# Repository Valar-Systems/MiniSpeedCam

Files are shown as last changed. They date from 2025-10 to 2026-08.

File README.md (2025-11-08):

# MiniSpeedCam

## Intro
The MiniSpeedCam tracks vehicle speeds, takes a photo, and uploads the photo and speed data to a server. Use it to track vehicle speeds on your driveway or street.

**Please sign up to the waitlist at [minispeedcam.com](https://minispeedcam.com/) if you're interested in purchasing one. We have not began manufacturing these yet.**

<div style="text-align: center;">
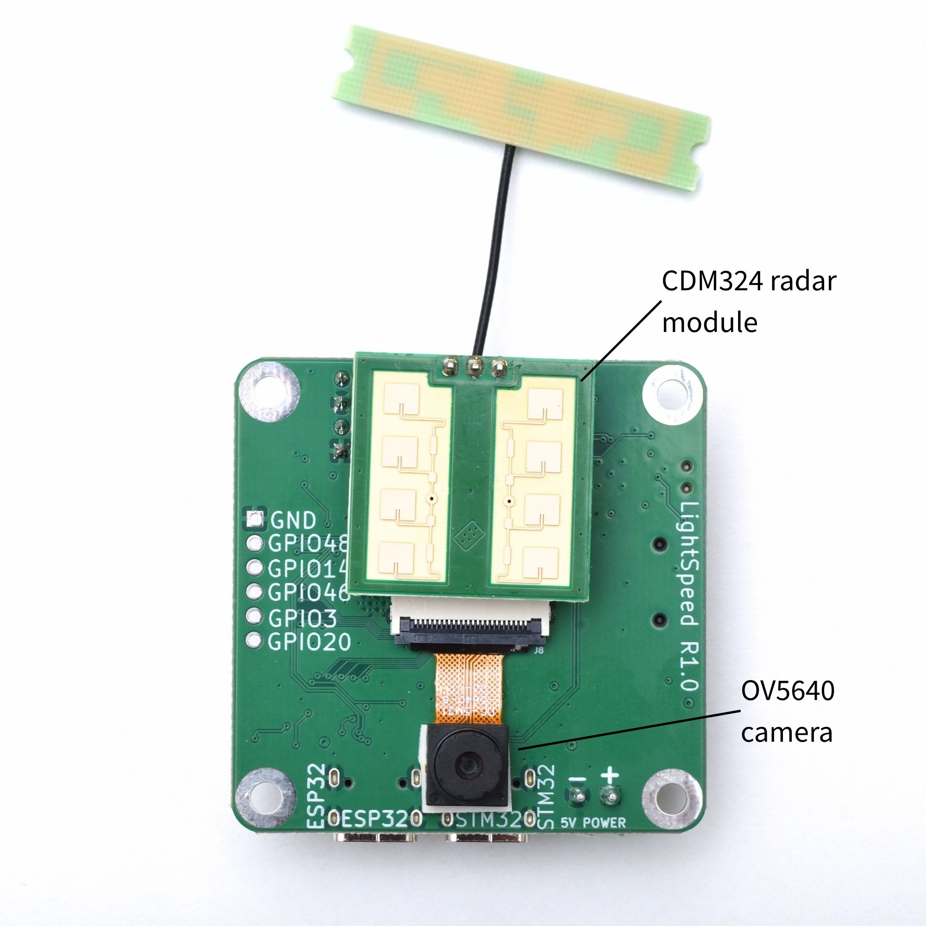
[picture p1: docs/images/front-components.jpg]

</div>
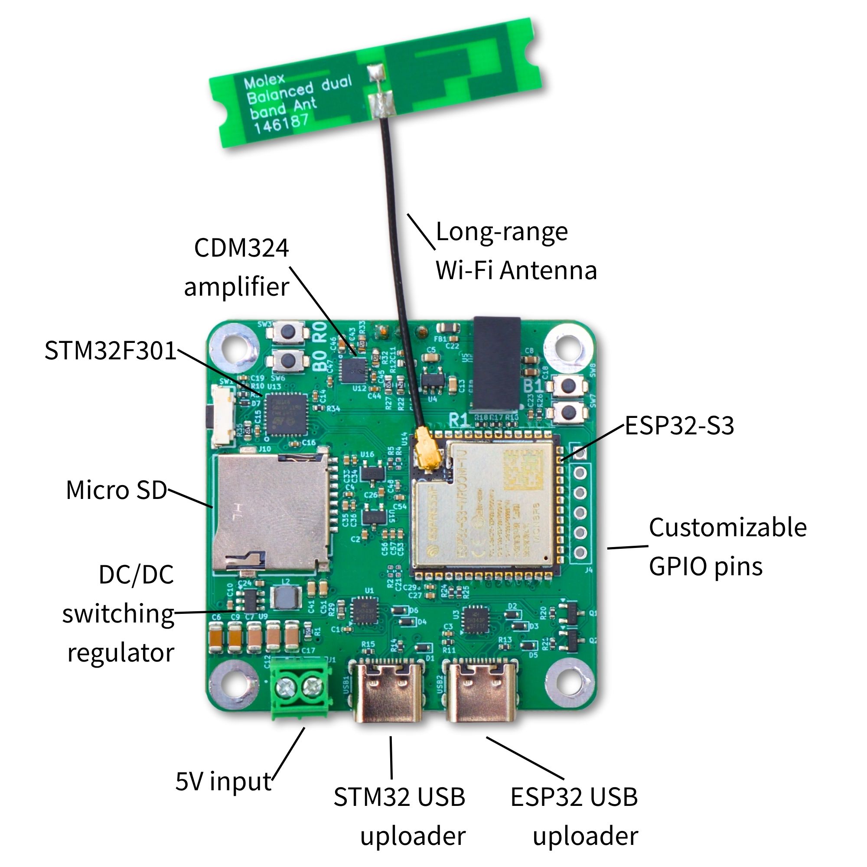
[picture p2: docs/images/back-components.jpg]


The firmware is designed to work with [minispeedcam.com](https://minispeedcam.com/) and requires **absolutely no coding or flashing.** The device works right out of the box.

The device creates a WiFi access point when started for the first time. Connect to it with your phone or laptop and enter your WiFi credentials. It will automatically connect to the internet.

All photos and speed data is sent to your account on [minispeedcam.com](https://minispeedcam.com/) where the data can be viewed and downloaded.

If you prefer to use your own server, just modify the Arduino code to point to wherever you'd like. It's completely open-source.

## Special thanks

This device wouldn't be possible without the help of [Mathieu (aka Limpkin)](https://www.limpkin.fr/index.php?post/2022/03/31/CDM324-Doppler-Motion-Sensor-Backpack%2C-now-with-FFTs%21). Thank you for your CDM324 Backpack and your generous help in getting MiniSpeedCam made.

## Accuracy and distance

A 100Hz frequency from the CDM324 corresponds to 2.3km/h speed. By using a tuning fork, we can trick the radar sensor into picking up a specific speed. Using a tuning fork with a frequency of 2048 Hz should trigger a speed reading of 47.1 kph or 29.3 mph ((2048/100) x 2.3)

[Here's a short video](https://youtu.be/ftSh7Fsy7hw) of the tuning fork in action.

Max distance is about 100ft or 30m

## How it works

The device uses the CDM324 which output a very small voltage, depending on how fast the vehicle is traveling. This voltage is amplified by the aplification circuit and sent to the STM32 for processing. The STM32 uses FFT to determine the speed of the vehicle.

The ESP32 handles the speed data, camera, and WiFi. It is connected to the STM32 via UART and polls it for speed data. Once the speed crosses a threshold that you set, the ESP32 takes a photo and sends a POST API call to a server with the data and image encoded in base64. The vehicles maximum speed, image, and date/time are then saved to a server.

## Battery operation

The device consumes about 1.10W while in full operation, and about 0.55W while in sleep mode. The radar sensor is always on, thus consuming 0.55W at all time. When movement is detected, the ESP32 wakes up from light sleep mode, turns on the camera, connects to wifi, takes a photo, sends the data, and goes back to sleep. The process takes about 10 seconds from start to finish. Battery life will depend on how many vehicles the sensor picks up, thus determing how often the ESP32 wakes up. The more vehicles on the road, the larger the battery drain will be.

## Power source

MiniSpeedCam runs on 5V. There are two USB-C ports and a screw terminal that can be used to supply 5V power. The easiest way to power this device is to use an external battery pack with a USB-C cable and plug it into either USB-C plug.

## Reflashing the device

Flashing the firmware is very simple. The STM32 is programmed in STM32 Cube IDE and the ESP32 is programmed in Arduino IDE.  

#### STM32 flashing

First plug your USB cable into the STM32 USB port. Then use the stm32loader python module directly :

```
pip install stm32loader
```

... then with the USB connected to the device (as it uses RTS/CTS signals to control the MCU nRESET and BOOT0 pins):

```
stm32loader -b 115200 -p com_port -e -w -v -s -f F3 MiniSpeedCam.bin
```

If uploading fails, you may use the STM32 Flash loader after performing the following toggling sequence:

1. Press the R0 button
2. Press the B0 button
3. Release R0
4. Release B0

#### ESP32 flashing

Open the Arduino sketch in ArduinoIDE. Be sure you have the libraries at the top of the sketch installed. And be sure your upload options are set up according to the image file in the ESP32_firmware folder.

Optional: ArduinoOTA is also included, allowing you to remotely flash the device from the ArduinoIDE. One caveat is the ESP32 goes to sleep after 10 minutes of being powered on. Just cycle the power to it and you'll have 10 minutes to upload your sketch.

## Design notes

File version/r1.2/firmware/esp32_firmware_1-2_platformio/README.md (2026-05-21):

# MiniSpeedCam ESP32 Firmware (PlatformIO)

PlatformIO port of the Arduino sketch at
[../esp32_firmware_1-2/esp32_firmware_1-2.ino](../esp32_firmware_1-2/esp32_firmware_1-2.ino).

Functionality is identical; the only changes are project layout (a `src/` tree
with paired `.h`/`.cpp` modules and `extern` globals) so the project builds
under PlatformIO without relying on Arduino IDE's multi-tab `.ino`
preprocessor.

## Layout

```
esp32_firmware_1-2_platformio/
├── platformio.ini      Build environment (board, partitions, lib_deps)
└── src/
    ├── main.cpp        Arduino setup()/loop() + dual-core tasks
    ├── pins.h          GPIO assignments for board revision 1.2
    ├── variables.h     Shared state grouped into POD structs (see below)
    ├── variables.cpp   One-definition home for the struct instances
    ├── camera.{h,cpp}  OV2640 init + JPEG capture (base64-encoded)
    ├── radar.{h,cpp}   UART protocol with the STM32 radar MCU
    ├── api.{h,cpp}     WiFi bring-up + HTTPS uploads to minispeedcam.com
    ├── espui_settings.{h,cpp}  Web-UI controls + NVS persistence
    ├── ota.{h,cpp}     ArduinoOTA listener + transfer-state flag
    ├── diagnostics.{h,cpp}  Boot reason / boot count / uptime / last upload
    └── queue.{h,cpp}   LittleFS-backed offline event queue (retry on WiFi return)
```

### Shared state

Globals live in `variables.h` as five small POD structs, each instantiated
once in `variables.cpp`. The Core 1 (radar) task writes the radar/sleep
side and raises flags on `upload`; the Core 0 (network) task drains them
and consumes `net` for WiFi.

| Instance | Type | Contents |
|---|---|---|
| `radar` | `RadarState` | `speed`, `maxSpeed`, `min_speed`, `photo_speed`, `is_kph` |
| `sleep_gate` | `SleepGate` | post-boot grace + measurement blanking windows |
| `upload` | `UploadJob` | Core 1 -> Core 0 flags + photo payload |
| `net` | `NetConfig` | persisted WiFi creds + camera id + local IP |
| `ui_ids` | `EspuiHandles` | ESPUI control IDs for the credential text inputs |
| `preferences`| `Preferences`  | NVS-backed key/value store |

## Build / flash

```sh
pio run                 # compile
pio run -t upload       # flash over USB
pio device monitor      # 115200 baud
```

## Board options

The defaults in `platformio.ini` target an **ESP32-S3-WROOM-1-N8R8**
(8 MB flash, 8 MB OPI PSRAM). For different modules edit:

| `platformio.ini` key | Typical value |
|---|---|
| `board_build.arduino.memory_type` | `qio_opi` (OPI PSRAM) |
| `board_upload.flash_size` | `8MB` / `16MB` |
| `board_build.partitions` | `default_8MB.csv` (OTA) |

If the board uses the on-chip native USB rather than a USB/UART bridge,
uncomment the `ARDUINO_USB_MODE=1` and `ARDUINO_USB_CDC_ON_BOOT=1`
lines in `build_flags` so the serial console works without an external
adapter.

## Dependencies

Pulled automatically via `lib_deps`:

- `s00500/ESPUI @ 2.2.4` - web configuration portal
- `esp32async/AsyncTCP @ 3.3.8` - async networking (ESPUI dependency)

`esp_camera`, `WiFi`, `WiFiClientSecure`, `HTTPClient`, `Preferences`,
`ESPmDNS`, and `DNSServer` are provided by the `espressif32` platform's
Arduino framework and need no entry.

## Over-the-air updates (ArduinoOTA)

The partition table (`default_8MB.csv`) gives the bootloader two app
slots, `app0` and `app1` (~3.25 MB each), and an `otadata` partition
that records which one is currently active. ArduinoOTA writes the
incoming image into the inactive slot, then flips `otadata` so the
next boot launches the new firmware. NVS sits at the same `0x9000`
offset as the previous `huge_app.csv` layout, so stored WiFi
credentials survive the partition-table switch the first time.

**Pushing an update from PlatformIO**

The first flash after switching to this partition table must be over
USB (`pio run -t upload`) because the partition table itself changes.
After that, push subsequent firmware images over the LAN:

```sh
# Discoverable as MiniSpeedCam.local once mDNS is up
pio run -t upload --upload-port MiniSpeedCam.local
# Or by IP if mDNS isn't reachable:
pio run -t upload --upload-port 192.168.1.42
```

PlatformIO auto-detects ArduinoOTA from the `.local` / IP form and
calls `espota.py` under the hood. Use the same password defined by
`OTA_PASSWORD` (default `minispeedcam`); set
`upload_flags = --auth=<password>` in `platformio.ini` to bake it into
the upload command. To change the password:

```ini
build_flags  = ... -DOTA_PASSWORD=\"my-secret\"
upload_flags = --auth=my-secret
```

**Behaviour during a transfer**

When `ArduinoOTA.onStart` fires, [ota.cpp](src/ota.cpp) sets the global
`g_ota_in_progress` flag and calls `esp_camera_deinit()` to release the
camera driver's DMA descriptors and PSRAM framebuffer. The radar task
(Core 1) and the upload task (Core 0) both check that flag at the top
of their loops and back off so they don't fight the flash writer for
memory or bandwidth. When the transfer finishes the library calls
`ESP.restart()`, which brings up the new image with a clean camera
init via the normal `setup()` path.

## Photo upload path

The speeding-event photo POST never materialises the encoded JPEG in
regular heap. Capture leaves the JPEG in the camera driver's PSRAM
framebuffer; an opaque pointer lives in an atomic slot owned by
[camera.cpp](src/camera.cpp). The Core 0 uploader feeds the framebuffer
into a `StreamingUploadBody` (in [api.cpp](src/api.cpp)) that emits the
JSON prologue, on-the-fly base64 chunks of the JPEG, and the JSON
epilogue as `HTTPClient::sendRequest()` pulls ~1.4 KB at a time into
its TCP write buffer. Peak heap during upload is therefore dominated
by the TCP buffer plus a couple of short Strings, not the photo.

Each upload now also carries an `event_time` epoch field (seconds since
1970, UTC). NTP sync is kicked off after every successful STA
association via `pool.ntp.org`; until the first NTP packet lands, the
field is sent as `0` and the server falls back to receive-time.

## Offline event queue

When the live upload path can't deliver an event (no WiFi, transient
server error, rate-limit), the JPEG + metadata is written to LittleFS
under `/queue/NNNNNNNN.bin` via [queue.cpp](src/queue.cpp). On every
Core 0 iteration (throttled to ~30 s) and on every WiFi reconnect, the
queue is drained oldest-first; events that POST successfully are
deleted, the first failure aborts the drain so we don't hammer a
broken endpoint. The queue lives in the 1.5 MB `spiffs` partition
reserved by `default_8MB.csv`, giving room for ~15 full-resolution
JPEGs of typical size.

The Status tab in the web UI shows the pending queue depth so you can
tell at a glance whether the device is keeping up with delivery.

## Web UI

Three tabs at the device's IP (`MiniSpeedCam.local` over mDNS):

- **Device** - MPH/KPH switch, min speed, photo speed, *Service Mode*
  (keep awake / no sleep so OTA stays reachable), JPEG quality (0-63),
  Frame size (QVGA through UXGA).
- **Wifi Settings** - Network SSID / password, Camera ID, OTA password,
  Clear Settings, Save Settings (reboots).
- **Status** - Live diagnostics, refreshed ~1 Hz from `taskCore0`:
  current speed, free heap and PSRAM, uptime, WiFi RSSI and IP, last
  upload HTTP code, pending queue depth, last reset reason, boot count.

## Power management

When neither *Service Mode* is on nor the post-boot grace window is
active, the firmware enters `esp_light_sleep_start()` after 5 s of zero
radar activity. Before each sleep the OV2640 is fully released
(`esp_camera_deinit()` + PWDN high) so the sensor draws no current
during sleep; on wake (ESP_WAKEUP_PIN going high), the camera is
re-initialised. Combined with WiFi being torn down across sleep
cycles, idle current drops substantially compared to the previous
"sleep but leave the camera live" path.

## TLS

`api.cpp` defines a `kCaRootCert` string; if non-empty it is fed to
`WiFiClientSecure::setCACert()` so HTTPS uploads validate against the
pinned root. Out of the box it is empty, falling back to
`setInsecure()` (the legacy behaviour). To enable validation, paste
the PEM-encoded root that signs `minispeedcam.com` over the placeholder
and rebuild. Fetch it with:

```sh
openssl s_client -connect minispeedcam.com:443 -showcerts < /dev/null
```

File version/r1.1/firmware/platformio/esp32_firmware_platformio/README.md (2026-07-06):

# MiniSpeedCam ESP32 Firmware r1.1 (PlatformIO)

PlatformIO port of the Arduino sketch at
[../esp32_firmware/esp32_firmware.ino](../esp32_firmware/esp32_firmware.ino).

Functionality is identical to the original sketch. The only change is project
layout: the sketch body becomes `src/main.cpp` and the original multi-tab
header modules move under `src/` unchanged. They are still compiled as a
single translation unit (`main.cpp` `#include`s them in the same order the
Arduino IDE concatenated the `.ino` tabs), so there is no behavioural
difference — this is purely so the project builds under PlatformIO without
relying on the Arduino IDE's `.ino` preprocessor.

> For the newer, fully-modularised layout (paired `.h`/`.cpp`, `extern`
> globals, OTA, offline queue, diagnostics) see
> [../../../r1.2/firmware/esp32_firmware_1-2_platformio](../../../r1.2/firmware/esp32_firmware_1-2_platformio).

## Layout

```
esp32_firmware_platformio/
├── platformio.ini          Build environment (board, partitions, lib_deps)
└── src/
    ├── main.cpp            GPIO/pin defines + setup()/loop() + dual-core tasks
    ├── config.h            Bearer token + optional TLS root cert (build-flag overridable)
    ├── variables.h         Shared state + the Core 1 -> Core 0 upload queue
    ├── camera.h            OV2640 init + JPEG capture (framebuffer kept for streaming)
    ├── radar.h             UART protocol with the STM32 radar MCU
    ├── api.h               WiFi bring-up + streaming HTTPS upload to minispeedcam.com
    ├── diagnostics.h       Reset reason / boot count / uptime / last-upload code
    ├── camera_stream.h/.cpp  Temporary MJPEG "aiming" stream (esp_http_server on :81)
    └── config_portal.h     Self-hosted web config page (esp_http_server on :80) + JSON API + NVS persistence
```

## Build / flash

```sh
pio run                 # compile
pio run -t upload       # flash over USB
pio device monitor      # 115200 baud
```

## Board options

The defaults in `platformio.ini` target an **ESP32-S3-WROOM-1-N8R8**
(8 MB flash, 8 MB OPI PSRAM). For different modules edit:

| `platformio.ini` key | Typical value |
|---|---|
| `board_build.arduino.memory_type` | `qio_opi` (OPI PSRAM) |
| `board_upload.flash_size` | `8MB` / `16MB` |
| `board_build.partitions` | `huge_app.csv` (3 MB app) |

If the board uses the on-chip native USB rather than a USB/UART bridge,
uncomment the `ARDUINO_USB_MODE=1` and `ARDUINO_USB_CDC_ON_BOOT=1` lines in
`build_flags` so the serial console works without an external adapter.

## Dependencies

Pulled automatically via `lib_deps`:

- `bblanchon/ArduinoJson @ ^7.2.0` - config portal `/api/state` JSON + POST bodies, and the OTA manifest

`esp_camera`, `esp_http_server` (both HTTP servers — config portal :80 and
aiming stream :81), `WiFi`, `WiFiClientSecure`, `HTTPClient`, `Preferences`,
`ESPmDNS`, `DNSServer`, and `SPIFFS` are provided by the `espressif32`
platform's Arduino framework and need no entry. The JPEG is base64-encoded
with the core's `base64::encode()` (`cores/esp32/base64.h`), so no base64
library is required either. There is no ESPUI / ESPAsyncWebServer / AsyncTCP
dependency — the config page is hand-rolled HTML served from flash.

## Configuration

Deployment values live in [src/config.h](src/config.h) and can be overridden
at build time (so you don't have to edit source) via `build_flags` in
`platformio.ini`:

| Macro | Default | Purpose |
|---|---|---|
| `API_BEARER_TOKEN`  | the shared minispeedcam.com key  | `Authorization: Bearer` token for the uploads |
| `API_CA_ROOT_CERT`  | empty | PEM root cert for TLS validation |

```ini
build_flags =
    ...
    -DAPI_BEARER_TOKEN=\"my-token\"
```

**TLS:** with `API_CA_ROOT_CERT` empty, HTTPS uploads use `setInsecure()`
(no certificate validation — the original behaviour). Paste the PEM root that
signs `minispeedcam.com` into `config.h` (or pass it via the build flag) to
enable validation:

```sh
openssl s_client -connect minispeedcam.com:443 -showcerts </dev/null
```

The default token is a shared Bubble.io workflow key, not a per-device secret;
it already exists in this repo's git history, so rotate it server-side if it
ever needs to be private.

## Capture & upload path

Core 1 (radar) and Core 0 (network) hand work off through a FreeRTOS queue
(`uploadQueue`) rather than polled flags:

1. While a vehicle is in range (`speed >= min_speed`), Core 1 tracks the run's
   max speed and, once `maxSpeed >= photo_speed`, captures **one** JPEG and
   keeps its PSRAM framebuffer.
2. When the run ends, Core 1 posts a single `UploadRequest{speed_actual,
   has_photo, fb}` to the queue.
3. Core 0 blocks on the queue, then POSTs to `server_capture`. When a photo is
   attached it is base64-streamed straight from the framebuffer by
   `StreamingUploadBody` (an `Arduino Stream` feeding
   `HTTPClient::sendRequest`), so the ~200 KB encoded image is never buffered
   in heap. Core 0 then returns the framebuffer.

Every run uploads exactly once: a full photo POST when speeding, or a short
speed-only POST otherwise (the `send_photo` JSON field tells the server which).
The camera is configured with `fb_count = 2` so Core 1 can capture a new frame
while Core 0 is still streaming the previous one.

## Web UI

Self-hosted config page at the device's IP (`MiniSpeedCam.local` over mDNS),
served from flash by `esp_http_server` on port 80 (`config_portal.h`):

- **Device** — live Current Speed readout, MPH/KPH switch, Power-Saver Mode
  switch (drop WiFi when idle vs. never sleep), minimum speed, photo speed, and
  the proximity/photo-signal thresholds.
- **Aiming stream** — toggle the temporary MJPEG video feed (port 81) for
  mounting.
- **WiFi & data server** — Network SSID / password, Data Server API base URL,
  Save (reboots), Clear Settings (reboots into the setup AP).
- **Status** — live diagnostics: signal (proximity), free heap and PSRAM,
  uptime, WiFi RSSI and IP, last upload HTTP code, last reset reason, boot
  count, firmware versions, and OTA status.

There is no server-side push: the page polls `GET /api/state` (~1 Hz) for all
live values and writes settings back via small JSON `POST` endpoints
(`/api/settings`, `/api/wifi`, `/api/clear`, `/api/stream`). That replaced the
old ESPUI WebSocket broadcast from `taskCore1`, whose AsyncTCP send blocked the
radar task and froze the device under WiFi/stream load.

### `GET /api/events` — recent detections for LAN companions

A read-only feed of the most recent passes, so a display on the same network can
show recent speeds without the cloud (`events.h`, an in-RAM ring written at
run-end). The reference consumer is the Blipscope **Speedscope** edition. Shape:

```json
{ "kph": false, "count": 2,
  "events": [ { "speed": 31, "ageSec": 4, "mag": 1200, "dir": 1 },
              { "speed": 24, "ageSec": 47, "mag": 780, "dir": 2 } ] }
```

Newest first; `speed` is a whole number in the device's configured unit (`kph`
flag), `ageSec` is seconds since the pass (this board has no RTC — use it with
your own clock for absolute times), and `dir` is `0` unknown / `1` approaching /
`2` receding. CORS-open (`Access-Control-Allow-Origin: *`).

## Power management

**Power-Saver Mode** (Device tab, persisted in NVS, default **on**) gates the
radar loop's two idle paths: after the post-boot grace window, and after 5 s of
zero radar activity, the device drops WiFi (`WiFi.disconnect` + `WIFI_OFF`).
Turn it **off** to keep the device permanently awake with WiFi up (e.g. while
configuring or debugging) — toggling it off also triggers an immediate
reconnect so the web UI comes straight back. `esp_light_sleep_start()` is still
commented out in `taskCore1`, so today the saving is WiFi-off only.

## TODO

### Verify before relying on this build
- [ ] Hardware smoke-test the capture/upload path: confirm a speeding pass
      produces a well-formed streamed photo POST, and a pass between
      `min_speed` and `photo_speed` produces a valid speed-only POST.
- [ ] Confirm the `capture` endpoint accepts speed-only events (no `photo`
      object). Behaviour changed: **every** pass now uploads, not just speeding
      ones — gate the enqueue on `has_photo` in `taskCore1` if that's unwanted.

### Open decisions / known gaps
- [ ] Captive DNS is never started — `dnsServer.processNextRequest()` runs but
      `dnsServer.start(DNS_PORT, "*", apIP)` is never called, so the AP-mode
      portal redirect is inactive. Wire it up in `connectWifiAP()` or remove the
      unused `DNS_PORT`/`apIP`.
- [ ] Post-boot grace window: code uses `millis() + 10000` (10 s) while comments
      say 120 s — pick one and align code + comments.
- [ ] `speed`/`maxSpeed` are `int`, so `get_speed()`'s float is truncated.
      Decide whether sub-unit precision should be sent (server-contract change).
- [ ] Confirm `WIFI_RESET_PIN` needs the internal pull-up (now `INPUT_PULLUP`)
      vs. an external one on the board.

### Security
- [ ] Rotate the bearer token (it exists in git history) and/or supply it only
      via the `API_BEARER_TOKEN` build flag.
- [ ] Enable TLS validation by setting `API_CA_ROOT_CERT` (currently falls back
      to `setInsecure()`).

### Possible backports from r1.2
- [ ] OTA updates (ArduinoOTA + dual-app `default_8MB.csv` partition; pause the
      camera during a transfer).
- [x] Power-Saver Mode switch — toggle WiFi-drop on idle vs. never sleep
      (persisted, with immediate reconnect on disable). *(done)*
- [ ] Power management, deeper: re-enable `esp_light_sleep_start()` and
      `esp_camera_deinit()` on idle (still commented out in `taskCore1`), gated
      by the same Power-Saver Mode flag.
- [ ] Offline event queue (LittleFS) with retry, so a capture survives a failed
      upload / WiFi outage instead of being lost.
- [ ] UI-tunable camera (frame size / JPEG quality) in the Device tab.
- [x] Live diagnostics Status tab (heap, PSRAM, uptime, RSSI, IP, last upload,
      reset reason, boot count). *(done)*

### Maintenance
- [ ] Decide whether to port these fixes back into the original Arduino-IDE
      sketch at `../esp32_firmware/esp32_firmware.ino`.

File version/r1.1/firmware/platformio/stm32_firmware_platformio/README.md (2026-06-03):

# MiniSpeedCam STM32 firmware — PlatformIO port

This is a [PlatformIO](https://platformio.org/) build of the MiniSpeedCam
firmware for the **STM32F301K8U6** (Cortex-M4F, 64 KB Flash / 16 KB RAM),
ported from the original STM32CubeIDE project in [`../stm32_firmware`](../stm32_firmware).

It is functionally identical: the same application code, ST HAL drivers,
CMSIS-DSP, FatFs middleware, startup file and linker script are used. Only the
build system changed.

## Why a framework-less build

The project is configured **without** PlatformIO's `stm32cube` framework. Instead
it vendors the exact sources from the CubeIDE project. This guarantees the build
uses the same known-good HAL/CMSIS/DSP versions as the original — no risk of a
framework version mismatch or duplicate-symbol conflicts. PlatformIO only
provides the GNU Arm toolchain and orchestrates the build.

## Usage

```sh
pio run            # build  -> .pio/build/genericSTM32F301K8/firmware.{elf,bin,hex}
pio run -t upload  # flash via ST-Link (default)
pio run -t clean   # clean
pio run -t size    # memory usage
```

First run downloads the `toolchain-gccarmnoneeabi` package automatically.

## Layout

| Path | Origin |
|---|---|
| `Core/` | Application + CubeMX-generated code (`main.c`, IT handlers, MSP, syscalls, startup) |
| `Drivers/` | ST STM32F3xx HAL driver + CMSIS core/device + CMSIS-DSP |
| `FATFS/`, `Middlewares/` | FatFs glue layer and middleware |
| `STM32F301K8UX_FLASH.ld` | Original CubeIDE linker script (64 KB Flash / 16 KB RAM) |
| `boards/genericSTM32F301K8.json` | Custom board definition (the F301K8 is not a built-in PlatformIO board) |
| `link_flags.py`  | Mirrors the FPU / float-ABI / libc-specs flags onto the link stage |
| `platformio.ini` | Build configuration (flags & defines match the CubeIDE project verbatim) |

## Build configuration notes

- **MCU defines:** `USE_HAL_DRIVER`, `STM32F301x8`
- **CMSIS-DSP:** `ARM_MATH_CM4` plus the same `ARM_*_TABLES` config defines as the
  original project, so only the FFT/twiddle tables actually used are linked in.
- **ABI:** `-mcpu=cortex-m4 -mfpu=fpv4-sp-d16 -mfloat-abi=hard -mthumb` (hard float),
  `--specs=nano.specs --specs=nosys.specs`, `-Os`.

The original project (CubeIDE) remains untouched in `../stm32_firmware`; both can
coexist.

## Memory footprint (-Os)

```
Flash: ~44.6 KB / 64 KB  (~68%)
RAM:   ~15.7 KB / 16 KB  (~96%, incl. 0x200 heap + 0x400 stack reservation)
```

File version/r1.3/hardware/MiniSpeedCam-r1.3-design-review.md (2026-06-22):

# MiniSpeedCam r1.3 — PCB Design Review

**Valar Systems — Hardware Engineering** · Doc MSC-R1.3-DR-001 Rev A · 2026-06-22 · **CONFIDENTIAL**

Radar speed-camera motherboard (ESP32-S3 + STM32F301 + CDM324 24 GHz Doppler) · 4-layer, 50 × 50 mm
Repo: `Valar-Systems/MiniSpeedCam @ version/r1.3` · Method: kicad-happy analyzer suite

| Components | Stack | Routed | EMC risk | Errors / Warnings |
|---|---|---|---|---|
| 84 | 4-layer (F / GND / PWR / B), 1.6 mm | 100% | 13 / 100 | 7 / 31 |

---

## 1. Scope & Method

The open-source [kicad-happy](https://github.com/aklofas/kicad-happy) analyzer suite was run against the r1.3 KiCad source
(`version/r1.3/hardware/pcb/kicad/MiniSpeedCam-r1.3.{kicad_sch,kicad_pcb}`), and the results were triaged by hand against the raw
netlist. Findings carry the analyzer rule IDs.

| Analyzer | Status | Result |
|---|---|---|
| analyze_schematic.py | RAN | 84 parts, 92 nets, 36 unique — 1 error / 5 warnings / 37 info |
| analyze_pcb.py --full | RAN | 4-layer, 50×50 mm, fully routed (0 unrouted) — 6 errors / 26 warnings / 50 info |
| cross_analysis.py | RAN | 5 plane-integrity findings (GND / 3V3 fragmentation) |
| analyze_emc.py (US market) | RAN | 61 findings, EMC risk 13/100 (conservative) |
| analyze_gerbers.py | **SKIPPED** | **No Gerber/drill set exported yet** — copper/aperture/drill DFM not yet checked (release gate, see §6) |
| Datasheet verification | PARTIAL | Front-end supply/ground pins confirmed against the netlist (§7); op-amp signal-pin order is a designer check |
| analyze_thermal.py | PARTIAL | Ran, but no power-budget input → junction temps not computed |
| SPICE | SKIPPED | No simulator on host |

Layer stack: `F.Cu` / `In1.Cu = GND plane` / `In2.Cu = power plane` / `B.Cu`, 1.6 mm.

## 2. Executive Summary

The board is complete, fully routed, and mechanically tidy on a 50 × 50 mm 4-layer stack. The issue that matters most clusters around
one theme: **the sensitive 24 GHz Doppler analog front-end is not isolated from the digital/RF noise of the ESP32-S3.** The radar
amplifiers run from the digital `3V3` rail and reference the digital ground, and the isolated DC-DC that feeds the radar has its
secondary ground bonded straight back to digital `GND`. This is the kind of coupling that forces firmware-side mitigation — the
current firmware blanks the radar during WiFi bursts and runs WiFi at reduced TX power to keep readings usable. Fixing it in hardware
is the highest-value content for this board.

There is also **one power-architecture item worth a deliberate decision** (§3.2): **three power sources — the Phoenix inlet J1, the
barrel jack DC1, and USB-C VBUS (USB2) — land directly on the `5V` net** with no ORing / reverse-blocking shown. If two can be plugged
at once, that's a back-feed / contention path. The rest are standard pre-fab DFM and EMC hygiene items.

> **Top priority** — Give the radar amplifier chain (U4 LMP7731, U12 MAX9814) a dedicated low-noise analog supply and a single-point
> analog ground, instead of the shared digital `3V3` / `GND`. This is the change most likely to remove the need for firmware
> radar-blanking and let WiFi TX power return to full range.

## 3. Priority Findings

### 3.1 Radar Front-End Shares the Digital Supply & Ground (HIGH)

```
RADAR SUPPLY  [GOOD: dedicated, filtered diode rail]
  5V -> U5 B0505S (isolated DC-DC) -> +Vo (pin4)
        -> FB1 ferrite -> C22 bulk -> CDM324 V+

RADAR SIGNAL  [uV signal amplified on the noisy digital rail]
  CDM324 IF out -> C11/R12 (AC couple)
    -> U4 LMP7731 (gain)   [U4.5 (V+)  = 3V3]
    -> U12 MAX9814 (AGC)   [U12.2/5 (VDD) = 3V3]
    -> ADC

GROUND: single GND net (no analog island); U5 secondary 0V tied to GND
```

| Observation | Evidence (netlist) | Severity |
|---|---|---|
| Doppler amplifiers on shared digital rail | `U4.5 (V+) → 3V3` and `U12.2/5 (VDD) → 3V3` — the same rail the ESP32-S3 / STM32 logic runs on. `3V3` is sourced from the **U9 AP63203 *switching* regulator**, so the amps see switching ripple as well as WiFi-TX transients. Supply pins confirmed (§7). | **HIGH** |
| Isolated converter ground bonded to digital ground | `U5.1 (−Vin) → GND` and `U5.3 (0V) → GND`; no analog/isolated ground net exists. The B0505S isolation buys nothing for noise — the radar return shares digital ground. | **HIGH** |
| Diode rail done well | `U5.4 (+Vo) → FB1 → C22` then on to the CDM324 — a separate, ferrite-filtered radar supply. | OK |

**Recommended changes**

- Derive a clean analog rail for U4/U12 from the isolated B0505S `+Vo` via a small **low-noise (high-PSRR) LDO** — explicitly *not*
  the switcher-derived digital `3V3`.
- Give the front-end a local **analog ground island**, tied to digital `GND` at a **single star point** near the STM32 ADC return.
- Decide deliberately whether the B0505S secondary `0V` joins `GND` at one point (quiet) or stays isolated (true isolation). Today it's
  a common-ground bond, giving up most of the part's benefit.

*Note: `VOUT` is the MAX9814 audio output to the ADC, not a supply — so `RS-001 "VOUT has no source"` is a false positive (§8).*

### 3.2 Three Power Sources Merged on `5V` (MEDIUM)

The `5V` net is driven by **three inlets in parallel** — Phoenix `J1.1`, barrel jack `DC1.4`, and USB-C `USB2.VBUS (pins 2/11)` —
plus `U5.+Vin` and the `U9` switcher input all on the same node. The only series parts on the net are `D1` and `R1`.

- If a user can have **USB plugged *and* the barrel jack / Phoenix energized at the same time**, current can back-feed from one source
  into another; at minimum the host USB port sees the external supply on its VBUS.
- **Action:** add ideal-diode ORing or Schottky reverse-blocking per source (or a deliberate "external *or* USB, never both" mechanical
  interlock / 0Ω select). Confirm D1's role — if it's the only reverse protection it should sit on each source, not just the rail.

## 4. Ground / Plane Integrity & EMC

| Rule | Severity | Finding & action |
|---|---|---|
| PS-002 | WARN | `GND` resolves into **5 copper islands, 2 signals crossing (GPIO43, GPIO44)**; `3V3` into **22 islands, 2 crossing**. Verify `In1.Cu` is a continuous ground reference (no traces carved through it) and stitch the pours. 3V3 fragmentation matters because the analog amps reference 3V3. |
| GP-001 | ERROR (×2) | Two signals cross a significant reference-plane gap (plus several partial). Reroute to avoid the void, or add a bridge cap if a split is intentional. |
| RP-001 | ERROR (×2) | `CAM.PCLK` and `CAM.XCLK` change layers with **no return-path stitching via** (plus ~20 warning-level nets: camera data, UART, BOOT0). Add a ground via at each clock layer-transition. |
| IO-001 | ERROR (×2) | No EMC filtering near the DC inlets / USB. Add TVS + pi/ferrite on the **J1 Phoenix inlet** and the **DC1 barrel jack**; add common-mode choke + ESD on the **USB2** data pair. |
| CK-001 / CK-003 | WARN | Camera `XCLK`/`PCLK` and `SD_HOST_CLK` on outer layers, routed near connectors J8/J10 — move inner-layer or add guard ground. |
| DC-003 | WARN | ~13 decoupling caps (C6/C7/C9/C11/C12/C17/C42…) far from their plane via — shorten cap→via path to cut PDN inductance. |

EMC pre-compliance score **13/100** (conservative) — the analog-isolation and I/O-filtering gaps dominate.

## 5. DFM / Assembly

| Rule | Severity | Finding & action |
|---|---|---|
| FD-001 | ERROR | **No fiducials** either side (fine-pitch QFN present) — add ≥3 global fiducials. |
| PM-002 | ERROR | **C6 and FB1 sit 0.25 mm from board edge** — move in ≥0.5 mm (crack risk on depanel). J1/J3 overhang is intentional edge-mount; J4 at 0.52 mm is borderline. |
| TE-001 | WARN | **0 test points / 91 nets.** Add TPs on every rail, the radar analog output, and GND scope points. |
| DFM-001 | WARN | 0.1 mm / 0.116 mm trace+space forces JLC **advanced** tier. Relax non-camera nets to 0.127 mm to drop to standard if cost matters. |
| PM-001 | WARN | Courtyard overlaps (U15/C2, U16/C26, U15/C56) — decoupling caps deliberately under their LDOs; confirm and waive. |
| TV-001 | WARN | STM32 (U13) thermal pad has 5/9 recommended vias — top up to 9 (minor). |
| SS-001 | ERROR | MPN coverage **3/36 unique parts (8.3%)** in symbols — pre-fab sourcing blocker. Populate MPN fields from the LCSC numbers already in the symbols' `lcsc` property. |

## 6. Schematic / Release Items

| Rule | Severity | Finding & action |
|---|---|---|
| NT-001 | WARN | STM32 `U13.PA2` and `U13.PA3` are **single-pin (floating) bidirectional nets** — add wires or no-connect flags so ERC is clean and the pins aren't left undefined. |
| RS-001 / pwr_flag | WARN | `5V` (and `1V2` / `2V8` / `3V3`) carry power_in pins but have no `PWR_FLAG` / power_out — ERC housekeeping; add a `PWR_FLAG` on the inlets. |
| GERBER | GATE | **No Gerber/drill set committed.** Export the fab package and re-run `analyze_gerbers.py` before release — copper/aperture/drill DFM is otherwise unverified. |

## 7. Datasheet Verification

| Part | Pin checked | Result | Basis |
|---|---|---|---|
| U5 B0505S-1W | 1=−Vin, 2=+Vin, 3=−Vout(0V), 4=+Vout | CONFIRMED | Standard B0505S 4-pin isolated DC-DC. `−Vin` and `0V` both on `GND` verified in netlist. |
| U12 MAX9814 | 5=VDD, 6=MICOUT, 8=MICIN, GND=4/7/9/10/11/15 | CONFIRMED | MAX9814 14-pin TDFN. `VDD → 3V3` verified. |
| U4 LMP7731 | 5 = V+ | CONFIRMED | Pin 5 = V+ for SOT-23-5 single op-amp. `V+ → 3V3` verified. |
| U4 LMP7731 | 1–4 = OUT/+IN/−IN order | **DESIGNER CHECK** | Symbol uses standard SOT-23-5 order (1=OUT, 2=V−, 3=+IN, 4=−IN). Confirm visually against the LMP7731 connection diagram before fab. Not a flagged discrepancy. |

## 8. Triaged as False-Positive / Expected (no action)

- `RS-001` on `VOUT` — `VOUT` is the MAX9814 audio output to the ADC, not a power rail.
- `CC-002` (~18×) "narrow signal" on camera / I²C nets — 0.1 mm is fine for low-current signals.
- `PM-001` courtyard overlaps (U15/C2, U16/C26, U15/C56) — decoupling caps deliberately under their LDOs.
- `DP-004` USB diff pair on outer layer — acceptable for this short full-speed run.

## 9. Review Gaps & Confidence

- **No Gerber check** (none exported) — copper / aperture / drill DFM not positively cleared.
- **No SPICE simulation** (no simulator on host): front-end gain/AGC/filter cutoffs not numerically verified (RC corners detected: R12/C11 ≈ 72 Hz, R12/C42 ≈ 1.25 MHz).
- **Thermal inconclusive:** no power-budget data, so junction temps not computed. Unlikely a blocker, but not positively cleared.
- **Datasheet sync partial:** front-end supply/ground pins verified; LMP7731 I/O pin order and the STM32/ESP pin maps not exhaustively checked against rendered figures.

> **Bottom line:** the board is electrically functional and fully routed, but its radar receive path is coupled to the digital domain
> through both supply (`3V3`) and ground. Fixing that — a dedicated low-noise analog rail + single-point analog ground for U4/U12, a
> continuous ground reference, and basic I/O filtering — is the highest-value work, and directly targets the noise problem the firmware
> is currently working around. Before fabricating, also close the 3-source `5V` merge (§3.2), export a Gerber set, and clear the
> standing DFM gates (fiducials, edge clearance, test points, MPN coverage).

---

*Generated with the kicad-happy analyzer suite. Rule IDs reference kicad-happy detectors. Findings are engineering guidance for human
review, not a substitute for DRC/ERC sign-off or full datasheet verification.*

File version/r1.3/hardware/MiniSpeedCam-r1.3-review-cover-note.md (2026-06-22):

Subject: MiniSpeedCam r1.3 — PCB design review

Hi [name],

I ran an automated design-review pass over the r1.3 KiCad files (schematic + layout) and triaged
the results by hand. Full report attached (PDF) — here's the short version so you can decide where
to push back.

The board is complete, fully routed, and mechanically clean on the 50×50 mm 4-layer stack. One
theme dominates and is worth a real conversation:

  The 24 GHz Doppler analog front-end shares the digital supply and ground with the ESP32-S3.
  - The radar amplifiers (LMP7731 + MAX9814) are powered from the digital 3V3 rail, which is
    sourced from a switching regulator.
  - The isolated DC-DC (B0505S) that feeds the radar has its secondary ground tied straight back
    to digital GND, so its isolation isn't actually doing anything for noise.

  This is the kind of coupling that forces firmware-side mitigation — today the firmware blanks the
  radar during WiFi bursts and runs WiFi at reduced TX power. Fixing it in hardware (a dedicated
  low-noise analog rail for the amps + a single-point analog ground) is the highest-value change.

One power-architecture item worth a deliberate decision:
  - Three power sources land directly on the 5V net — the Phoenix inlet, the barrel jack, and USB-C
    VBUS — with no ORing / reverse-blocking that I can see. If two can be plugged at once, that's a
    back-feed path. Suggest ideal-diode ORing or Schottky blocking per source (or a deliberate
    "external OR USB, never both").

Secondary items (standard pre-fab cleanup):
  - No EMC filtering on the DC inlets (Phoenix + barrel jack) or USB — add TVS + ferrite/ESD.
  - Ground/3V3 planes read as fragmented with a couple of signals crossing the gaps; camera clocks
    (XCLK/PCLK) change layers with no return via. Worth a plane-integrity + stitching pass.
  - DFM: no fiducials, no test points, two parts (C6, FB1) sit ~0.25 mm from the board edge, and
    U13's thermal pad has 5/9 vias.
  - BOM: only 3/36 parts carry MPNs in the symbols (LCSC numbers are in the symbol property) — a
    documentation gate, not an electrical issue.
  - No Gerber set is committed yet — needs export + a gerber check before release.

Things I could NOT fully verify (so treat with judgement):
  - No Gerbers to check, and no SPICE was run, so front-end gain/filter values aren't simulated.
  - The LMP7731 supply pin is confirmed, but please eyeball the op-amp's input/output pin order
    against the connection diagram. It uses the standard SOT-23-5 layout, so most likely fine.

Happy to walk through any of it. My main ask: does the analog-front-end isolation change fit in
this spin, or do we phase it?

Thanks,
Daniel

---
Attachment: MiniSpeedCam-r1.3-design-review.pdf  (Valar Systems · Doc MSC-R1.3-DR-001 Rev A)

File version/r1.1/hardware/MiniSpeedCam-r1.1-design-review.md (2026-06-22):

# MiniSpeedCam r1.1 — PCB Design Review

**Valar Systems — Hardware Engineering** · Doc MSC-R1.1-DR-001 Rev A · 2026-06-22 · **CONFIDENTIAL**

Radar speed-camera motherboard (ESP32-S3 + STM32F301 + CDM324 24 GHz Doppler) · 4-layer, 50 × 50 mm
Repo: `Valar-Systems/MiniSpeedCam @ version/r1.1` · Method: kicad-happy analyzer suite

| Components | Stack | Routed | EMC risk | Errors / Warnings |
|---|---|---|---|---|
| 94 | 4-layer (F / GND / PWR / B), 1.6 mm | 100% | 10 / 100 | 7 / 32 |

---

## 1. Scope & Method

Produced by cloning the open-source [kicad-happy](https://github.com/aklofas/kicad-happy) review suite and running its
Python analyzers against the **r1.1** KiCad source (`version/r1.1/hardware/pcb/kicad/`). Findings carry analyzer rule IDs
and were triaged by hand against the raw netlist.

| Analyzer | Status | Result |
|---|---|---|
| analyze_schematic.py | RAN | 94 parts, 101 nets, 37 unique — 1 error / 3 warnings |
| analyze_pcb.py --full | RAN | 4-layer, 50×50 mm, fully routed — 6 errors / 26 warnings |
| analyze_gerbers.py | RAN | 11 layers complete, PTH+NPTH — 1 warning |
| cross_analysis.py | RAN | 6 cross-domain findings |
| analyze_emc.py (44 rules) | RAN | 65 findings, EMC risk 10/100 (conservative) |
| Datasheet verification | PARTIAL | Front-end supply/ground pins confirmed (§6); op-amp signal-pin order is a designer check |
| analyze_thermal.py | PARTIAL | Ran, but no power-budget input → junction temps not computed |
| SPICE | SKIPPED | No simulator on host |

Layer stack: `F.Cu` / `In1.Cu = GND plane` / `In2.Cu = split power plane` / `B.Cu`, 1.6 mm.

## 2. Executive Summary

The board is complete, fully routed, and mechanically tidy. The issues that matter cluster around one theme: **the sensitive
24 GHz Doppler analog front-end is not adequately isolated from the digital/RF noise of the ESP32-S3.** This is the electrical
root cause behind the firmware workarounds in the codebase (a radar-blanking handshake that discards FFT frames during every
WiFi burst, plus WiFi TX power reduced to 11 dBm). A final spin should spend its budget here. The rest are standard pre-fab
DFM hygiene items.

> **Top priority** — Give the radar amplifier chain (U4 LMP7731, U12 MAX9814) a dedicated low-noise analog supply and a
> single-point analog ground, instead of the shared digital `3V3` / `GND`. This is the change most likely to remove the need
> for firmware radar-blanking and let WiFi TX power return to full range.

## 3. Priority Finding — Radar Front-End Shares the Digital Supply & Ground

```
RADAR SUPPLY  [GOOD: dedicated, filtered diode rail]
  USB 5V (VUSB)
    -> U5 B0505S (isolated DC-DC) -> +Vo
       -> FB1 ferrite -> CDM324 V+

  U5.1 (-Vin) = GND   and   U5.3 (0V, secondary gnd) = GND
  [isolation collapsed to a common ground]

RADAR SIGNAL  [uV signal amplified on the noisy digital rail]
  CDM324 IF out -> C11/R12 (AC couple)
    -> U4 LMP7731 (gain)   [U4.V+   = 3V3]
    -> U12 MAX9814 (AGC)   [U12.VDD = 3V3]
    -> ADC
```

| Observation | Evidence (netlist) | Severity |
|---|---|---|
| Doppler amplifiers on shared digital rail | `U4.5 (V+) → 3V3` and `U12.5 (VDD) → 3V3` — same rail as ESP32-S3/STM32 logic; a WiFi-TX transient on 3V3 lands in the gain stage. Both supply pins datasheet-confirmed (§6). | **HIGH** |
| Isolated converter ground bonded to digital ground | `U5.1 (−Vin) → GND` and `U5.3 (0V) → GND`; no analog/isolated ground net exists in the design. The B0505S isolation is unused — radar return shares digital ground. | **HIGH** |
| Diode rail done well | `U5.4 (+Vo) → FB1 → J3.3 (CDM324 V+)` with C22 bulk — a separate, ferrite-filtered radar supply. | OK |

**Recommended changes**

- Derive a clean analog rail for U4/U12 from the isolated B0505S `+Vo` via a small **low-noise (high-PSRR) LDO**, not the digital `3V3`.
- Give the front-end a local **analog ground island**, tied to digital `GND` at a **single star point** near the STM32 ADC return.
- If the B0505S stays, decide deliberately whether its secondary `0V` joins `GND` at one point (quiet) or not at all (true isolation). Today it's a common-ground bond, giving up most of the part's benefit.

*Note: `VOUT` is the MAX9814 audio output to the ADC, not a supply — so `RS-001 "VOUT has no source"` is a false positive.*

## 4. Ground & Reference-Plane Integrity

| Rule | Severity | Finding & action |
|---|---|---|
| PS-002 / GP-001 | ERROR | `GND` resolves into **6 copper islands, 2 signals crossing a gap**; `3V3` into **23 islands**, 2 crossing. Verify `In1.Cu` is a continuous ground reference (no traces carved through it) and stitch the pours. 3V3 fragmentation matters here because the analog amps reference 3V3. |
| RP-001 | ERROR | Camera `PCLK` changes layers with **no return-path stitching via**; same for several STM/UART/BOOT0 nets. Add a ground via at each clock layer-transition. |

## 5. EMC Pre-Compliance & DFM

| Rule | Severity | Finding & action |
|---|---|---|
| IO-001 | ERROR | No filtering on **J1 (Phoenix power input), USB1, USB2**. Add TVS + pi/ferrite on the J1 inlet; common-mode choke + ESD on each USB-C data pair. |
| CK-001 / CK-003 | WARN | Camera `XCLK`/`PCLK` and `SD_HOST_CLK` on outer layers, routed near connectors J8/J10 — move inner-layer or add guard ground. |
| DC-003 | WARN | 13 decoupling caps (C6/C7/C9/C12/C17/C42…) far from their plane via — shorten cap→via path to cut PDN inductance. |
| FD-001 | ERROR | **No fiducials** either side (fine-pitch QFN present) — add ≥3 global fiducials. |
| PM-002 | ERROR | **C6 and FB1 sit 0.25 mm from board edge** — move in ≥0.5 mm (crack risk on depanel). J1/J3 overhang is intentional edge-mount — ignore. |
| TE-001 | WARN | **0 test points.** Add TPs on every rail, the radar analog output, and GND scope points. |
| DFM-001 | WARN | 0.1 mm / 0.116 mm trace+space forces JLC **advanced** tier. Relax non-camera nets to 0.127 mm to drop to standard if cost matters. |
| TV-001 | WARN | STM32 (U13) thermal pad has 5/9 recommended vias — top up to 9 (minor). |
| SS-001 | ERROR | MPN coverage 3/37 in symbols. Populate MPN fields from the existing `MiniSpeedCam_BOM.csv` LCSC column — BOM hygiene, not an electrical defect. |

## 6. Datasheet Verification

| Part | Pin checked | Result | Basis |
|---|---|---|---|
| U5 B0505S-1W | 1=−Vin, 2=+Vin, 3=−Vout(0V), 4=+Vout | CONFIRMED | Standard B0505S 4-pin isolated DC-DC pinout. −Vin and −Vout both on `GND` verified. |
| U12 MAX9814 | 5=VDD, 6=MICOUT, 8=MICIN, GND=4/7/11/EP | CONFIRMED | Exact match to documented MAX9814 14-pin TDFN. `VDD → 3V3` verified. |
| U4 LMP7731 | 5 = V+ | CONFIRMED | Pin 5 = V+ for SOT-23-5 single op-amp. `V+ → 3V3` verified. |
| U4 LMP7731 | 1–4 = OUT/+IN/−IN order | DESIGNER CHECK | Symbol uses standard SOT-23-5 order (1=OUT, 2=V−, 3=+IN, 4=−IN). Datasheet figure couldn't be auto-rendered here — confirm visually against the LMP7731 connection diagram before fab. Not a flagged discrepancy. |

## 7. Triaged as False-Positive / Expected (no action)

- `CC-002` (16×) "narrow signal" on camera/I²C nets — 0.1 mm is fine for low-current signals.
- `GR-004` B-paste 26/187 apertures — back side has only 2 components; expected.
- `DP-005` USB diff-pair 7% / 1.3 mm mismatch — negligible at USB full-speed.
- `PM-001` courtyard overlaps (U15/C2, U16/C26, …) — decoupling caps deliberately under their LDOs.
- `RS-001` on `VOUT` — `VOUT` is a signal, not a power rail.

## 8. Review Gaps & Confidence

- **No full datasheet sync.** Front-end supply/ground pins spot-verified (§6); LMP7731 I/O pin order and STM32/ESP pin maps not exhaustively checked against rendered figures.
- **No SPICE simulation** (no simulator on host): gain/AGC/filter cutoffs not numerically verified.
- **Thermal inconclusive:** no power-budget data, so junction temps not computed. Unlikely to be a blocker, but not positively cleared.

> **Bottom line:** r1.1 is electrically functional and routable, but its radar receive path is coupled to the digital domain
> through both supply (3V3) and ground. Fixing that — a dedicated low-noise analog rail + single-point analog ground for U4/U12,
> a continuous ground reference, and basic I/O filtering — is the highest-value content for a final spin and directly targets
> the noise problem the firmware is currently working around.

---

*Generated with the kicad-happy analyzer suite. Rule IDs reference kicad-happy detectors. Findings are engineering guidance
for human review, not a substitute for DRC/ERC sign-off or full datasheet verification.*

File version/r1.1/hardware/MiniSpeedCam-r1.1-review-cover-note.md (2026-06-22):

Subject: MiniSpeedCam r1.1 — PCB design review ahead of the final spin

Hi [name],

Ahead of the last PCB revision, I ran an automated design-review pass over the r1.1 KiCad
files (schematic + layout + gerbers) and triaged the results by hand. Full report attached
(PDF) — here's the short version so you can decide where to push back.

The board is complete, fully routed, and mechanically clean. One theme dominates and is worth
a real conversation:

  The 24 GHz Doppler analog front-end shares the digital supply and ground with the ESP32-S3.
  - The radar amplifiers (LMP7731 + MAX9814) are powered from the digital 3V3 rail.
  - The isolated DC-DC (B0505S) that feeds the radar has its secondary ground tied straight
    back to digital GND, so its isolation isn't actually doing anything for noise.

  This is almost certainly why the firmware has to blank the radar during every WiFi burst and
  run WiFi at reduced TX power. Fixing it in hardware — a dedicated low-noise analog rail for
  the amps + a single-point analog ground — is the highest-value change for the final spin.

Secondary items (all standard pre-fab cleanup):
  - No EMC filtering on the power inlet (J1) or the two USB-C ports — add TVS + common-mode chokes.
  - Ground/3V3 planes read as fragmented with signals crossing the gaps; camera clock changes
    layers with no return via. Worth a quick plane-integrity check.
  - DFM: no fiducials, no test points, and two parts (C6, FB1) sit ~0.25 mm from the board edge.
  - BOM: only 3/37 parts have MPNs in the symbols (the LCSC numbers live in the BOM CSV, not the
    schematic) — a documentation gate, not an electrical issue.

Things I could NOT fully verify (so treat with judgement):
  - No SPICE was run (no simulator on hand), so front-end gain/filter values aren't simulated.
  - The LMP7731 supply pin is datasheet-confirmed, but I couldn't render the datasheet figure to
    confirm the op-amp's input/output pin order — please eyeball that against the connection
    diagram. It uses the standard SOT-23-5 single-op-amp layout, so most likely fine.

Happy to walk through any of it. My main ask for the review: does the analog-front-end isolation
change fit in this spin, or do we phase it?

Thanks,
Daniel

---
Attachment: MiniSpeedCam-r1.1-design-review.pdf  (Valar Systems · Doc MSC-R1.1-DR-001 Rev A)

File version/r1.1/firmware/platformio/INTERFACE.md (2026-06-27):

# MiniSpeedCam — ESP32 ↔ STM32 Interface (HW rev 1.1)

This document describes how the two microcontrollers in the MiniSpeedCam
cooperate and the exact electrical + protocol contract between them. It covers
the PlatformIO firmwares in this folder:

- [`stm32_firmware_platformio/`](stm32_firmware_platformio) — STM32F301K8U6, the radar DSP.
- [`esp32_firmware_platformio/`](esp32_firmware_platformio) — ESP32-S3, the application controller.

## Roles

| MCU | Part | Responsibility |
|-----|---|---|
| **STM32** | STM32F301K8U6 (Cortex-M4F, 64 KB Flash / 16 KB RAM) | Samples the CDM324 Doppler radar's analog output, runs an FFT, and reports the detected speed. Nothing else — no WiFi, no camera. |
| **ESP32** | ESP32-S3-WROOM-1U | Master controller: polls the STM32 for speed, drives the OV2640 camera, hosts the web config portal, manages WiFi/sleep, and uploads photos + speed to the cloud. |

The STM32 is a **slave "speed oracle."** The ESP32 is the master: it resets the
STM32, polls it, and acts on the results.

## Physical block diagram

```
        CDM324 radar (24.125 GHz Doppler)
                 │ analog IF
                 ▼
        ┌──────────────────┐                       ┌──────────────────┐
        │     STM32F301     │                       │     ESP32-S3      │
        │  (radar DSP)      │                       │  (app controller) │
        │                   │                       │                   │
 PB0 ─► │ ADC1_IN11 DOPPLER │                       │                   │
        │                   │   UART1 @ 1 Mbaud 8N1 │                   │
    PA9 │ USART1_TX ────────┼──────────────────────►│ GPIO42  RX        │
   PA10 │ USART1_RX ◄───────┼───────────────────────┤ GPIO41  TX        │
        │                   │                       │                   │
    PA5 │ GPIO_OUT ─────────┼──────────────────────►│ GPIO1   (wake/    │
        │ (motion flag)     │   motion-detected     │          activity)│
        │                   │                       │                   │
   NRST │ ◄─────────────────┼───────────────────────┤ GPIO47  (reset)   │
        │                   │   active-low reset    │                   │
    PA4 │ GPIO_IN  ◄────────┼───────────────────────┤ GPIO2   (radar    │
        │ (radar blank)     │   WiFi-TX blank       │          blank)   │
        └──────────────────┘                        └──────────────────┘
```

## Signal table

| Signal | STM32 pin | ESP32 pin | Dir | Notes |
|---|---|---|-----|---|
| Speed UART TX | `PA9` (USART1_TX) | `GPIO42` (RX) | STM → ESP | 1,000,000 baud, 8N1. Speed replies + boot banner. |
| Speed UART RX | `PA10` (USART1_RX) | `GPIO41` (TX) | ESP → STM | Single-byte query commands. |
| Motion / wake flag | `PA5` (GPIO out) | `GPIO1` (`ESP_WAKEUP_PIN`, in) | STM → ESP | HIGH = a valid (non-zero) speed is being reported; LOW = no motion. ESP firmware interprets this as "~≥5 mph motion." |
| STM32 reset | `NRST` | `GPIO47` (`STM32_RESET_PIN`, out) | ESP → STM | Active-low. ESP pulses low ~20 ms to reset the radar MCU. |
| Radar blank | `PA4` (in, pull-down) | `GPIO2` (`RADAR_BLANK_PIN`, out) | ESP → STM | ESP drives **HIGH** while transmitting a WiFi burst (upload / (re)connect); the STM32 **discards** any FFT frame seen while it's high. Was the reserved `STM_WAKEUP` line. |
| Debug UART (unused by link) | `PA2`/`PA3` (USART2) | — | — | USART2 @ 115200 is initialized on the STM32 but not part of the ESP link (debug header). |

## UART protocol (USART1, 1 Mbaud, 8N1)

Strictly master-polled request/response. The ESP sends one ASCII byte; the STM32
replies with one **checksummed** ASCII line terminated by `\r\n`.

| ESP sends | STM32 replies | Meaning |
|---|---|---|
| `'m'` | `<int>,<mag>*<CK>\r\n` | Latest speed in **MPH × 10** + echo magnitude, checksummed |
| `'k'` | `<int>,<mag>*<CK>\r\n` | Latest speed in **KPH × 10** + echo magnitude, checksummed |
| `'a'` / `'s'` | (raw dump on/off) | Debug: stream raw ADC/FFT buffers (not used in normal operation) |
| `'h'` / `'l'` | — | Debug: enable/disable low-frequency rejection |
| `'d'` | — | Debug: toggle the per-frame `DBG …` diagnostic dump (emitted on **USART2**, not this link) |

- **Reply format:** `<int>,<mag>*<CK>\r\n`, e.g. `298,1024*0E`. `<int>` is
  **speed × 10** (so `298` → 29.8, `<CK>`=`0x18`). `<mag>` is the **clamped FFT peak magnitude**
  (the proximity proxy, `analog_dbg_peak_mag >> 4`, clamped to `[0, 65535]`; `0`
  when the frame failed the SNR gate — i.e. `<mag>` is 0 exactly when `<int>` is).
  `<CK>` is the **XOR of every ASCII char of the `<int>,<mag>` payload — digits
  *and* the comma** — printed as two hex chars. The ESP verifies the checksum in
  [`get_speed()`](esp32_firmware_platformio/src/radar.h) and returns 0 on any
  mismatch. This rejects the dangerous corruption the plausibility ceiling can't
  catch — a flipped bit that lands on another in-range value (e.g. `29` → `79`
  mph). The ESP publishes `<mag>` as `g_last_peak_mag`, which drives the proximity
  gate (`min_signal`) and the direction-aware photo timing (`photo_signal`); a
  reply that omits `,<mag>` (older STM32 firmware) leaves it 0, disabling both.
  The STM32 derives `<int>` from the FFT peak frequency using a CDM324
  calibration constant (≈0.145 for MPH×10, ≈0.226 for KPH×10) — see the command
  handler / `uart_reply_speed()` in [STM32 `main.c`](stm32_firmware_platformio/Core/Src/main.c).

### Important timing/behavior contract

- **The STM32 only answers when it has a fresh sample.** UART commands are serviced
  *inside* the "FFT just completed" branch of the STM32 main loop, and the motion
  flag (`PA5`) is updated only every `FFT_CNT_DISP` (10) completed FFTs. If the ESP
  polls between samples, **there may be no reply.**
- Because of this, the ESP's `get_speed()` waits up to **50 ms** for a reply and
  returns **0** (treated as "no motion") if nothing arrives — it never blocks the
  radar loop on a missing reply.
- The ESP **drains stale RX bytes before each query**, **verifies the reply
  checksum**, and **rejects implausible readings** (negative, or above
  `MAX_PLAUSIBLE_SPEED = 250`) as line noise. RF noise — often from the ESP's own
  WiFi bursts — can inject junk on the UART line; these guards keep it out of the
  trigger/upload path. (This hardening is specific to the PlatformIO firmware; the
  original Arduino sketch lacked it.)
- On the STM32 side, command bytes are received **by interrupt into a ring buffer**
  with a `HAL_UART_ErrorCallback` that clears overrun/framing errors and re-arms —
  so a noise byte during the ~2.4 ms FFT can't overrun the FIFO-less USART and
  permanently deafen the link. An **independent watchdog (IWDG, ~2 s)** resets the
  MCU if the radar loop ever wedges. Neither affects the wire protocol.

## GPIO signaling

### Motion flag — `PA5` → `GPIO1`
A fast hardware "is anything moving?" line, independent of the UART poll. The STM32
drives it **HIGH** whenever the currently reported speed is non-zero (valid), and
**LOW** when no motion is detected. The ESP reads it to gate sleep and
WiFi-reconnect decisions. (Hardware light-sleep wake-on-this-pin is wired but
commented out in rev 1.1, since USB would disconnect on sleep.)

### Radar blank — `GPIO2` (`RADAR_BLANK_PIN`) → `PA4`
A WiFi-TX blanking handshake that attacks the rev-1.1 noise problem at its source.
The ESP32 and CDM324 share a supply rail, so the ESP's WiFi TX current bursts slump
the rail and corrupt the radar reads. The ESP drives this line **HIGH** for the
duration of each WiFi burst it controls — HTTPS uploads (`sendUpload`/`sendLocalIP`)
and WiFi (re)connects (`connectWifi`/`connectWifiAP`) — via a depth-counted
`RadarBlankGuard` so nested calls keep it asserted until the outermost scope exits.
The STM32 reads `PA4` at the top of each FFT frame (`analog_compute_fft_on_cplted_sequence`)
and, when it's high, **discards that frame** (holds the previous median, skips the
FFT). This is a direct "this frame is contaminated" flag — more reliable than
inferring it from the noise statistics. `PA4` has an internal pull-down so it reads
"not blanking" while the ESP is booting / the line floats. The `DBG` diagnostic
dump on USART2 shows `blank=1` on a discarded frame. Was the reserved `STM_WAKEUP`
line.

### Reset — `GPIO47` → `NRST`
The ESP owns the STM32's reset. At boot it pulses `STM32_RESET_PIN` low for ~20 ms
(`issue_cdm324_reset()`), then drains the STM32's boot banner
(`"Connection Successful!"` / `"CDM324-V2 fw v…"`) so it doesn't corrupt the first
`parseFloat()` of a speed reply.

## End-to-end operational flow

1. **Boot:** ESP resets the STM32, drains its banner, joins WiFi (or starts a
   captive-portal AP for configuration), and loads user settings (units,
   `min_speed`, `photo_speed`).
2. **Idle polling:** On Core 1 the ESP polls the STM32 (~10 Hz) for speed and
   watches the motion flag.
3. **Vehicle detected** (`speed ≥ min_speed`): the ESP enters a tracking loop,
   recording the run's `maxSpeed`. When `maxSpeed ≥ photo_speed` it fires the
   OV2640 once.
4. **Vehicle clears** (`speed < min_speed`): the ESP hands off to Core 0, which
   POSTs the base64-encoded JPEG + max speed to the cloud. Core 0 is kept separate
   so the slow HTTPS upload never stalls radar polling on Core 1.

## Quick reference: changing the interface

- **Change the UART baud:** must match on both sides — STM32 `MX_USART1_UART_Init()`
  (`huart1.Init.BaudRate`) in `main.c` **and** `Serial1.begin(...)` in the ESP
  `setup()`.
- **Change a command/units:** edit the STM32 command handler (`'m'`/`'k'` cases) and
  the ESP `get_speed()` together — the `× 10` scaling and unit semantics are a
  shared contract.
- **Change the reply format / checksum:** the `<int>*<CK>\r\n` framing is a shared
  contract — update `uart_reply_speed()` in STM32 `main.c` **and** the line-parse +
  checksum verification in the ESP `get_speed()` together, or replies will be
  rejected as corrupt.
- **Change a pin:** update both the STM32 `.ioc`/`MX_GPIO_Init` (or USART pin
  remap) and the ESP `#define`s near the top of `main.cpp`.

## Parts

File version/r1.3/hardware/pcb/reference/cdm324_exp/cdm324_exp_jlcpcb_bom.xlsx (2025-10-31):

Designator | Comment | Footprint | JLCPCB Part #
C1, C2, C3, C4, C5 | 1uF | Capacitor_SMD:C_0603_1608Metric | C1592
FB1 | FerriteBead | Inductor_SMD:L_0603_1608Metric | C14709
J1, J2 | Conn_02x04_Odd_Even | Connector_PinSocket_2.54mm:PinSocket_2x04_P2.54mm_Vertical | C2685133
J3 | USB_C_Receptacle_USB2.0 | Connector_USB:USB_C_Receptacle_G-Switch_GT-USB-7010ASV | C2988369
J5 | Micro_SD_Card_Det1 | lib:XKTF-015-N | C381082
J7 | AudioJack4 | Connector_Audio:Jack_3.5mm_PJ320D_Horizontal | C431535
R1, R4, R5, R6, R7 | 1k | Resistor_SMD:R_0603_1608Metric | C22548
R2, R3 | 5.1k | Resistor_SMD:R_0603_1608Metric | C105580
R8, R9, R10, R11, R12, R13 | 49k9 | Resistor_SMD:R_0603_1608Metric | C114624
SW1, SW2 | SW_Push | Button_Switch_SMD:SW_Push_1P1T_NO_6x6mm_H9.5mm | C255812
SW3 | SW_DIP_x01 | Button_Switch_THT:SW_DIP_SPSTx01_Slide_9.78x4.72mm_W7.62mm_P2.54mm | C126888
U1 | CH340X | Package_SO:MSOP-10_3x3mm_P0.5mm | C3035748

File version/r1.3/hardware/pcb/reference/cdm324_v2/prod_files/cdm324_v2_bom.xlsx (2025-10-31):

Item # | Qty | Designator | Value | Manufacturer | Manufacturer Part Number | Alternative LCSC part number | Package/Footprint | Digikey Link
1 | 6 | C1, C3, C5, C10, C11, C13 | 22uF | Samsung Electro-Mechanics | CL21A226MOCLRNC | C602037 | 0805 | https://www.digikey.com/product-detail/en/samsung-electro-mechanics/CL21A226MOCLRNC/1276-6780-1-ND/5961639
2 | 1 | C4 | 27pF | YAGEO | CC0603JRNPO9BN270 | C107045 | 0603 | https://www.digikey.com/en/products/detail/yageo/CC0603JRNPO9BN270/302797
3 | 9 | C2, C6, C7, C8, C12, C14, C15, C16, C18 | 470nF | TDK Corporation | C1005X5R1E474K050BB | C92361 | 0402 | https://www.digikey.com/en/products/detail/tdk-corporation/C1005X5R1E474K050BB/2792240
4 | 1 | C9 | 2.2uF | Murata Electronics | GRM188R71A225KE15D | C1607 | 0603 | https://www.digikey.com/en/products/detail/murata-electronics/GRM188R71A225KE15D/1033256
5 | 1 | FB1 | Ferrite_Bead | Laird-Signal Integrity Products | HZ0805D102R-10 | C44838 | 0805 | http://www.digikey.com/product-detail/en/HZ0805D102R-10/240-2397-1-ND/806757
6 | 1 | J2 | Conn_01x03_Female | Sullins Connector Solutions | PPPC031LFBN-RC | C146243 |  | http://www.digikey.com/product-detail/en/sullins-connector-solutions/PPPC031LFBN-RC/S7036-ND/810175
7 | 2 | J4, J5 | Conn_02x04_Odd_Even | Sullins Connector Solutions | PPPC042LFBN-RC | C92271 |  | https://www.digikey.com/en/products/detail/sullins-connector-solutions/PPPC042LFBN-RC/810244
8 | 5 | R1, R4, R8, R9, R10 | 4k7 | YAGEO | RC0603FR-074K7L | C99782 | 0603 | https://www.digikey.com/en/products/detail/yageo/RC0603FR-074K7L/727212
9 | 2 | R2, R7 | 75 | YAGEO | RC0402JR-0775RL | C137841 | 0402 | https://www.digikey.com/en/products/detail/yageo/RC0402JR-0775RL/726505
10 | 2 | R5, R6 | 130k | Panasonic Electronic Components | ERJ-3EKF1303V | C163432 | 0603 | https://www.digikey.com/product-detail/en/panasonic-electronic-components/ERJ-3EKF1303V/P130KHCT-ND/198154
11 | 1 | U1 | LMP7731 | Texas Instruments | LMP7731MF/NOPB | C202252 |  | https://www.digikey.ch/en/products/detail/texas-instruments/LMP7731MF-NOPB/1836050
12 | 1 | U3 | MAX9814 | Analog Devices Inc./Maxim Integrated | MAX9814ETD+T | C41714 |  | https://www.digikey.com/en/products/detail/analog-devices-inc-maxim-integrated/MAX9814ETD-T/1703775
13 | 1 | U4 | NCP163ASN330T1G | onsemi | NCP163ASN330T1G | C603656 |  | https://www.digikey.com/product-detail/en/on-semiconductor/NCP163ASN330T1G/NCP163ASN330T1GOSCT-ND/10233513
14 | 1 | U5 | STM32F301K8Ux | STMicroelectronics | STM32F301K8U6 | C111684 |  | https://www.digikey.com/product-detail/en/stmicroelectronics/STM32F301K8U6/497-17411-ND/5051319
15 | 1 | U6 | PCA8561AHN/AY | NXP USA Inc. | PCA8561AHN/AY | C2653710 |  | https://www.digikey.ch/en/products/detail/nxp-usa-inc/PCA8561AHN-AY/5170024
16 | 1 | U2 | 12PIN TN Positive 4-Digits |  |  |  |  | https://www.aliexpress.com/item/1005003060952508.html
17 | 1 | R3 | 620k | YAGEO | RC0603FR-07620KL | C68737 | 0603

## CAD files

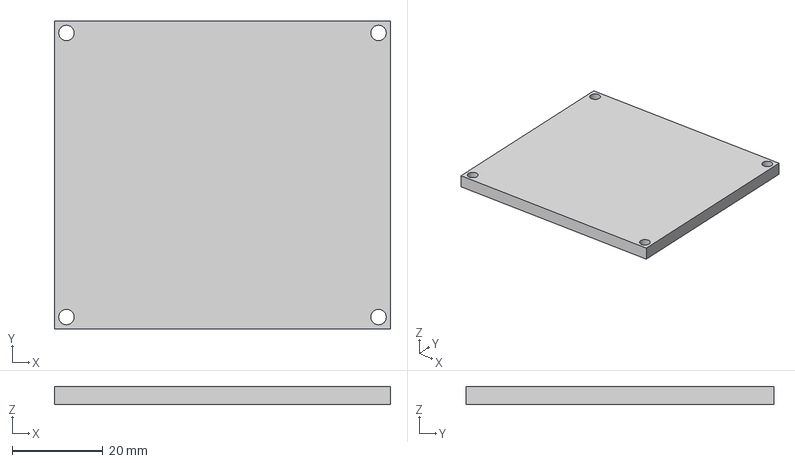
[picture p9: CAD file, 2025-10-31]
version/r1.3/hardware/enclosure/enclosure-top.step
74.0 x 67.8 x 4.00 mm

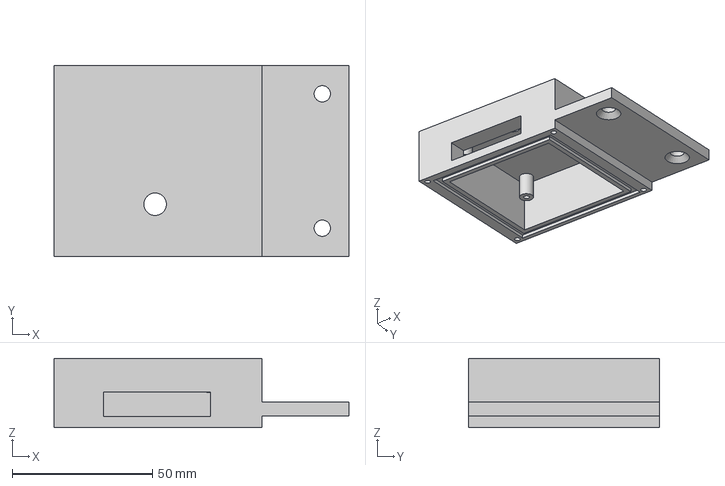
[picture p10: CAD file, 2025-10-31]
version/r1.3/hardware/enclosure/enclosure-bottom.step
105.0 x 67.8 x 24.6 mm

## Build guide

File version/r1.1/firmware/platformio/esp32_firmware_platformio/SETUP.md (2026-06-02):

# MiniSpeedCam — Setup & User Guide

MiniSpeedCam measures the speed of passing vehicles, takes a photo when a
vehicle exceeds the speed you choose, and uploads the photo and speed to your
account at **[minispeedcam.com](https://minispeedcam.com/)**, where you can
view and download the results.

This guide explains how the device works, how to set it up (including linking
it to your minispeedcam.com camera), and what every setting does.

---

## How it works

The device combines three parts:

1. **CDM324 Doppler radar** — outputs a small voltage proportional to a moving
   vehicle's speed. An amplifier circuit boosts that signal.
2. **STM32 microcontroller** — runs an FFT on the amplified radar signal to
   compute the actual speed, and reports it over a serial (UART) link.
3. **ESP32-S3** — the brain. It polls the STM32 for the current speed, hosts the
   configuration web page over WiFi, and when a vehicle's speed crosses your
   **Photo Speed** threshold it captures a JPEG from the camera and POSTs the
   photo + maximum speed to minispeedcam.com.

A typical pass looks like this:

```
Vehicle approaches
   │
   ▼
Radar + STM32 measure speed ──► ESP32 reads speed every loop
   │
   ▼
Speed ≥ Minimum Speed?  ──► start tracking the pass, follow the max speed
   │
   ▼
Max speed ≥ Photo Speed? ──► capture ONE photo
   │
   ▼
Vehicle leaves ──► upload max speed (+ photo if one was taken) to your account
```

Each pass uploads **exactly once**: a photo upload if the vehicle was speeding,
or a short speed-only record otherwise.

---

## What you need

- A MiniSpeedCam device, powered by **5 V** (USB-C, or the screw terminal). The
  easiest option is a USB-C power bank or wall adapter.
- A WiFi network (2.4 GHz) the device can join.
- A free account at **[minispeedcam.com](https://minispeedcam.com/)**.
- A phone or laptop for the one-time setup.

---

## First-time setup

### Step 1 — Create your account and camera

1. Sign up / log in at **[minispeedcam.com](https://minispeedcam.com/)**.
2. **Create a new camera** in your account.
3. **Copy the Camera ID** that minispeedcam.com gives you for that camera. You
   will paste this into the device in Step 4 — this is what links the physical
   device to the camera in your account, so its uploads show up under the right
   camera.

> **Why this matters:** every upload the device sends is tagged with the Camera
> ID. If the ID is missing or wrong, the server has no camera to attach the data
> to and rejects the upload. The device will not send anything until a valid
> Camera ID is saved.

### Step 2 — Power on and connect to the device's WiFi

The first time it powers on (with no WiFi saved), the device creates its own
WiFi access point:

- **Network name:** `MiniSpeedCam`
- **Password:** none (it's an open network)

On your phone or laptop, connect to the `MiniSpeedCam` network. (Some phones
list open networks lower down, or warn that it has "no internet" — that's
expected.)

### Step 3 — Open the configuration page

In a web browser, go to:

```
http://192.168.4.1
```

This opens the MiniSpeedCam configuration portal (three tabs: **Device**,
**Wifi Settings**, **Status**).

### Step 4 — Enter WiFi credentials and your Camera ID

Open the **Wifi Settings** tab and fill in:

| Field | What to enter |
|---|---|
| **Network** | Your WiFi network name (SSID) |
| **Password** | Your WiFi password |
| **Camera ID:** | The Camera ID you copied from minispeedcam.com in Step 1 |

Then press **SAVE**. The device saves everything and **reboots**.

### Step 5 — Confirm it's online

After rebooting, the device joins your WiFi network instead of creating its own
AP. To check it's working:

- Reconnect your phone/laptop to your normal WiFi.
- Open the **Status** tab of the device's page (reach it at
  `http://MiniSpeedCam.local`, or use the IP shown in your router, or the "Open
  device UI" link in your minispeedcam.com dashboard).
- Confirm **IP** shows an address and **WiFi RSSI** shows a signal value.

The device is now linked to your camera. Drive past it (or trigger the radar)
above your Photo Speed and the photo + speed should appear in your
minispeedcam.com account.

---

## Settings reference

### Device tab

| Setting | What it does |
|---|---|
| **Current Speed** | Live readout of the speed the radar is seeing right now (updates a few times per second). |
| **MPH / KPH** | Units for *all* speeds shown and stored. Off = MPH, On = KPH. Changing this changes the meaning of the Minimum Speed and Photo Speed numbers below. |
| **Power-Saver Mode** | On (default) = the device drops WiFi when idle to save power, reconnecting when a vehicle is detected. Off = the device stays awake with WiFi always up (handy while configuring or troubleshooting; uses more power). |
| **Minimum Speed** | The lowest speed (in your chosen units) that counts as a vehicle. Anything slower is ignored. Raise it to skip pedestrians/cyclists; lower it to catch slower traffic. |
| **Photo Speed** | The speed at which a photo is taken. A vehicle whose top speed reaches this value gets photographed; slower vehicles still record a speed but no photo. Set this to your "speeding" threshold. |

> **Minimum Speed vs. Photo Speed:** Minimum Speed decides what gets *tracked*;
> Photo Speed decides what gets *photographed*. A pass between the two values
> uploads a speed-only record. A pass at or above Photo Speed uploads a photo
> too. Keep Photo Speed ≥ Minimum Speed.

### Wifi Settings tab

| Control | What it does |
|---|---|
| **Network** | Your WiFi SSID. |
| **Password** | Your WiFi password. |
| **Camera ID:** | The minispeedcam.com Camera ID that links this device to your camera. **Required for uploads to work.** |
| **SAVE** | Saves Network / Password / Camera ID to the device and reboots so the new settings take effect. |
| **CLEAR** | Wipes the saved WiFi credentials and reboots. The device then comes back up as the `MiniSpeedCam` access point so you can reconfigure it. |

### Status tab (read-only diagnostics)

| Label | Meaning |
|---|---|
| **Current Speed** | Live radar reading. |
| **Free heap / Free PSRAM** | Available memory — useful for spotting leaks/instability. |
| **Uptime** | Time since the last reboot. |
| **WiFi RSSI** | Signal strength in dBm (closer to 0 is stronger; e.g. −60 is good, −85 is weak). `n/a` when not connected. |
| **IP** | The device's address on your network. `n/a` when not connected. |
| **Last upload HTTP** | The HTTP status code of the most recent upload. `200`/`2xx` = success; `400` usually means the Camera ID isn't set or doesn't match an existing camera. |
| **Last reset reason** | Why the device last rebooted (power-on, crash, etc.). |
| **Boot count** | How many times the device has booted. |

---

## Re-entering setup later

If you move the device to a new network or need to change settings:

- **Clear Settings button** — on the Wifi Settings tab, press **CLEAR**. The
  device reboots into `MiniSpeedCam` AP mode for reconfiguration.
- **Physical WiFi-reset button** — press and hold the on-board WiFi-reset button
  for **3 seconds**. This erases the saved WiFi credentials and reboots into AP
  mode. (You must hold it continuously for the full 3 seconds; a quick tap does
  nothing.)

Either way, reconnect to the `MiniSpeedCam` network and repeat Steps 3–5.

---

## Troubleshooting

**The `MiniSpeedCam` WiFi network doesn't appear**
- It only appears when the device has **no valid WiFi saved**. If it previously
  connected to a network, it joins that network instead. Use **Clear Settings**
  or the 3-second WiFi-reset button to force it back into AP mode.
- It's an **open** network — check your "available networks" list carefully;
  some phones sort open networks lower or hide them under "Other networks."

**Uploads aren't appearing in my account / "Last upload HTTP" shows 400**
- The **Camera ID** is almost certainly missing or wrong. Open the Wifi Settings
  tab, paste the exact Camera ID from your minispeedcam.com camera, and press
  SAVE. The device skips uploading entirely until a Camera ID is set.

**Speeds look wrong or erratic / random readings with nothing passing**
- This is usually radio interference from WiFi coupling into the radar. The
  firmware filters out impossible readings and ignores one-off glitches, but if
  it persists, keeping the device on solid 5 V power (a quality supply/cable)
  and good antenna placement helps most.

**The device joins WiFi but the page won't load at `MiniSpeedCam.local`**
- mDNS (`.local`) isn't supported on every network/device. Use the **IP address**
  shown on the Status tab or in your router's device list instead.

---

## Power

MiniSpeedCam runs on **5 V**. It draws roughly **1.1 W** in full operation and
about **0.55 W** when idle (the radar sensor is always on). The simplest way to
run it is a USB-C power bank or wall adapter into either USB-C port. Battery
life depends on how much traffic triggers it.

---

## For developers

This guide is for setting up and using a device. For building/flashing the
firmware, the project layout, board options, and the capture/upload internals,
see the developer README: [README.md](README.md).

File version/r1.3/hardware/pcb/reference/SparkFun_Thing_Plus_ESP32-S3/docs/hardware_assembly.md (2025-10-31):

---
icon: material/cog
---

Now that we're familiar with the hardware on this Thing Plus board, it's time to connect it to our computer or battery power.

## Basic USB Assembly

Basic assembly of the Thing Plus ESP32-S3 only requires a USB-C cable connecting the board to a computer. Just plug the cable into the USB-C connector and move on to the Software Setup section. When powered up for the first time, the RGB LED on the "top-right" of the board should be cycling through a rainbow color similar to the video below:

<figure markdown>
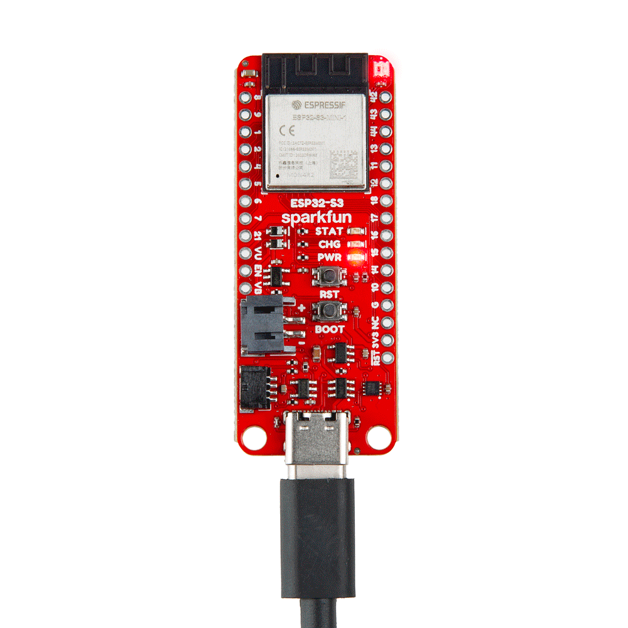
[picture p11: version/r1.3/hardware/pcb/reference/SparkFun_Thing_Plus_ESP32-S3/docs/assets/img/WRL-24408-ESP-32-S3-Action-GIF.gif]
Short video showing RGB led cycling.

</figure>

!!! note
    Your computer may not recognize the board as a known USB device if you have not installed the espressif boards package in Arduino and/or installed the espressif IDF.

## Battery Assembly

If you prefer a battery-powered application, plug a single-cell LiPo battery into the 2-pin JST connector on the underside of the board like the photo below. Remember, the MCP73831 only charges the battery when V_USB has voltage present either from the USB-C connector or through the V_USB PTH pin.

For tips on the proper use of a LiPo battery and the 2-pin JST connector, please read through our [Single Cell LiPo Battery Care](https://learn.sparkfun.com/tutorials/single-cell-lipo-battery-care) tutorial.

## Soldered Assembly

Those who prefer a traditional soldered assembly should solder wires or header pins to the PTH header on the side of the board. If you're not familiar with through-hole soldering or would like a refresher, take a look at our Through-Hole Soldering Tutorial:

<div class="grid cards" markdown align="center">

-   <a href="https://learn.sparkfun.com/tutorials/5">
    <figure markdown>
    How to Solder: Through-Hole Soldering
    </figure>
    </a>
    <a href="https://learn.sparkfun.com/tutorials/5">**How to Solder: Through-Hole Soldering**
    </a>

</div>

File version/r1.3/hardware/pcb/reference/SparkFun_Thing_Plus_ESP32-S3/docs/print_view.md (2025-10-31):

---
hide:
  - navigation
  - toc
icon: fontawesome/solid/scroll
---

# Introduction
--8<-- "./docs/introduction.md:5"

# Hardware Overview
--8<-- "./docs/hardware_overview.md:5"

# Hardware Assembly
--8<-- "./docs/hardware_assembly.md:5"

## Software Setup
--8<-- "./docs/software_setup.md:5"

## Arduino Examples
--8<-- "./docs/arduino_example.md"

# Troubleshooting Tips
--8<-- "./docs/troubleshooting.md:5"

# Resources:
--8<-- "./docs/resources.md"

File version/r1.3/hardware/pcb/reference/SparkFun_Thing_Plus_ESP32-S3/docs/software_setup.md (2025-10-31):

---
icon: simple/arduino
---

!!! attention
	If this is your first time using Arduino, please read through our tutorial on [installing the Arduino IDE](https://learn.sparkfun.com/tutorials/installing-arduino-ide). If you have not installed an Arduino library before, we recommend you check out our [installation guide](https://learn.sparkfun.com/tutorials/installing-an-arduino-library).

With the ESP32-S3 Thing Plus connected to our computer, it's time to set up the boards package in Arduino.

## Installing espressif Arduino Boards
    
To install the ESP32 boards package, open the Preferences menu by navigating to <b>File</b> > <b>Preferences</b>. Look at the bottom of the Preferences menu for "Additional boards manager URLS" and then copy this JSON link into that field:

<code>
    https://espressif.github.io/arduino-esp32/package_esp32_dev_index.json
</code>

Click "Ok" and then open the *Boards Manager* tool, search for "espressif ESP32" and install the latest alpha release (3.0.0-alpha2 or later). This install process may take some time so feel free to step away while it downloads and installs.

## Optional Arduino Libraries

Most of the examples we cover in the next section use existing libraries included with the ESP32 Arduino core but the RGB LED example uses the FastLED library so you'll need it installed to follow along with that example. Navigate to the "Libraries" menu on the left side of the screen, search for "FastLED", and install the latest version. If you prefer to manually install the library, you can download a ZIP of the library by clicking the button below:

<center>
[FastLED Arduino Library](https://github.com/FastLED/FastLED/archive/refs/heads/master.zip){ .md-button .md-button--primary }   
</center>

## espressif IDF

Users who prefer to use espressif's development toolkit, espressif IDF, can get started by following their instructions [here](https://www.espressif.com/en/products/sdks/esp-idf) and  ESP32-S3 specific documentation [here](https://docs.espressif.com/projects/esp-idf/en/stable/esp32S3/index.html).

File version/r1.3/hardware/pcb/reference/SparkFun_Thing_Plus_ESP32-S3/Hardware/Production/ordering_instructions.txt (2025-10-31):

Ordering Instructions:
Panel dimensions: 106.64 x 205.20 mm.
Controlled Impedance: JLC7628
Material: TG155
Solder Mask: Red
Silkscreen: White
Layers: 4
Finish: HASL Lead-Free
Thickness: 1.6mm
Outer Copper Weight: 1oz
Minimum track width: 0.15mm (6.00mil)
Minimum via drill: 0.30mm (11.81mil)

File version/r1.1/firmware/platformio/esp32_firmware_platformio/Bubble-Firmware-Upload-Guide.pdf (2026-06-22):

# MiniSpeedCam - Uploading a Firmware Binary to Bubble

Publishing an over-the-air (OTA) update for the ESP32 or STM32. Assumes the 'Firmware' data type and the 'firmware_check' backend workflow already exist.

The flow: build -> bump version -> compute MD5 -> create a Firmware record (upload the .bin) -> deploy to Live -> test. A device only offers an update when the version in Bubble differs from what it is currently running.

### Step 1 - Bump the version, then build

IMPORTANT: bump the version BEFORE you build. If the new version equals what the device already runs, it reports 'ok' and offers no update.
- ESP32: in platformio.ini change FW_VERSION="1.0.0" to the new value (e.g. "1.0.1").
- STM32: in Core/Src/main.c change #define STM_FW_VERSION "1.0.0".
Then build:

ESP32: pio run -e esp32-s3
-> .pio\build\esp32-s3\firmware.bin
STM32: pio run | (in the stm32 project)
-> .pio\build\genericSTM32F301K8\firmware.bin
Use firmware.bin -- NOT firmware.factory.bin. The factory image (bootloader + partitions + app) is only for a full wired flash, not OTA.

### Step 2 - Compute the MD5

The device verifies the downloaded image against this hash before installing, so a corrupt or truncated download is rejected. In PowerShell:

Get-FileHash -Algorithm MD5 .pio\build\esp32-s3\firmware.bin
Copy the 32-character Hash value. (Comparison on the device is case-insensitive.)

### Step 3 - Create the Firmware record in Bubble

- Bubble editor -> Data -> App data -> All Firmwares -> 'New entry'.
- target = esp (or stm)
- version = the value you set in Step 1 (e.g. 1.0.1)
- md5 = the hash from Step 2
- binary = click to upload, choose firmware.bin
Save the entry. When the file uploads, Bubble stores it (on its S3-backed storage) and the 'binary' field holds the file's URL.

### Step 4 - Make sure the URL is a full https:// link

Bubble file URLs are sometimes 'protocol-relative' -- they start with // instead of https://. The device cannot follow a // URL.
- In the firmware_check workflow's 'Return data from API' action, each *_url value must begin with https://. If the raw file URL starts with //, prepend "https:" to it.
- Quick check: paste the file URL into a browser -- it should download the .bin.

### Step 5 - Deploy to Live (required)

The device calls the LIVE endpoint (yourapp/api/1.1/wf/firmware_check), never version-test. Development and Live have SEPARATE databases and deploys.
- Create the Firmware record in the LIVE database (switch App data to 'Live'), or it won't be seen.
- If you changed the workflow, also Deploy: top bar -> Deploy current version to Live.

### Step 6 - Test before trusting a device

Send a check with fake current versions so a mismatch is guaranteed (use the same Bearer token from the firmware's config.h):

$body = @{ camera="YOUR_CAMERA_ID"; esp_fw="0.0.0"; stm_fw="0.0.0" } |
ConvertTo-Json
Invoke-RestMethod -Uri "https://YOURAPP/api/1.1/wf/firmware_check" `
-Method Post -Headers @{ Authorization = "Bearer YOUR_TOKEN" } `
-ContentType "application/json" -Body $body
Expect a response with esp_version, esp_url (https://...), and esp_md5. Then on the device web UI: Device tab -> Firmware -> 'Check for Updates' (status shows the new version) -> 'Install ESP32 Update'.

### Checklist

- [ ] Version bumped BEFORE building
- [ ] Built firmware.bin (not the .factory.bin)
- [ ] MD5 computed
- [ ] Firmware record created (target, version, md5, binary)
- [ ] File URL is https:// and downloads in a browser
- [ ] Record exists in the LIVE database; app deployed to Live
- [ ] firmware_check returns the new version
- [ ] Device Check + Install works

### Common gotchas

- Dev vs Live: the device only sees Live data + deploys. Most 'it didn't work' issues are this.
- 'No update offered': the Bubble version equals the device's. Bump it.
- MD5 mismatch on device: re-hash the exact firmware.bin you uploaded and re-copy it.
- STM32 updates also need the GPIO14 -> BOOT0 wire and a pull-down on BOOT0.

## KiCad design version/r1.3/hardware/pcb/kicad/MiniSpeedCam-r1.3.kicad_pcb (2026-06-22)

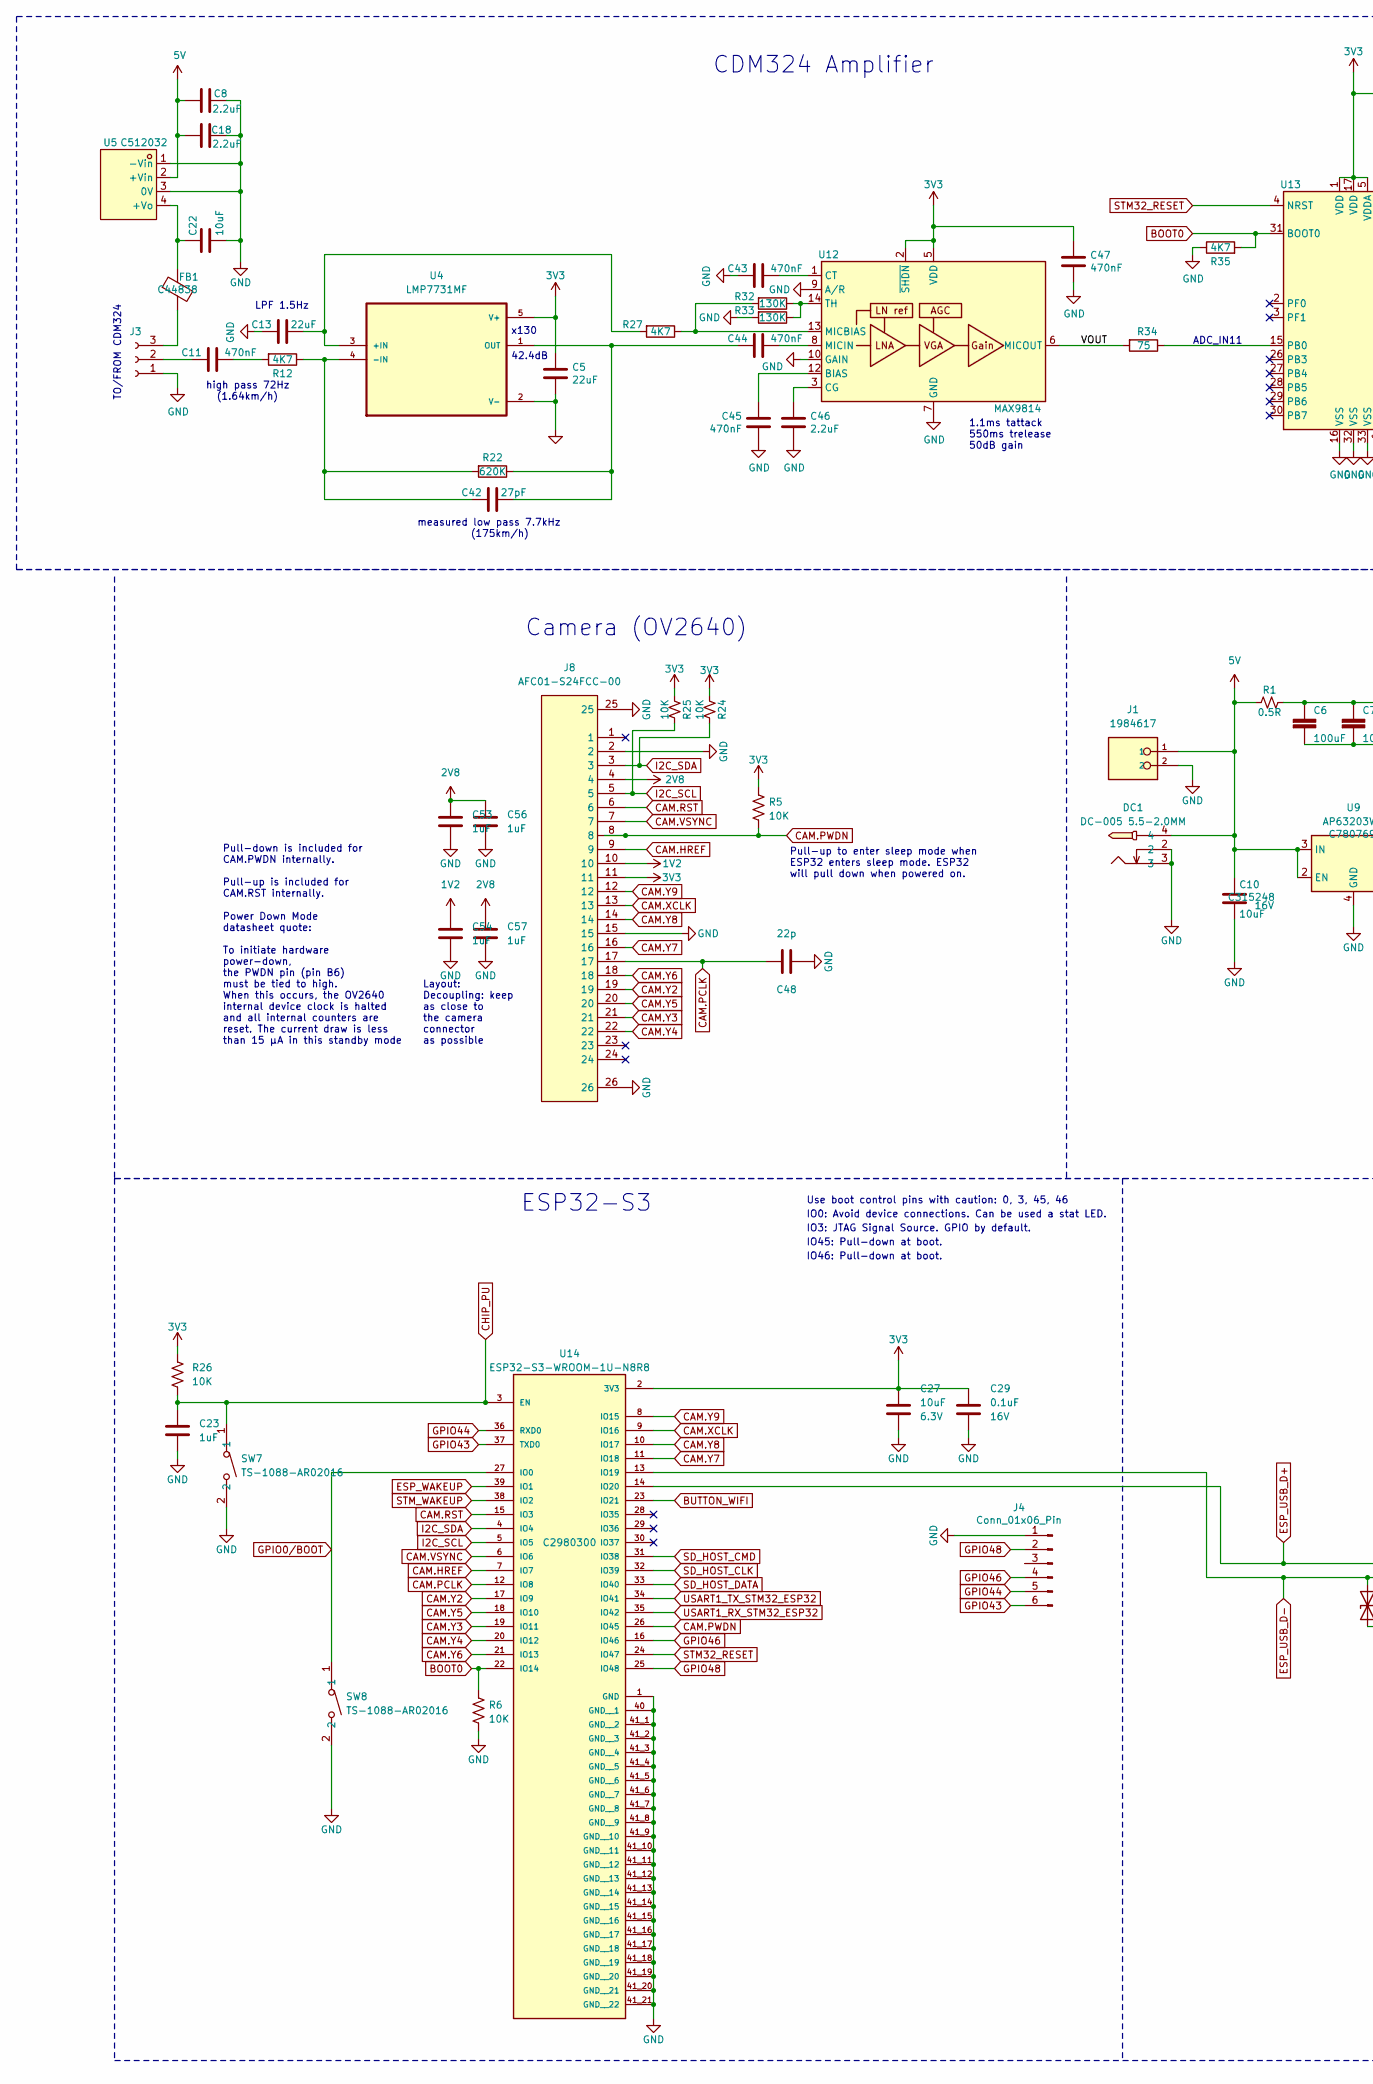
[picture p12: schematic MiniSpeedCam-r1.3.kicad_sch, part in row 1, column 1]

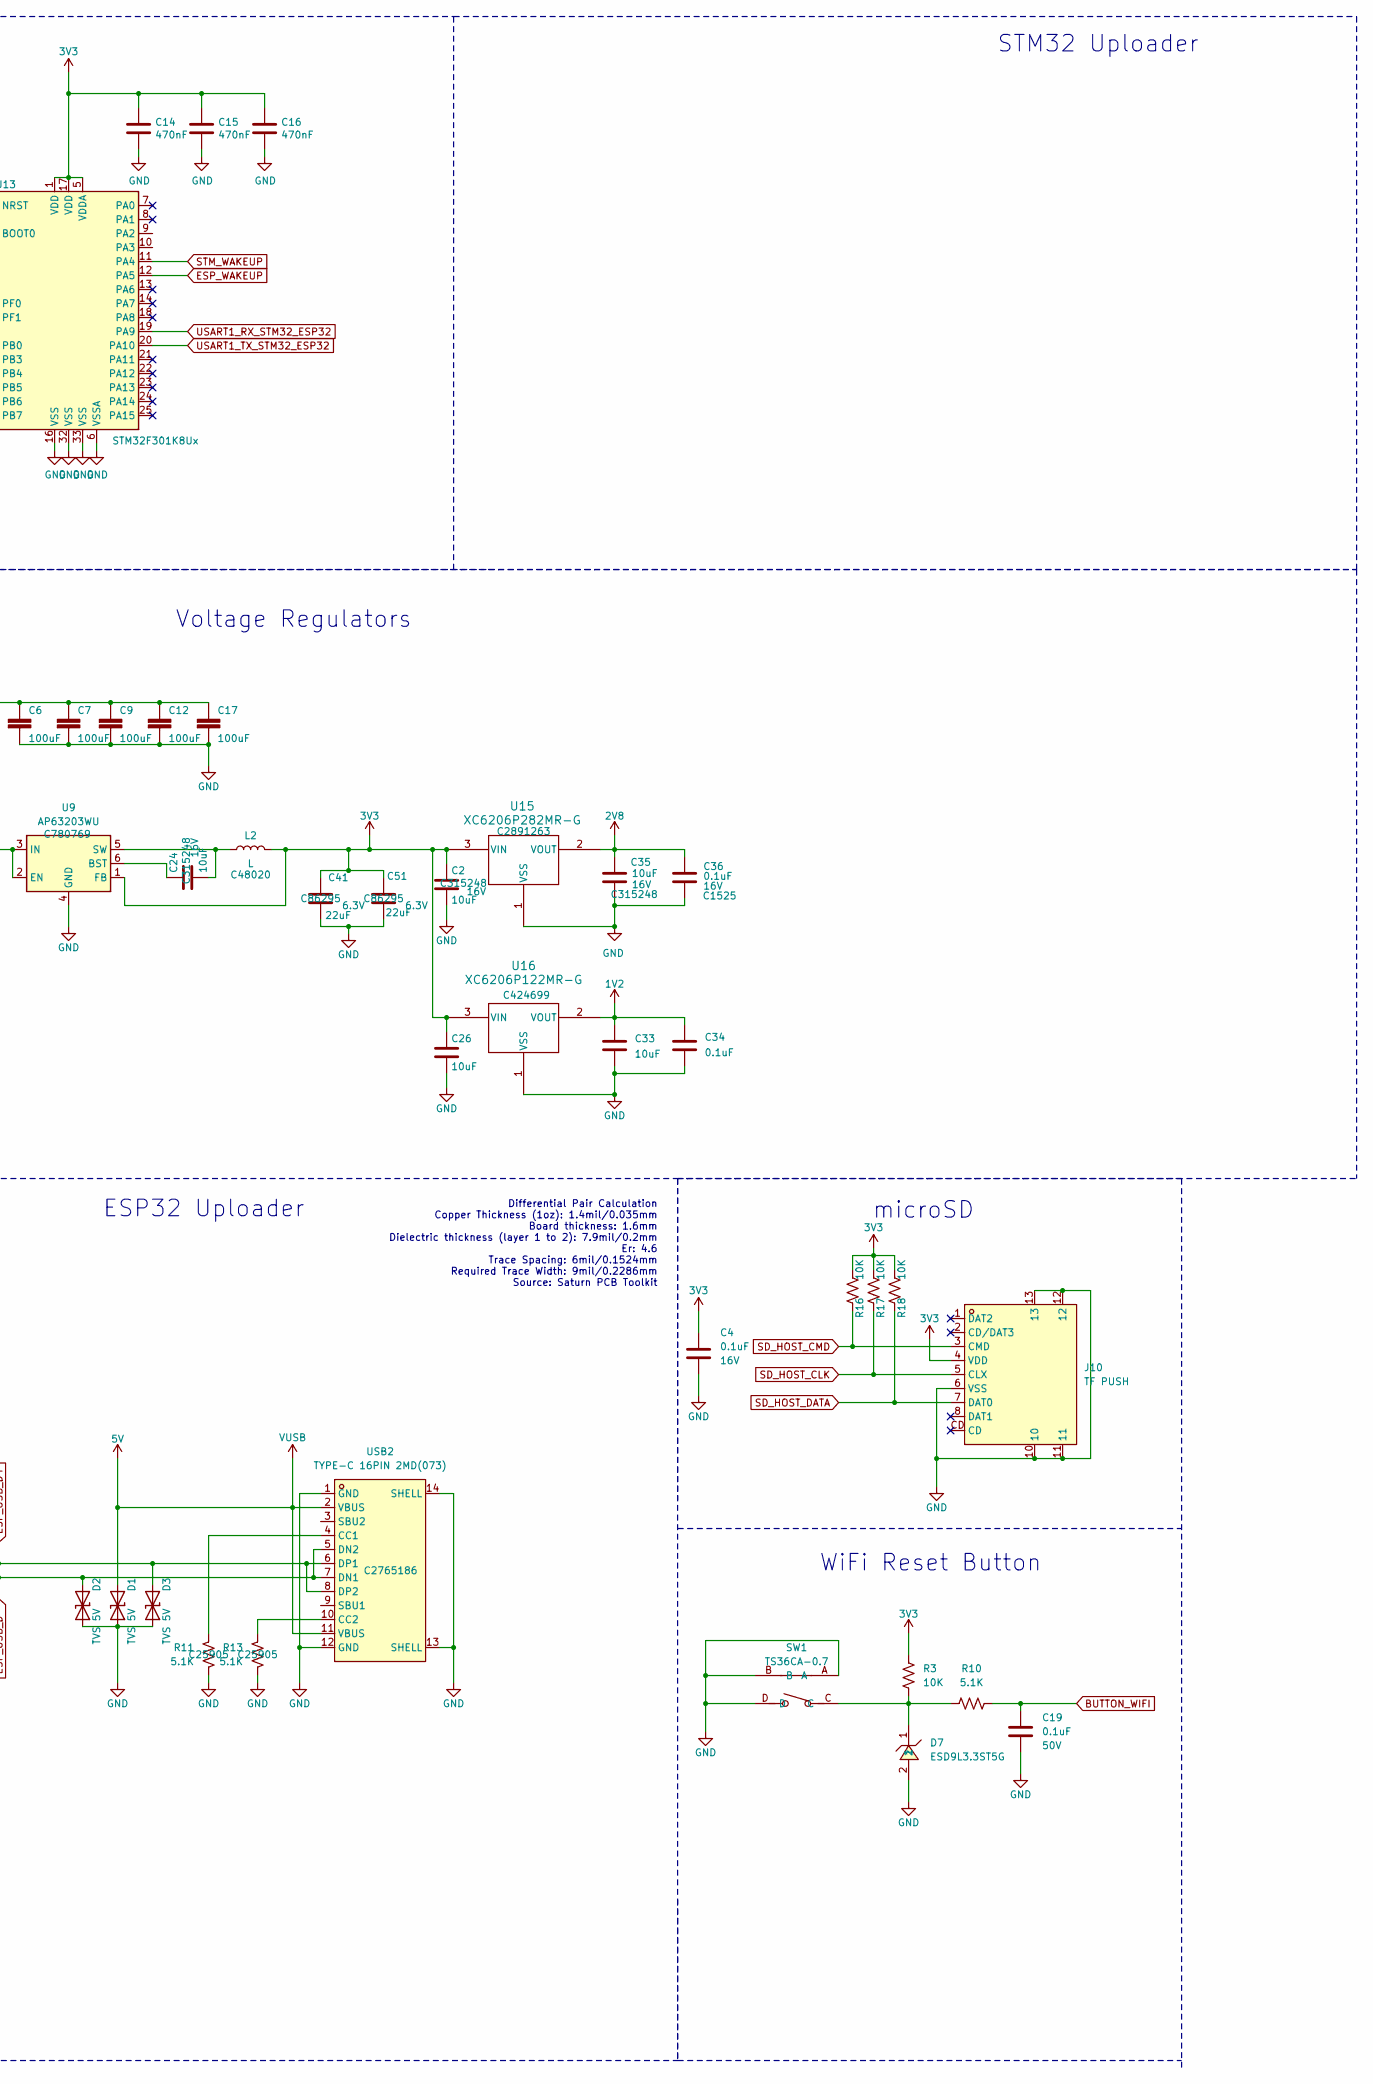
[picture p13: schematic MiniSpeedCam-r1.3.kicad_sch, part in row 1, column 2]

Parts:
C2, C10, C22, C24, C26, C33, C35: 10uF; C_0402_1005Metric; Voltage 16V; Tolerance 10%; LCSC C315248
C4, C29, C34, C36: 0.1uF; C_0402_1005Metric; Voltage 16V; Tolerance 10%; LCSC C1525
C5, C13: 22uF; C_0603_1608Metric; LCSC C86295
C6, C7, C9, C12, C17: 100uF; C_1206_3216Metric; Voltage ???; LCSC C7432784
C8, C18, C46: 2.2uF; C_0603_1608Metric; LCSC C1607
C11, C14, C15, C16, C43, C44, C45, C47: 470nF; C_0402_1005Metric; LCSC C47339
C19: 0.1uF; C_0402_1005Metric; Voltage 50V; Tolerance 10%; LCSC C1525
C23, C53: 10u_0402_CL05A105KA5NQNC; C_0402_1005Metric; Rating 25V; Tolerance 10%; MPN CL05A105KA5NQNC; LCSC C52923
C27: 10uF; C_0402_1005Metric; Voltage 6.3V; Tolerance 20%; LCSC C315248
C41, C51: 22uF; C_0603_1608Metric; Voltage 6.3V; Tolerance 20%; LCSC C86295
C42: 27pF; C_0603_1608Metric; LCSC C1656
C48: 22p_0402_0402CG220J500NT; C_0402_1005Metric; Rating 50V; Tolerance 5%; MPN 0402CG220J500NT; LCSC C1555
C54, C56, C57: 10u_0402_CL05A105KA5NQNC; C_0402_1005Metric; Tolerance 10%; Rating 25V; MPN CL05A105KA5NQNC; LCSC C52923
D1, D2, D3: SOD-523_BSD5C051L; D_SOD-523; MPN BSD5C051L; LCSC C151983
D7: ESD9L3.3ST5G; SOD-923_L0.8-W0.6-LS1.0-RD; LCSC C233387
DC1: DC-005 5.5-2.0MM; DC-IN-TH_DC-005-5.5-2.0; LCSC C16214
FB1: Ferrite_Bead; L_0805_2012Metric; LCSC C44838
J1: 1984617; PHOENIX_1984617; PARTREV 22.08.2018; LCSC C466970
J3: Conn_01x03_Female; PinHeader_1x03_P2.54mm_Vertical
J4: Conn_01x06_Pin; PinHeader_1x06_P2.54mm_Vertical
J8: AFC01-S24FCC-00; FPC-SMD_P0.5-24P_FGS-XJ-H2.0; LCSC C262276
J10: TF PUSH; TF-SMD_TF-PUSH; LCSC C393941
L2: L; IND-SMD_L3.0-W3.0_FNR30XXS; LCSC C48020
R1: 0.5R; R_0603_1608Metric; LCSC C2934253
R3, R5, R6, R16, R17, R18, R24, R25, R26: 10K; R_0402_1005Metric; LCSC C25744
R10, R11, R13: 5.1K; R_0402_1005Metric; LCSC C25905
R12, R27, R35: 4K7; R_0603_1608Metric; LCSC C99782
R22: 620K; R_0603_1608Metric; LCSC C68737
R32, R33: 130K; R_0603_1608Metric; LCSC C22795
R34: 75; R_0402_1005Metric; LCSC C137841
SW1: TS36CA-0.7; SW-SMD_TS36CA; LCSC C412365
SW7, SW8: TS-1088-AR02016; SW-SMD_L3.9-W3.0-P4.45; LCSC C720477
U4: LMP7731MF; SOT-23-5_L3.0-W1.7-P0.95-LS2.8-BL; LCSC C202252
U5: B0505S-1W_C512032; PWRM-TH_BXXXXS-1W; LCSC C512032
U9: AP63203WU; TSOT-23-6; LCSC C780769
U12: MAX9814; DFN-14-1EP_3x3mm_P0.4mm_EP1.78x2.35mm; LCSC C41714
U13: STM32F301K8Ux; QFN-32-1EP_5x5mm_P0.5mm_EP3.45x3.45mm; LCSC C111684
U14: ESP32-S3-WROOM-1U-N8R8; XCVR_ESP32-S3-WROOM-1U-N8R8; PARTREV v1.1; LCSC C2980300
U15: XC6206P282MR-G; SOT-23_TOR; LCSC C2891263
U16: XC6206P122MR-G; SOT-23_TOR; LCSC C424699
USB2: TYPE-C 16PIN 2MD(073); USB-C-SMD_TYPE-C-6PIN-2MD-073; LCSC C2765186

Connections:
1V2: C33.1, C34.1, C54.2, J8.10, U16.2 (VOUT)
2V8: C35.1, C36.1, C53.1, C56.2, C57.2, J8.4, U15.2 (VOUT)
3V3: C2.1, C4.1, C5.1, C14.1, C15.1, C16.1, C26.1, C27.1, C29.1, C41.2, C47.1, C51.2, J8.11, J10.4 (VDD), L2.2, R3.1, R5.1, R16.1, R17.1, R18.1, R24.1, R25.1, R26.1, U4.5 (V+), U9.1 (FB), U12.2 (~SHDN), U12.5 (VDD), U13.1 (VDD), U13.5 (VDDA), U13.17 (VDD), U14.2 (3V3), U15.3 (VIN), U16.3 (VIN)
5V: C8.1, C10.1, C18.1, D1.2 (A2), DC1.4, J1.1, R1.1, U5.2 (+Vin), U9.2 (EN), U9.3 (IN), USB2.2 (VBUS), USB2.11 (VBUS)
/VOUT: R34.2, U12.6 (MICOUT)
BOOT0: R6.1, R35.2, U13.31 (BOOT0), U14.22 (IO14)
BUTTON_WIFI: C19.2, R10.2, U14.23 (IO21)
CAM.HREF: J8.9, U14.7 (IO7)
CAM.PCLK: C48.1, J8.17, U14.12 (IO8)
CAM.PWDN: J8.8, R5.2, U14.26 (IO45)
CAM.RST: J8.6, U14.15 (IO3)
CAM.VSYNC: J8.7, U14.6 (IO6)
CAM.XCLK: J8.13, U14.9 (IO16)
CAM.Y2: J8.19, U14.17 (IO9)
CAM.Y3: J8.21, U14.19 (IO11)
CAM.Y4: J8.22, U14.20 (IO12)
CAM.Y5: J8.20, U14.18 (IO10)
CAM.Y6: J8.18, U14.21 (IO13)
CAM.Y7: J8.16, U14.11 (IO18)
CAM.Y8: J8.14, U14.10 (IO17)
CAM.Y9: J8.12, U14.8 (IO15)
CHIP_PU: C23.1, R26.2, SW7.1, U14.3 (EN)
ESP_USB_D+: D3.2 (A2), U14.14 (IO20), USB2.6 (DP1), USB2.8 (DP2)
ESP_USB_D-: D2.2 (A2), U14.13 (IO19), USB2.5 (DN2), USB2.7 (DN1)
ESP_WAKEUP: U13.12 (PA5), U14.39 (IO1)
GND: C2.2, C4.2, C5.2, C6.2, C7.2, C8.2, C9.2, C10.2, C12.2, C13.2, C14.2, C15.2, C16.2, C17.2, C18.2, C19.1, C22.2, C23.2, C26.2, C27.2, C29.2, C33.2, C34.2, C35.2, C36.2, C41.1, C43.2, C45.2, C46.2, C47.2, C48.2, C51.1, C53.2, C54.1, C56.1, C57.1, D1.1 (A1), D2.1 (A1), D3.1 (A1), D7.2, DC1.2, DC1.3, J1.2, J3.1, J4.1, J8.2, J8.15, J8.25, J8.26, J10.6 (VSS), J10.10, J10.11, J10.12, J10.13, R6.2, R11.2, R13.1, R33.2, R35.1, SW1.A, SW1.B, SW1.D, SW7.2, SW8.2, U4.2 (V-), U5.1 (-Vin), U5.3 (0V), U9.4 (GND), U12.4 (GND), U12.7 (GND), U12.9 (A/R), U12.10 (GAIN), U12.11 (GND), U12.15 (GND), U13.6 (VSSA), U13.16 (VSS), U13.32 (VSS), U13.33 (VSS), U14.1 (GND), U14.40 (GND__1), U14.41_1 (GND__2), U14.41_2 (GND__3), U14.41_3 (GND__4), U14.41_4 (GND__5), U14.41_5 (GND__6), U14.41_6 (GND__7), U14.41_7 (GND__8), U14.41_8 (GND__9), U14.41_9 (GND__10), U14.41_10 (GND__11), U14.41_11 (GND__12), U14.41_12 (GND__13), U14.41_13 (GND__14), U14.41_14 (GND__15), U14.41_15 (GND__16), U14.41_16 (GND__17), U14.41_17 (GND__18), U14.41_18 (GND__19), U14.41_19 (GND__20), U14.41_20 (GND__21), U14.41_21 (GND__22), U15.1 (VSS), U16.1 (VSS), USB2.1 (GND), USB2.12 (GND), USB2.13 (SHELL), USB2.14 (SHELL)
GPIO0/BOOT: SW8.1, U14.27 (IO0)
GPIO43: J4.6, U14.37 (TXD0)
GPIO44: J4.5, U14.36 (RXD0)
GPIO46: J4.4, U14.16 (IO46)
GPIO48: J4.2, U14.25 (IO48)
I2C_SCL: J8.5, R25.2, U14.5 (IO5)
I2C_SDA: J8.3, R24.2, U14.4 (IO4)
unnamed: C11.1, R12.2
unnamed: C6.1, C7.1, C9.1, C12.1, C17.1, R1.2
unnamed: D7.1, R3.2, R10.1, SW1.C
unnamed: C11.2, J3.2
unnamed: FB1.2, J3.3
unnamed: C13.1, R27.2, U4.3 (+IN)
unnamed: C42.2, R12.1, R22.2, U4.4 (-IN)
unnamed: C42.1, C44.2, R22.1, U4.1 (OUT)
unnamed: C22.1, FB1.1, U5.4 (+Vo)
unnamed: C24.1, U9.6 (BST)
unnamed: C24.2, L2.1, U9.5 (SW)
unnamed: C45.1, U12.12 (BIAS)
unnamed: C46.1, U12.3 (CG)
unnamed: C43.1, U12.1 (CT)
unnamed: R27.1, R32.2, U12.13 (MICBIAS)
unnamed: C44.1, U12.8 (MICIN)
unnamed: R32.1, R33.1, U12.14 (TH)
unnamed: R34.1, U13.15 (PB0)
unnamed: R11.1, USB2.4 (CC1)
unnamed: R13.2, USB2.10 (CC2)
SD_HOST_CLK: J10.5 (CLX), R17.2, U14.32 (IO39)
SD_HOST_CMD: J10.3 (CMD), R16.2, U14.31 (IO38)
SD_HOST_DATA: J10.7 (DAT0), R18.2, U14.33 (IO40)
STM32_RESET: U13.4 (NRST), U14.24 (IO47)
STM_WAKEUP: U13.11 (PA4), U14.38 (IO2)
USART1_RX_STM32_ESP32: U13.19 (PA9), U14.35 (IO42)
USART1_TX_STM32_ESP32: U13.20 (PA10), U14.34 (IO41)

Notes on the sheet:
1.1ms tattack 550ms trelease 50dB gain
ADC_IN11
Differential Pair Calculation Copper Thickness (1oz): 1.4mil/0.035mm Board thickness: 1.6mm Dielectric thickness (layer 1 to 2): 7.9mil/0.2mm Er: 4.6 Trace Spacing: 6mil/0.1524mm Required Trace Width: 9mil/0.2286mm Source: Saturn PCB Toolkit
IO0: Avoid device connections. Can be used a stat LED.
WiFi Reset Button
Voltage Regulators
high pass 72Hz (1.64km/h)
TO/FROM CDM324
Pull-down is included for CAM.PWDN internally. Pull-up is included for CAM.RST internally.
IO46: Pull-down at boot.
ESP32-S3
Power Down Mode datasheet quote: To initiate hardware power-down, the PWDN pin (pin B6) must be tied to high. When this occurs, the OV2640 internal device clock is halted and all internal counters are reset. The current draw is less than 15 µA in this standby mode
42.4dB
x130
ESP32 Uploader
Pull-up to enter sleep mode when ESP32 enters sleep mode. ESP32 will pull down when powered on.
Use boot control pins with caution: 0, 3, 45, 46
CDM324 Amplifier
microSD
IO45: Pull-down at boot.
Camera (OV2640)
Layout: Decoupling: keep as close to the camera connector as possible
measured low pass 7.7kHz (175km/h)
LPF 1.5Hz
IO3: JTAG Signal Source. GPIO by default.
STM32 Uploader

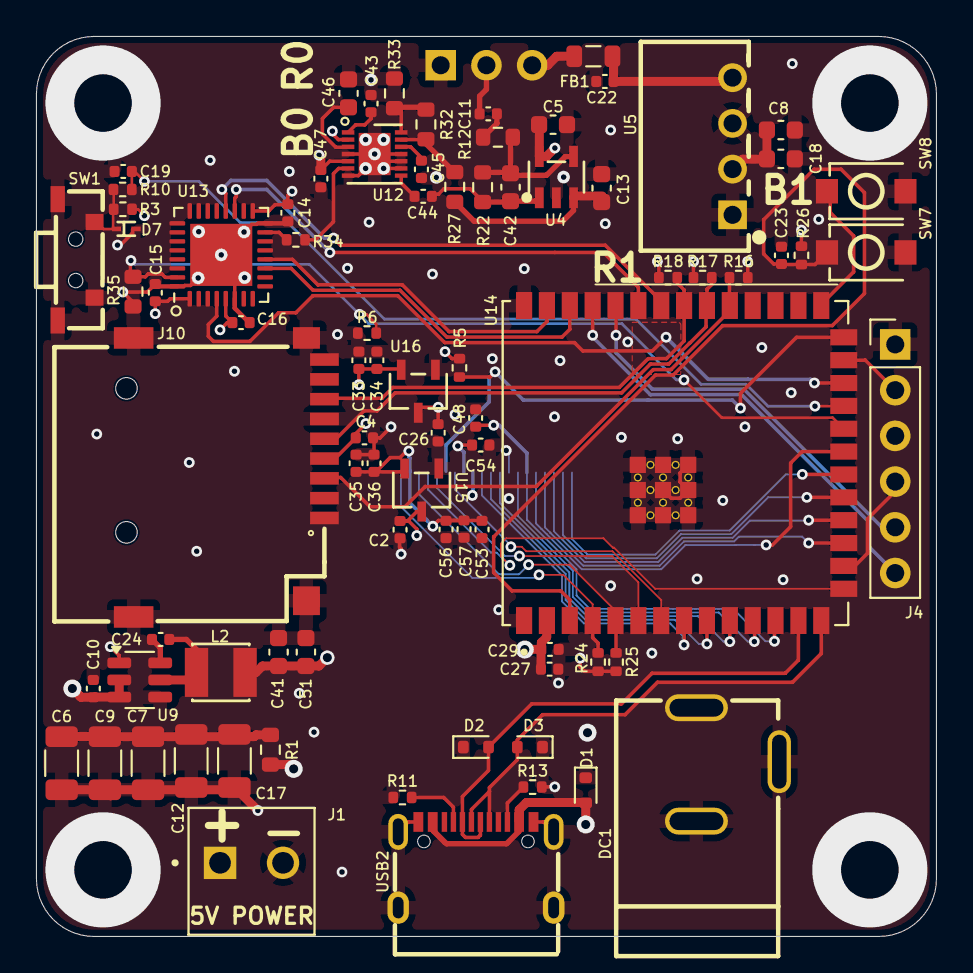
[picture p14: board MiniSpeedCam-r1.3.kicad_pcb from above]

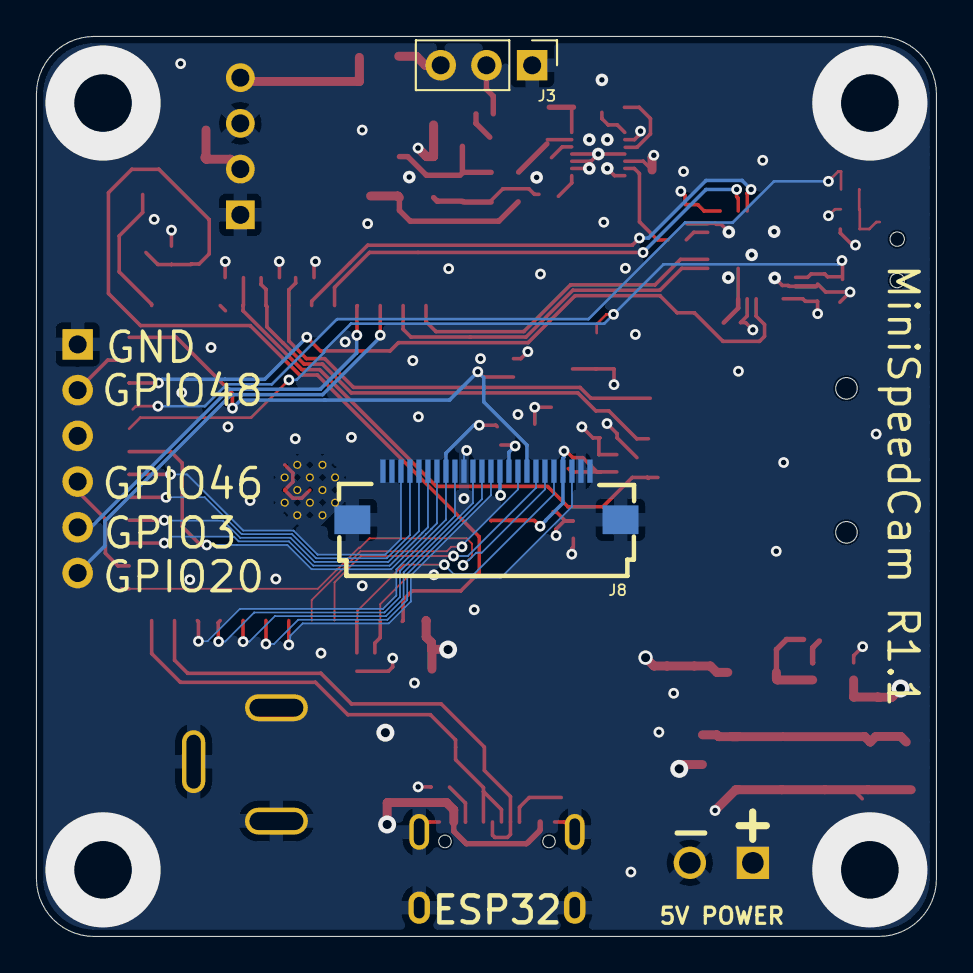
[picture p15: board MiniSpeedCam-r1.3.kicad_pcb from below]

Board: 4 copper layers, 50.0 x 50.0 mm, 84 parts (2 on the bottom side), 60 nets.

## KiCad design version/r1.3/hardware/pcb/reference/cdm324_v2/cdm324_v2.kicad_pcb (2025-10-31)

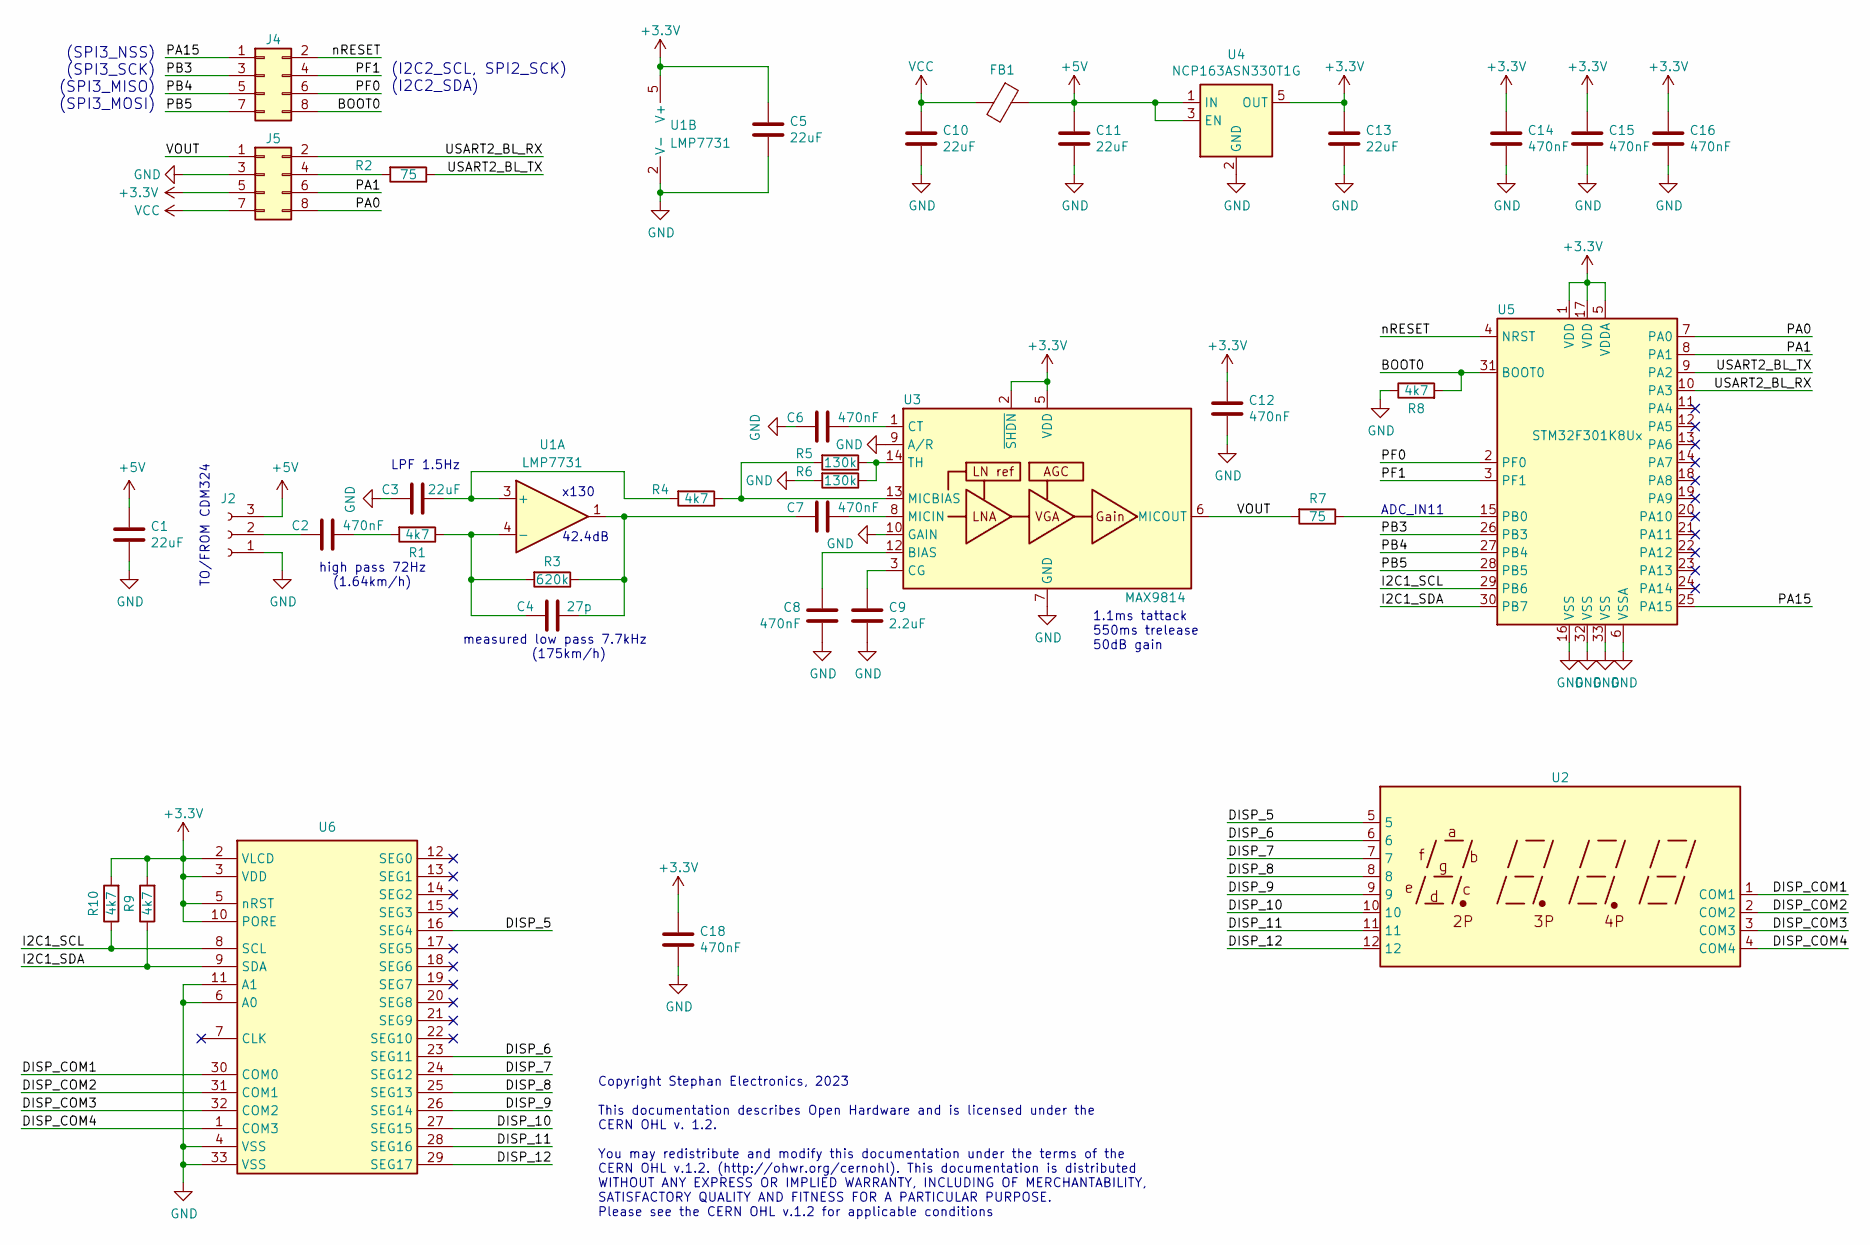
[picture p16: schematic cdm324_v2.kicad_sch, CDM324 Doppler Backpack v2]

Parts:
C1, C3, C5, C10, C11, C13: 22uF; C_0805_2012Metric
C2, C6, C7, C8, C12, C14, C15, C16, C18: 470nF; C_0402_1005Metric
C4: 27p; C_0603_1608Metric
C9: 2.2uF; C_0603_1608Metric
FB1: Ferrite_Bead; L_0805_2012Metric
J2: Conn_01x03_Female; PinHeader_1x03_P2.54mm_Vertical
J4, J5: Conn_02x04_Odd_Even; PinSocket_2x04_P2.54mm_Vertical
R1, R4, R8, R9, R10: 4k7; R_0603_1608Metric
R2, R7: 75; R_0402_1005Metric
R3: 620k; R_0603_1608Metric
R5, R6: 130k; R_0603_1608Metric
U1: LMP7731; SOT-23-5
U2: TN_DISPLAY
U3: MAX9814; DFN-14-1EP_3x3mm_P0.4mm_EP1.78x2.35mm
U4: NCP163ASN330T1G; SOT-23-5
U5: STM32F301K8Ux; QFN-32-1EP_5x5mm_P0.5mm_EP3.45x3.45mm
U6: QFN-32-1EP_5x5mm_P0.5mm_EP3.65x3.65mm

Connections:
+3V3: C5.1, C12.1, C13.1, C14.1, C15.1, C16.1, C18.1, J5.5, R9.2, R10.2, U1.5 (V+), U3.2 (~SHDN), U3.5 (VDD), U4.5 (OUT), U5.1 (VDD), U5.5 (VDDA), U5.17 (VDD), U6.2 (VLCD), U6.3 (VDD), U6.5 (nRST), U6.10 (PORE)
+5V: C1.1, C11.1, FB1.1, J2.3, U4.1 (IN), U4.3 (EN)
/BOOT0: J4.8, R8.2, U5.31 (BOOT0)
/DISP_5: U2.5, U6.16 (SEG4)
/DISP_6: U2.6, U6.23 (SEG11)
/DISP_7: U2.7, U6.24 (SEG12)
/DISP_8: U2.8, U6.25 (SEG13)
/DISP_9: U2.9, U6.26 (SEG14)
/DISP_10: U2.10, U6.27 (SEG15)
/DISP_11: U2.11, U6.28 (SEG16)
/DISP_12: U2.12, U6.29 (SEG17)
/DISP_COM1: U2.1 (COM1), U6.30 (COM0)
/DISP_COM2: U2.2 (COM2), U6.31 (COM1)
/DISP_COM3: U2.3 (COM3), U6.32 (COM2)
/DISP_COM4: U2.4 (COM4), U6.1 (COM3)
/I2C1_SCL: R10.1, U5.29 (PB6), U6.8 (SCL)
/I2C1_SDA: R9.1, U5.30 (PB7), U6.9 (SDA)
/PA0: J5.8, U5.7 (PA0)
/PA1: J5.6, U5.8 (PA1)
/PA15: J4.1, U5.25 (PA15)
/PB3: J4.3, U5.26 (PB3)
/PB4: J4.5, U5.27 (PB4)
/PB5: J4.7, U5.28 (PB5)
/PF0: J4.6, U5.2 (PF0)
/PF1: J4.4, U5.3 (PF1)
/USART2_BL_RX: J5.2, U5.10 (PA3)
/USART2_BL_TX: R2.1, U5.9 (PA2)
/VOUT: J5.1, R7.2, U3.6 (MICOUT)
/nRESET: J4.2, U5.4 (NRST)
GND: C1.2, C3.2, C5.2, C6.2, C8.2, C9.2, C10.2, C11.2, C12.2, C13.2, C14.2, C15.2, C16.2, C18.2, J2.1, J5.3, R6.2, R8.1, U1.2 (V-), U3.4 (GND), U3.7 (GND), U3.9 (A/R), U3.10 (GAIN), U3.11 (GND), U3.15 (GND), U4.2 (GND), U5.6 (VSSA), U5.16 (VSS), U5.32 (VSS), U5.33 (VSS), U6.4 (VSS), U6.6 (A0), U6.11 (A1), U6.33 (VSS)
unnamed: C2.1, R1.2
unnamed: C4.1, C7.2, R3.1, U1.1
unnamed: C2.2, J2.2
unnamed: J5.4, R2.2
unnamed: C3.1, R4.2, U1.3 (+)
unnamed: C4.2, R1.1, R3.2, U1.4 (-)
unnamed: C8.1, U3.12 (BIAS)
unnamed: C9.1, U3.3 (CG)
unnamed: C6.1, U3.1 (CT)
unnamed: R4.1, R5.2, U3.13 (MICBIAS)
unnamed: C7.1, U3.8 (MICIN)
unnamed: R5.1, R6.1, U3.14 (TH)
unnamed: R7.1, U5.15 (PB0)
VCC: C10.1, FB1.2, J5.7

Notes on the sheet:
1.1ms tattack 550ms trelease 50dB gain
measured low pass 7.7kHz (175km/h)
(SPI3_NSS) (SPI3_SCK) (SPI3_MISO) (SPI3_MOSI)
TO/FROM CDM324
Copyright Stephan Electronics, 2023 This documentation describes Open Hardware and is licensed under the CERN OHL v. 1.2. You may redistribute and modify this documentation under the terms of the CERN OHL v.1.2. (http://ohwr.org/cernohl). This documentation is distributed WITHOUT ANY EXPRESS OR IMP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
ADC_IN11
x130
high pass 72Hz (1.64km/h)
LPF 1.5Hz
42.4dB
(I2C2_SCL, SPI2_SCK) (I2C2_SDA)

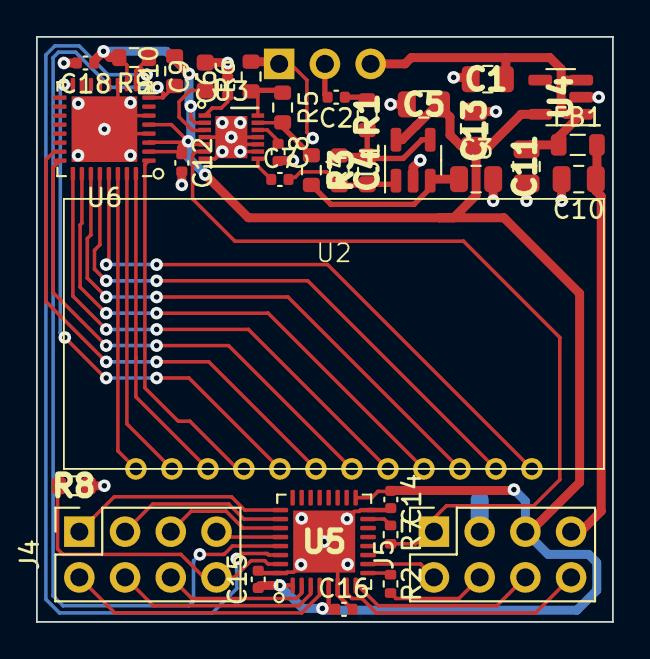
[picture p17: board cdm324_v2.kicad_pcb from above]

Board: 2 copper layers, 32.0 x 32.5 mm, 37 parts (1 on the bottom side), 44 nets.

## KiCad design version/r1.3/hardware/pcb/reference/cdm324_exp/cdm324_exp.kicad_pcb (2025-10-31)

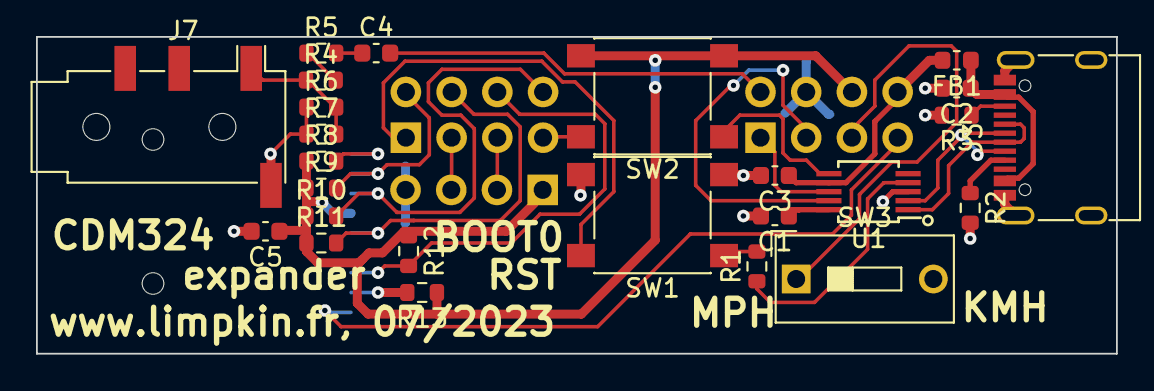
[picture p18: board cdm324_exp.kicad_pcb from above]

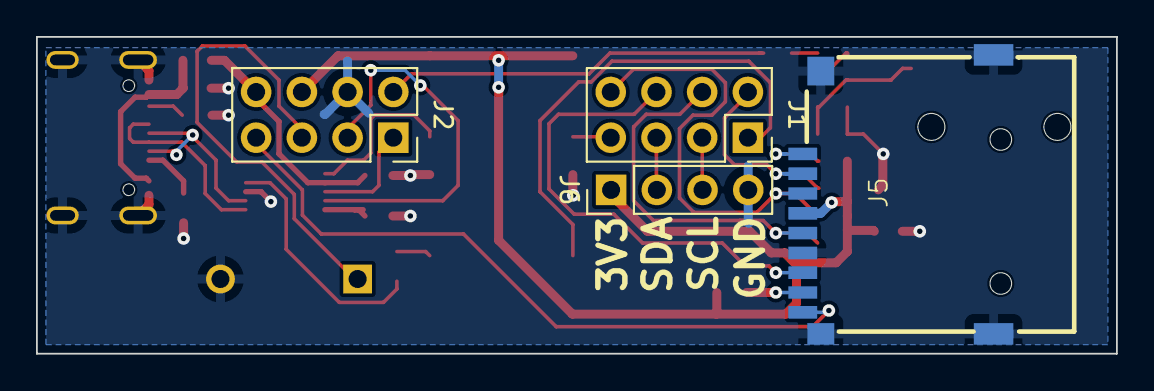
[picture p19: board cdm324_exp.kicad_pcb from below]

Board: 2 copper layers, 60.0 x 17.6 mm, 29 parts (4 on the bottom side), 28 nets.

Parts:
C1, C2, C3, C4, C5: 1uF; C_0603_1608Metric
FB1: FerriteBead; L_0603_1608Metric
J1, J2: Conn_02x04_Odd_Even; PinSocket_2x04_P2.54mm_Vertical
J3: USB_C_Receptacle_USB2.0; USB_C_Receptacle_G-Switch_GT-USB-7010ASV
J5: Micro_SD_Card_Det1; XKTF-015-N
J6: Conn_01x04_Socket; PinHeader_1x04_P2.54mm_Vertical
J7: AudioJack4; Jack_3.5mm_PJ320D_Horizontal
R1, R4, R5, R6, R7: 1k; R_0603_1608Metric
R2, R3: 5.1k; R_0603_1608Metric
R8, R9, R10, R11, R12, R13: 49k9; R_0603_1608Metric
SW1, SW2: SW_Push; SW_Push_1P1T_NO_6x6mm_H9.5mm
SW3: SW_DIP_x01; SW_DIP_SPSTx01_Slide_9.78x4.72mm_W7.62mm_P2.54mm
U1: CH340X; MSOP-10_3x3mm_P0.5mm

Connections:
+3V3: C5.1, J2.6, J5.4 (VDD), J6.1, R8.1, R9.1, R10.1, R11.1, R12.1, R13.1, SW2.2
/BOOT0: J1.7, SW2.1, U1.6 (TNOW)
/I2C_SCL: J1.3, J6.3
/I2C_SDA: J1.5, J6.2
/PA0: J2.7, J5.9 (DET)
/PA1: J2.5, SW3.1
/SPI_MISO: J1.6, J5.7 (DAT0), R12.2
/SPI_MOSI: J1.8, J5.3 (CMD), R10.2
/SPI_SCK: J1.4, J5.5 (CLK), R11.2
/SPI_nCS: J1.2, J5.2 (DAT3/CD), R9.2
/UART_RX: J2.1, U1.8 (TXD)
/UART_TX: J2.3, U1.9 (RXD)
/VOUT: C4.2, J2.2
/nRESET: J1.1, R1.2, SW1.1
GND: C1.2, C2.2, C3.2, C5.2, J2.4, J3.A1 (GND), J3.A12 (GND), J3.B1 (GND), J3.B12 (GND), J3.S1 (SHIELD), J5.6 (VSS), J5.10 (SHIELD), J6.4, J7.S, R2.2, R3.2, R6.1, R7.1, SW1.2, SW3.2, U1.3 (GND)
unnamed: C2.1, FB1.1, J3.A4 (VBUS), J3.A9 (VBUS), J3.B4 (VBUS), J3.B9 (VBUS)
unnamed: C4.1, R5.2
unnamed: J3.A5 (CC1), R2.1
unnamed: J3.B5 (CC2), R3.1
unnamed: J5.8 (DAT1), R13.2
unnamed: J5.1 (DAT2), R8.2
unnamed: J7.T, R4.1, R6.2, R7.2
unnamed: R4.2, R5.1
unnamed: J3.A6 (D+), J3.B6 (D+), U1.1 (UD+)
unnamed: J3.A7 (D-), J3.B7 (D-), U1.2 (UD-)
unnamed: C1.1, U1.10 (V3)
unnamed: R1.1, U1.4 (~RTS)
VCC: C3.1, FB1.2, J2.8, U1.7 (VCC)

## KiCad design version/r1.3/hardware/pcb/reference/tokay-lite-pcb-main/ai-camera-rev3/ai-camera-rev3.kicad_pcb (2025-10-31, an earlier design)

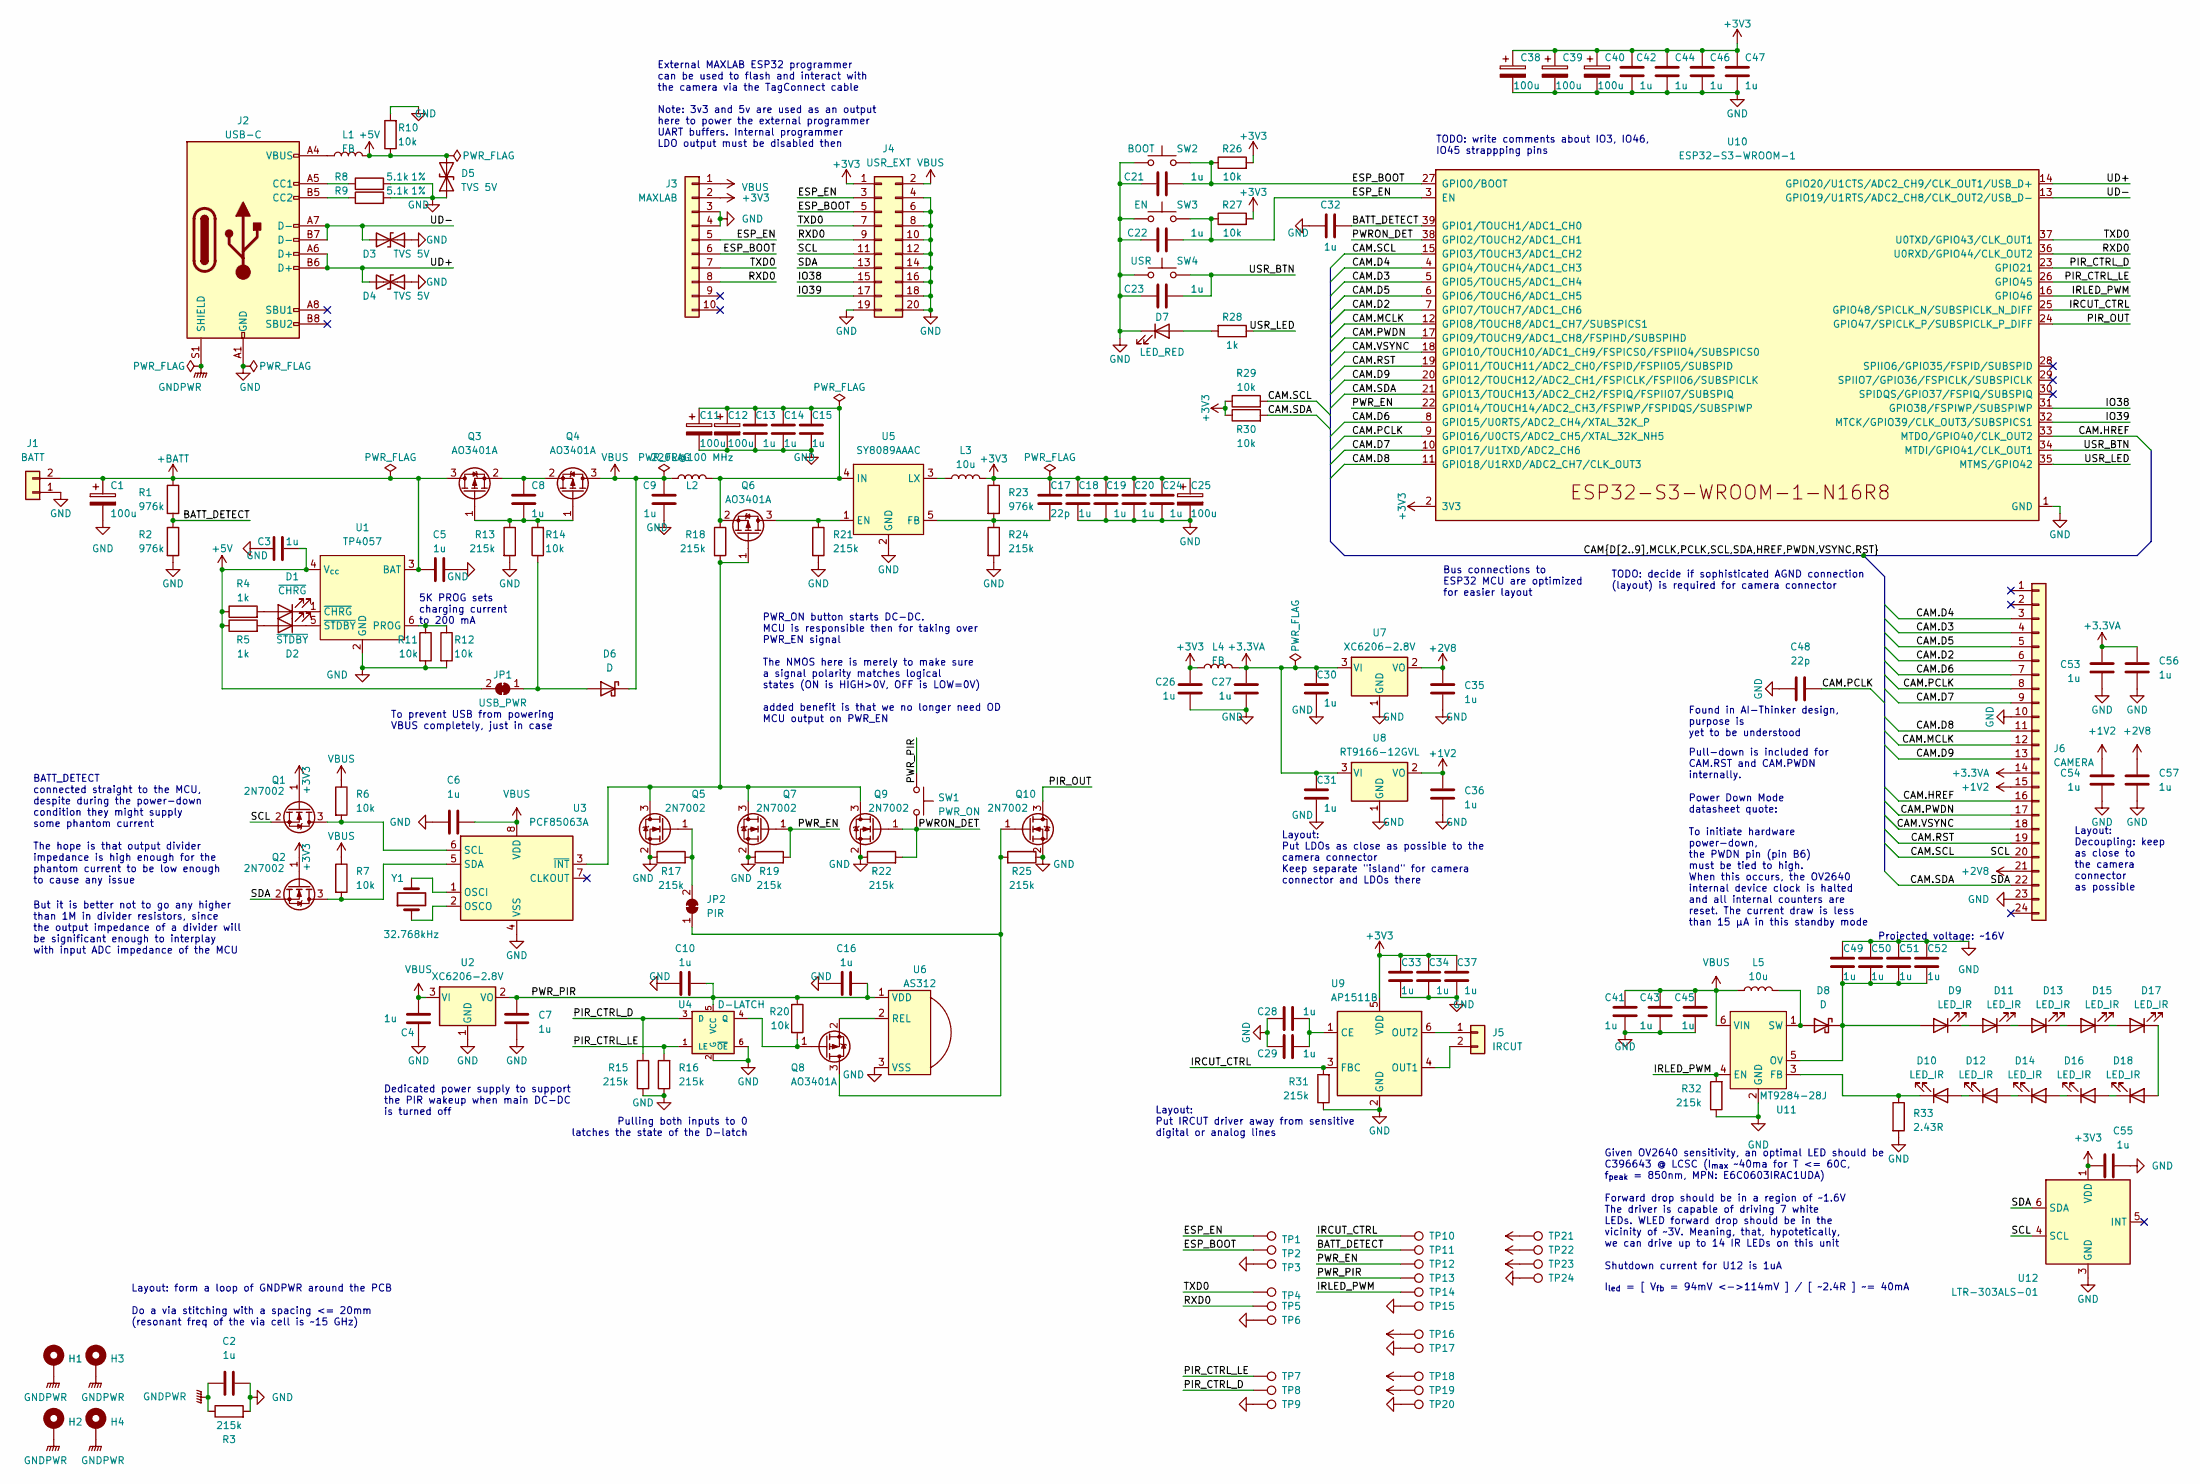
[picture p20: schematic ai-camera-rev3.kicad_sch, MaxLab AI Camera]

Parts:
C1, C11, C12, C25, C38, C39, C40: 100u_CASE-B-3528_TAJB107K006RNJ; CP_EIA-3528-15_AVX-H; Rating 6.3V; Tolerance 10%; MPN TAJB107K006RNJ
C2, C6, C10, C15, C16, C18, C21, C23, C28, C29, C32, C33, C45, C46, C47, C49, C54, C55, C56, C57: 10u_0402_CL05A105KA5NQNC; C_0402_1005Metric; Tolerance 10%; Rating 25V; MPN CL05A105KA5NQNC
C3, C4, C5, C7, C8, C9, C13, C14, C19, C20, C22, C24, C26, C27, C30, C31, C34, C35, C36, C37, C41, C42, C43, C44, C50, C51, C52, C53: 10u_0402_CL05A105KA5NQNC; C_0402_1005Metric; Rating 25V; Tolerance 10%; MPN CL05A105KA5NQNC
C17, C48: 22p_0402_0402CG220J500NT; C_0402_1005Metric; Rating 50V; Tolerance 5%; MPN 0402CG220J500NT
D1, D7: 0603_RED_KT-0603R; LED_0603_1608Metric; MPN KT-0603R
D2: 0603_GREEN_19-217/GHC-YR1S2/3T; LED_0603_1608Metric; MPN 19-217/GHC-YR1S2/3T
D3, D4, D5: SOD-523_BSD5C051L; D_SOD-523; MPN BSD5C051L
D6, D8: B5819W-SL_SOD-123; D_SOD-123; Rating 1A; MPN B5819W SL
D9, D10, D11, D12, D13, D14, D15, D16, D17, D18: 0603_IR_850nm_E6C0603IRAC1UDA; LED_0603_1608Metric; MPN E6C0603IRAC1UDA
H1, H2, H3, H4: MountingHole_Pad; MountingHole_3.2mm_M3_Pad_TopBottom
J1: Conn-01x02_P2mm_NONAME_JST-PH_C47647; JST_PH_S2B-PH-SM4-TB_1x02-1MP_P2.00mm_Horizontal; MPN C47647
J2: TYPE-C-31-M-12; USB_C_Receptacle_HRO_TYPE-C-31-M-12; MPN TYPE-C-31-M-12
J3: MAXLAB; Tag-Connect_TC2050-IDC-FP_2x05_P1.27mm_Vertical
J4: Conn-02x10_P2.54mm_B-2100S20P-B110; PinHeader_2x10_P2.54mm_Vertical; MPN B-2100S20P-B110
J5: Conn-01x02_P1.25mm_10114829-10102LF; 10114829-10102LF; MPN 10114829-10102LF
J6: Conn_01x24_FFC_0.5mm_AFC01-S24FCC-00; Jushuo_AFC01-S24FCC-00_1x24-1MP_P0.50_Horizontal; MPN AFC01-S24FCC-00
JP1: USB_PWR; SolderJumper-2_P1.3mm_Bridged2Bar_Pad1.0x1.5mm
JP2: PIR; SolderJumper-2_P1.3mm_Bridged2Bar_Pad1.0x1.5mm
L1, L2, L4: FB_2A_0805_220R@100MHz_BLM21PG221SN1D; L_0805_2012Metric_Pad1.15x1.40mm_HandSolder; Rating 2A; MPN BLM21PG221SN1D
L3, L5: 10u_1.5A_4x4mm_SWPA4030S100MT; L_Sunlord_SWPA40xxS; Rating 1.5A; MPN SWPA4030S100MT
Q1, Q2, Q5, Q7, Q9, Q10: 2N7002; SOT-23; MPN 2N7002
Q3, Q4, Q6, Q8: AO3401A; SOT-23; MPN AO3401A
R1, R2, R23: 976k_0402_0402WGD9763TCE; R_0402_1005Metric; Tolerance 0.5%; MPN 0402WGD9763TCE
R3, R13, R15, R16, R17, R18, R19, R21, R22, R24, R25, R31, R32: 215k_0402_0402WGD2153TCE; R_0402_1005Metric; Tolerance 0.5%; MPN 0402WGD2153TCE
R4, R5, R28: 1k_0402_0402WGF1001TCE; R_0402_1005Metric; Tolerance 1%; MPN 0402WGF1001TCE
R6, R7, R10, R11, R12, R14, R20, R26, R27, R29, R30: 10k_0402_0402WGF1002TCE; R_0402_1005Metric; Tolerance 1%; MPN 0402WGF1002TCE
R8, R9: 5.1k_0603_0603WAF5101T5E; R_0603_1608Metric; Tolerance 1%; MPN 0603WAF5101T5E
R33: 2.43R_0805_0805W8F243KT5E; R_0805_2012Metric; Tolerance 1%; MPN 0805W8F243KT5E
SW1, SW4: SW_PB_90deg_K2-1102AQ-H4CW-01; MPN K2-1102AQ-N4CW-01
SW2, SW3: SW_PB_TS-1187A-B-A-B; SW_SPST_TL3342; MPN TS-1187A-B-A-B
TP1, TP2, TP3, TP4, TP5, TP6, TP7, TP8, TP9, TP10, TP11, TP12, TP13, TP14, TP15, TP16, TP17, TP18, TP19, TP20, TP21, TP22, TP23, TP24: TestPoint; TestPoint_Pad_D1.0mm
U1: TP4057-42-SOT26-R; SOT-23-6; MPN TP4057-42-SOT26-R
U2, U7: XC6206-2.8V; SOT-23; MPN XC6206-2.8V
U3: PCF85063AT; SO-8_3.9x4.9mm_P1.27mm; MPN PCF85063AT/AAZ
U4: TI_SN74LVC1G373DBVR; SOT-23-6; MPN SN74LVC1G373DBVR
U5: SY8089AAAC; SOT-23-5; MPN SY8089AAAC
U6: PIR_AS312; AS312; MPN AS312
U8: RT9166-12GVL; SOT-23; MPN RT9166-12GVL
U9: AP1511B; SOT-23-6; MPN AP1511B
U10: ESP32-S3-WROOM-1-N16R8; ESP32-S3-WROOM-1; MPN ESP32-S3-WROOM-1-N16R8
U11: MT9284-28J; SOT-23-6; MPN MT9284-28J
U12: LTR-303ALS-01; Lite-On_LTR-303ALS-01; MPN LTR-303ALS-01
Y1: 32.768kHz_Q13FC1350000400; Crystal_SMD_3215-2Pin_3.2x1.5mm; MPN Q13FC1350000400

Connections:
+1V2: C36.1, C54.2, J6.15, TP16.1, U8.2 (VO)
+2V8: C35.1, C57.2, J6.21, TP18.1, U7.2 (VO)
+3.3VA: C27.1, C30.1, C31.1, C53.1, C56.2, J6.14, L4.2, U7.3 (VI), U8.3 (VI)
+3V3: C17.1, C18.2, C19.2, C20.2, C24.2, C25.1, C26.1, C33.2, C34.2, C37.2, C38.1, C39.1, C40.1, C42.1, C44.1, C46.1, C47.1, C55.1, J3.2, J4.1, L3.2, L4.1, Q1.1 (G), Q2.1 (G), R23.1, R26.2, R27.2, R29.1, R30.1, TP22.1, U9.5 (VDD), U10.2 (3V3), U12.1 (VDD)
+5V: C3.2, D5.2 (A2), JP1.2 (B), L1.2, R4.1, R5.1, R10.1, TP23.1, U1.4 (V_{cc})
+BATT: C1.1, C5.1, J1.2, Q3.3 (D), R1.1, TP19.1, U1.3 (BAT)
/BATT_DETECT: C32.1, R1.2, R2.1, TP11.1, U10.39 (GPIO1/TOUCH1/ADC1_CH0)
/CAM.D2: J6.6, U10.7 (GPIO7/TOUCH7/ADC1_CH6)
/CAM.D3: J6.4, U10.5 (GPIO5/TOUCH5/ADC1_CH4)
/CAM.D4: J6.3, U10.4 (GPIO4/TOUCH4/ADC1_CH3)
/CAM.D5: J6.5, U10.6 (GPIO6/TOUCH6/ADC1_CH5)
/CAM.D6: J6.7, U10.8 (GPIO15/U0RTS/ADC2_CH4/XTAL_32K_P)
/CAM.D7: J6.9, U10.10 (GPIO17/U1TXD/ADC2_CH6)
/CAM.D8: J6.11, U10.11 (GPIO18/U1RXD/ADC2_CH7/CLK_OUT3)
/CAM.D9: J6.13, U10.20 (GPIO12/TOUCH12/ADC2_CH1/FSPICLK/FSPIIO6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)
/CAM.HREF: J6.16, U10.33 (MTDO/GPIO40/CLK_OUT2)
/CAM.MCLK: J6.12, U10.12 (GPIO8/TOUCH8/ADC1_CH7/SUBSPICS1)
/CAM.PCLK: C48.1, J6.8, U10.9 (GPIO16/U0CTS/ADC2_CH5/XTAL_32K_NH5)
/CAM.PWDN: J6.17, U10.17 (GPIO9/TOUCH9/ADC1_CH8/FSPIHD/SUBSPIHD)
/CAM.RST: J6.19, U10.19 (GPIO11/TOUCH11/ADC2_CH0/FSPID/FSPIIO5/S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)
/CAM.SCL: J4.11, J6.20, Q1.2 (S), R29.2, U10.15 (GPIO3/TOUCH3/ADC1_CH2), U12.4 (SCL)
/CAM.SDA: J4.13, J6.22, Q2.2 (S), R30.2, U10.21 (GPIO13/TOUCH13/ADC2_CH2/FSPIQ/FSPIIO7/S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), U12.6 (SDA)
/CAM.VSYNC: J6.18, U10.18 (GPIO10/TOUCH10/ADC1_CH9/FSPICS0/FSPIIO4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)
/ESP_BOOT: C21.2, J3.6, J4.5, R26.1, SW2.2, TP2.1, U10.27 (GPIO0/BOOT)
/ESP_EN: C22.2, J3.5, J4.3, R27.1, SW3.2, TP1.1, U10.3 (EN)
/IO38: J4.15, U10.31 (GPIO38/FSPIWP/SUBSPIWP)
/IO39: J4.17, U10.32 (MTCK/GPIO39/CLK_OUT3/SUBSPICS1)
/IRCUT_CTRL: R31.2, TP10.1, U9.3 (FBC), U10.25 (GPIO48/SPICLK_N/SUBSPICLK_N_DIFF)
/IRLED_PWM: R32.2, TP14.1, U10.16 (GPIO46), U11.4 (EN)
/PIR_CTRL_D: R15.2, TP8.1, U4.3 (D), U10.23 (GPIO21)
/PIR_CTRL_LE: R16.2, TP7.1, U4.1 (LE), U10.26 (GPIO45)
/PIR_OUT: Q10.3 (D), U10.24 (GPIO47/SPICLK_P/SUBSPICLK_P_DIFF)
/PWRON_DET: Q9.1 (G), R22.2, SW1.2, U10.38 (GPIO2/TOUCH2/ADC1_CH1)
/PWR_EN: Q7.1 (G), R19.2, TP12.1, U10.22 (GPIO14/TOUCH14/ADC2_CH3/FSPIWP/FSPIDQS/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)
/PWR_PIR: C7.1, C10.1, C16.1, R20.1, SW1.1, TP13.1, U2.2 (VO), U4.5 (VCC), U6.1 (VDD)
/RXD0: J3.8, J4.9, TP5.1, U10.36 (U0RXD/GPIO44/CLK_OUT2)
/TXD0: J3.7, J4.7, TP4.1, U10.37 (U0TXD/GPIO43/CLK_OUT1)
/UD+: D4.2 (A2), J2.A6 (D+), J2.B6 (D+), U10.14 (GPIO20/U1CTS/ADC2_CH9/CLK_OUT1/USB_D+)
/UD-: D3.2 (A2), J2.A7 (D-), J2.B7 (D-), U10.13 (GPIO19/U1RTS/ADC2_CH8/CLK_OUT2/USB_D-)
/USR_BTN: C23.2, SW4.2, U10.34 (MTDI/GPIO41/CLK_OUT1)
/USR_LED: R28.1, U10.35 (MTMS/GPIO42)
GND: C1.2, C2.1, C3.1, C4.1, C5.2, C6.2, C7.2, C9.1, C10.2, C11.2, C12.2, C13.1, C14.2, C15.1, C16.2, C18.1, C19.1, C20.1, C21.1, C22.1, C23.1, C24.1, C25.2, C26.2, C27.2, C28.2, C29.2, C30.2, C31.2, C32.2, C33.1, C34.1, C35.2, C36.2, C37.1, C38.2, C39.2, C40.2, C41.1, C42.2, C43.2, C44.2, C45.1, C46.2, C47.2, C48.2, C49.2, C50.1, C51.1, C52.1, C53.2, C54.1, C55.2, C56.1, C57.1, D3.1 (A1), D4.1 (A1), D5.1 (A1), D7.1 (K), J1.1, J2.A1 (GND), J2.A12 (GND), J2.B1 (GND), J2.B12 (GND), J3.3, J3.4, J4.4, J4.6, J4.8, J4.10, J4.12, J4.14, J4.16, J4.18, J4.19, J4.20, J6.10, J6.23, Q5.2 (S), Q7.2 (S), Q9.2 (S), Q10.2 (S), R2.2, R3.2, R8.2, R9.2, R10.2, R11.2, R12.2, R13.2, R15.1, R16.1, R17.1, R19.1, R21.2, R22.1, R24.2, R25.1, R31.1, R32.1, R33.2, SW2.1, SW3.1, SW4.1, TP3.1, TP6.1, TP9.1, TP15.1, TP17.1, TP20.1, TP24.1, U1.2 (GND), U2.1 (GND), U3.4 (VSS), U4.2 (G), U4.6 (~OE), U5.2 (GND), U6.3 (VSS), U7.1 (GND), U8.1 (GND), U9.2 (GND), U10.1 (GND), U10.40 (GND), U10.41 (GND), U11.2 (GND), U12.3 (GND)
GNDPWR: C2.2, H1.1, H2.1, H3.1, H4.1, J2.S1 (SHIELD), R3.1
unnamed: D1.2 (A), R4.2
unnamed: D1.1 (K), U1.1 (~CHRG)
unnamed: D2.2 (A), R5.2
unnamed: D2.1 (K), U1.5 (~STDBY)
unnamed: D6.2 (A), JP1.1 (A), R14.1
unnamed: D7.2 (A), R28.2
unnamed: D8.2 (A), L5.2, U11.1 (SW)
unnamed: C49.1, C50.2, C51.2, C52.2, D8.1 (K), D9.2 (A), U11.5 (OV)
unnamed: D10.2 (A), D12.1 (K)
unnamed: D10.1 (K), R33.1, U11.3 (FB)
unnamed: D9.1 (K), D11.2 (A)
unnamed: D11.1 (K), D13.2 (A)
unnamed: D12.2 (A), D14.1 (K)
unnamed: D13.1 (K), D15.2 (A)
unnamed: D14.2 (A), D16.1 (K)
unnamed: D15.1 (K), D17.2 (A)
unnamed: D16.2 (A), D18.1 (K)
unnamed: D17.1 (K), D18.2 (A)
unnamed: J2.A5 (CC1), R8.1
unnamed: J2.B5 (CC2), R9.1
unnamed: J2.A4 (VBUS), J2.A9 (VBUS), J2.B4 (VBUS), J2.B9 (VBUS), L1.1
unnamed: J5.1, U9.6 (OUT2)
unnamed: J5.2, U9.4 (OUT1)
unnamed: JP2.1 (A), Q8.3 (D), Q10.1 (G), R25.2
unnamed: JP2.2 (B), Q5.1 (G), R17.2
unnamed: Q1.3 (D), R6.2, U3.6 (SCL)
unnamed: Q2.3 (D), R7.2, U3.5 (SDA)
unnamed: C8.1, Q3.1 (G), Q4.1 (G), R13.1, R14.2
unnamed: C8.2, Q3.2 (S), Q4.2 (S)
unnamed: Q5.3 (D), Q6.1 (G), Q7.3 (D), Q9.3 (D), R18.2, U3.3 (~INT)
unnamed: Q6.3 (D), R21.1, U5.1 (EN)
unnamed: C11.1, C12.1, C13.2, C14.1, C15.2, L2.2, Q6.2 (S), R18.1, U5.4 (IN)
unnamed: Q8.1 (G), R20.2, U4.4 (Q)
unnamed: Q8.2 (S), U6.2 (REL)
unnamed: R11.1, R12.1, U1.6 (PROG)
unnamed: U3.1 (OSCI), Y1.2
unnamed: U3.2 (OSCO), Y1.1
unnamed: C17.2, R23.2, R24.1, U5.5 (FB)
unnamed: L3.1, U5.3 (LX)
unnamed: C28.1, C29.1, U9.1 (CE)
VBUS: C4.2, C6.1, C9.2, C41.2, C43.1, C45.2, D6.1 (K), J3.1, J4.2, L2.1, L5.1, Q4.3 (D), R6.1, R7.1, TP21.1, U2.3 (VI), U3.8 (VDD), U11.6 (VIN)

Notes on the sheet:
Found in AI-Thinker design, purpose is yet to be understood
External MAXLAB ESP32 programmer can be used to flash and interact with the camera via the TagConnect cable
I_{led} = [ V_{fb} = 94mV <->114mV ] / [ ~2.4R ] ~= 40mA
But it is better not to go any higher than 1M in divider resistors, since the output impedance of a divider will be significant enough to interplay with input ADC impedance of the MCU
Pulling both inputs to 0 latches the state of the D-latch
Note: 3v3 and 5v are used as an output here to power the external programmer UART buffers. Internal programmer LDO output must be disabled then
Layout: Put IRCUT driver away from sensitive digital or analog lines
Layout: form a loop of GNDPWR around the PCB Do a via stitching with a spacing <= 20mm (resonant freq of the via cell is ~15 GHz)
Pull-down is included for CAM.RST and CAM.PWDN internally.
TODO: write comments about IO3, IO46, IO45 strappping pins
Bus connections to ESP32 MCU are optimized for easier layout
To prevent USB from powering VBUS completely, just in case
PWR_ON button starts DC-DC. MCU is responsible then for taking over PWR_EN signal The NMOS here is merely to make sure a signal polarity matches logical states (ON is HIGH>0V, OFF is LOW=0V) added benefit is that we no longer need OD MCU output on PWR_EN
Power Down Mode datasheet quote: To initiate hardware power-down, the PWDN pin (pin B6) must be tied to high. When this occurs, the OV2640 internal device clock is halted and all internal counters are reset. The current draw is less than 15 µA in this standby mode
Layout: Put LDOs as close as possible to the camera connector Keep separate "island" for camera connector and LDOs there
TODO: decide if sophisticated AGND connection (layout) is required for camera connector
5K PROG sets charging current to 200 mA
Given OV2640 sensitivity, an optimal LED should be C396643 @ LCSC (I_{max} ~40ma for T <= 60C, f_{peak} = 850nm, MPN: E6C0603IRAC1UDA) Forward drop should be in a region of ~1.6V The driver is capable of driving 7 white LEDs. WLED forward drop should be in the vicinity of ~3V. Meaning, that, hypote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
BATT_DETECT connected straight to the MCU, despite during the power-down condition they might supply some phantom current The hope is that output divider impedance is high enough for the phantom current to be low enough to cause any issue
Dedicated power supply to support the PIR wakeup when main DC-DC is turned off
Projected voltage: ~16V
Layout: Decoupling: keep as close to the camera connector as possible

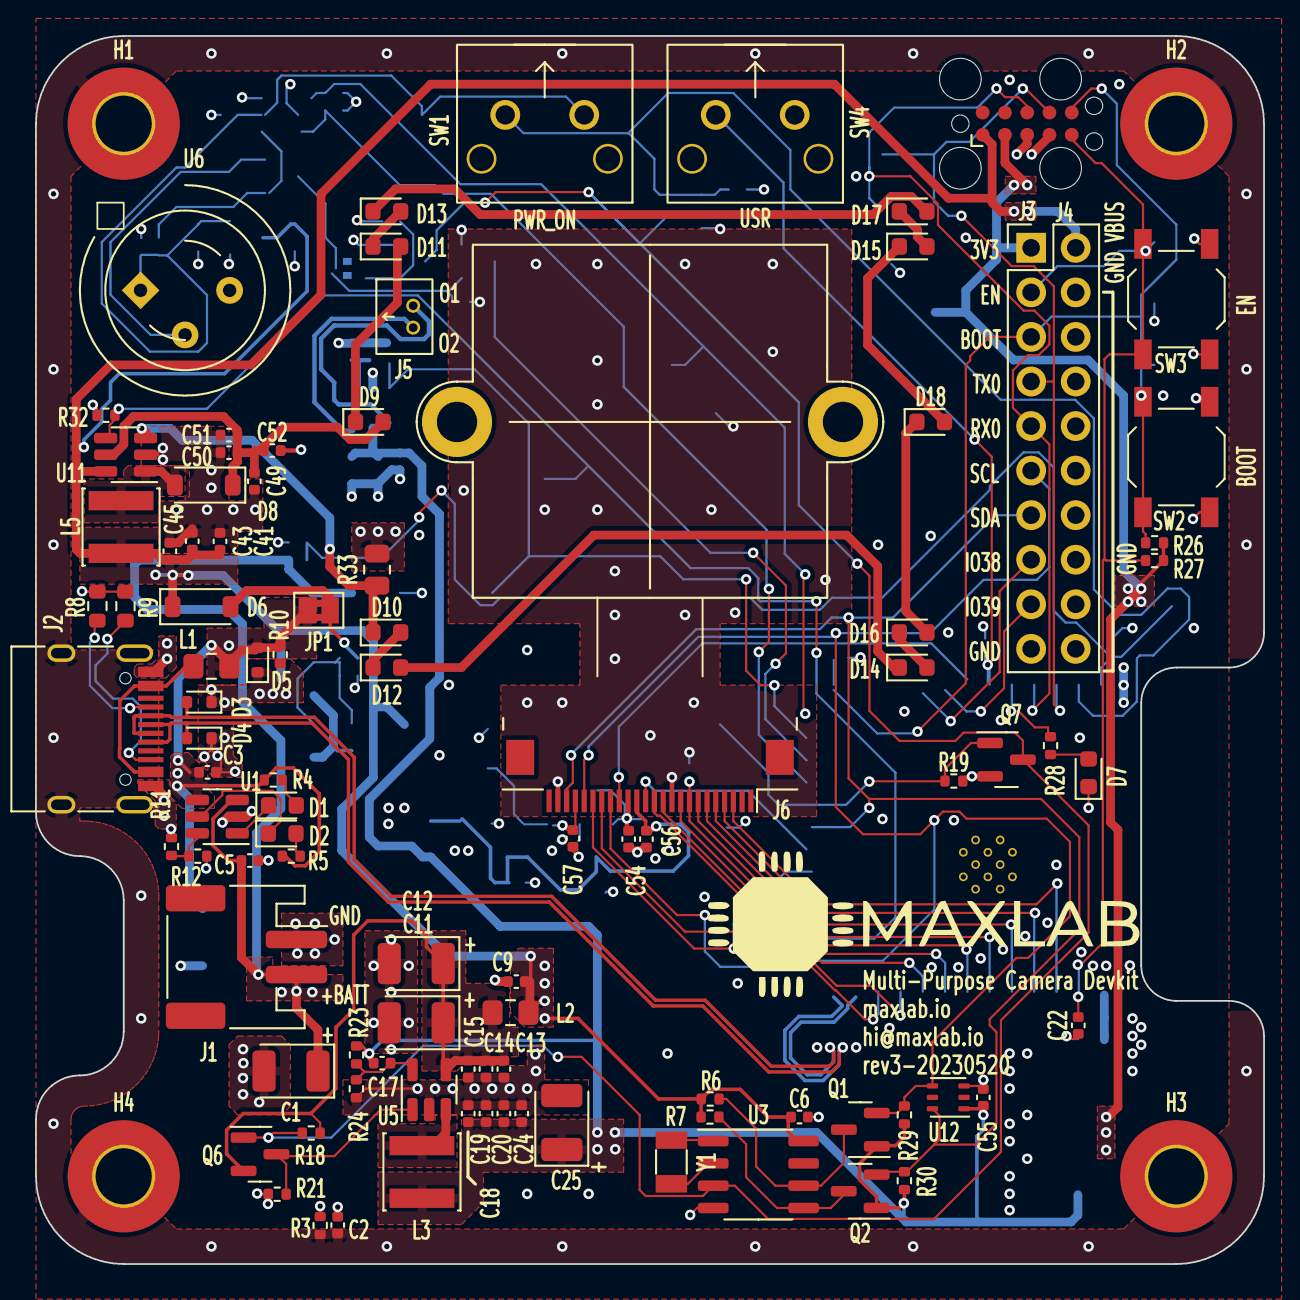
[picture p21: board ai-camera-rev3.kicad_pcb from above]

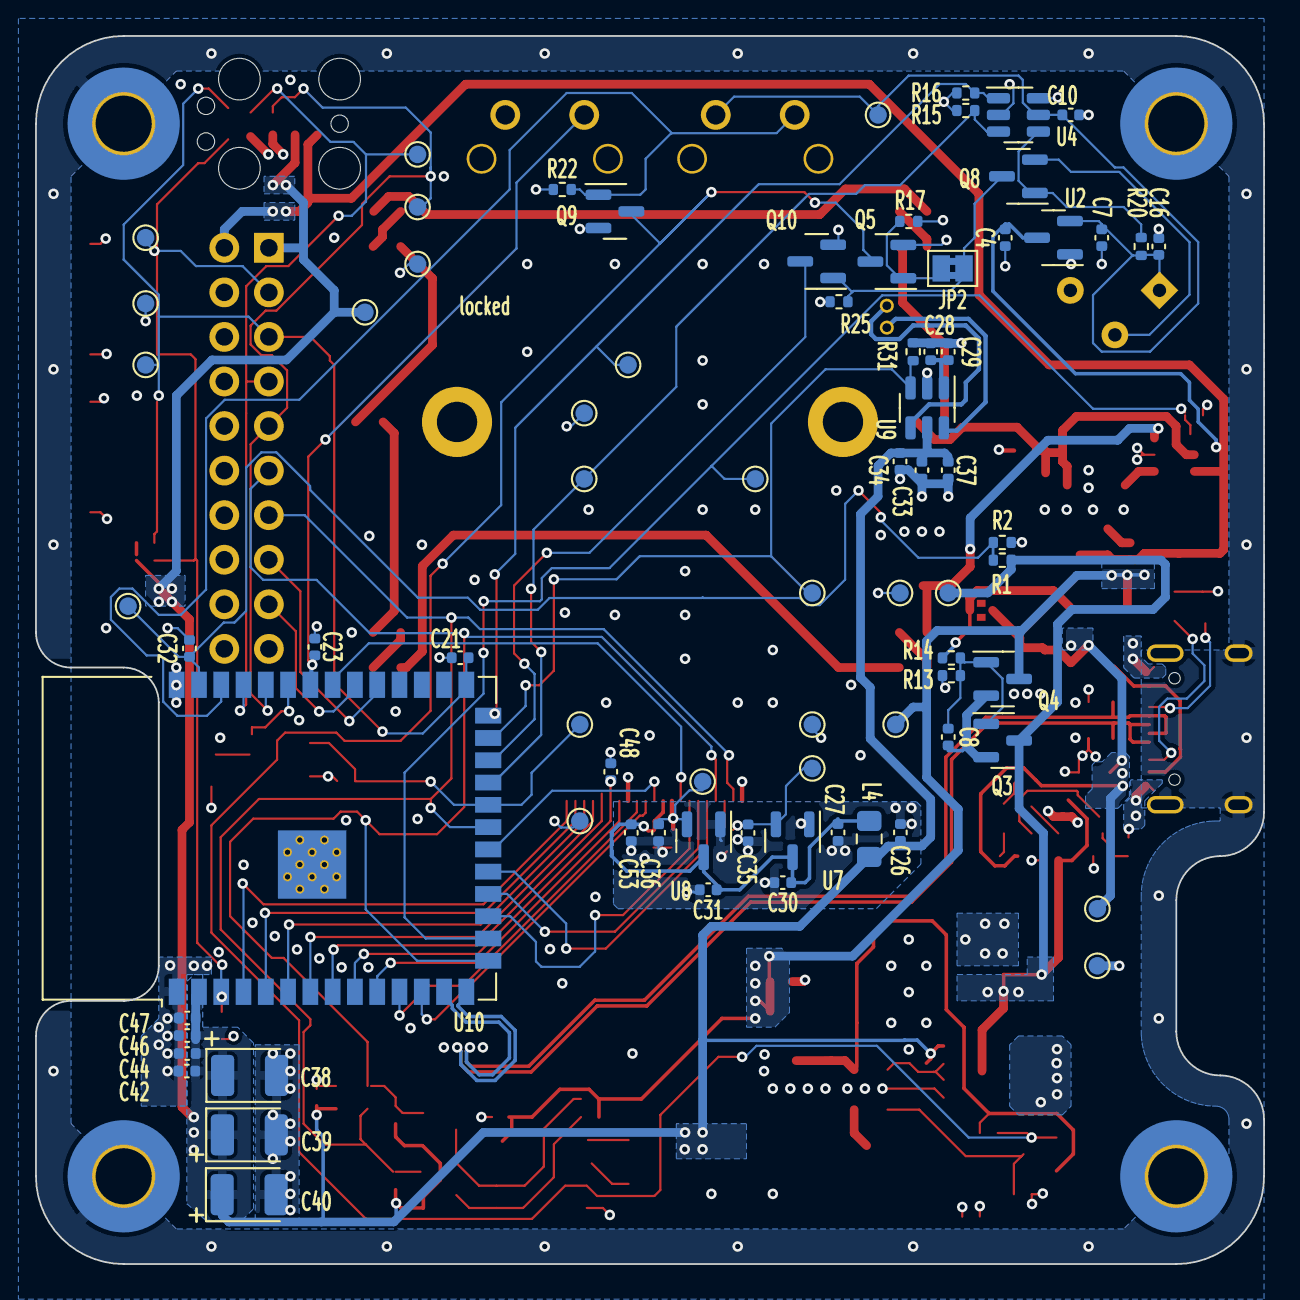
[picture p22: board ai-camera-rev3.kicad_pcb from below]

Board: 4 copper layers, 70.0 x 70.0 mm, 176 parts (77 on the bottom side), 84 nets.

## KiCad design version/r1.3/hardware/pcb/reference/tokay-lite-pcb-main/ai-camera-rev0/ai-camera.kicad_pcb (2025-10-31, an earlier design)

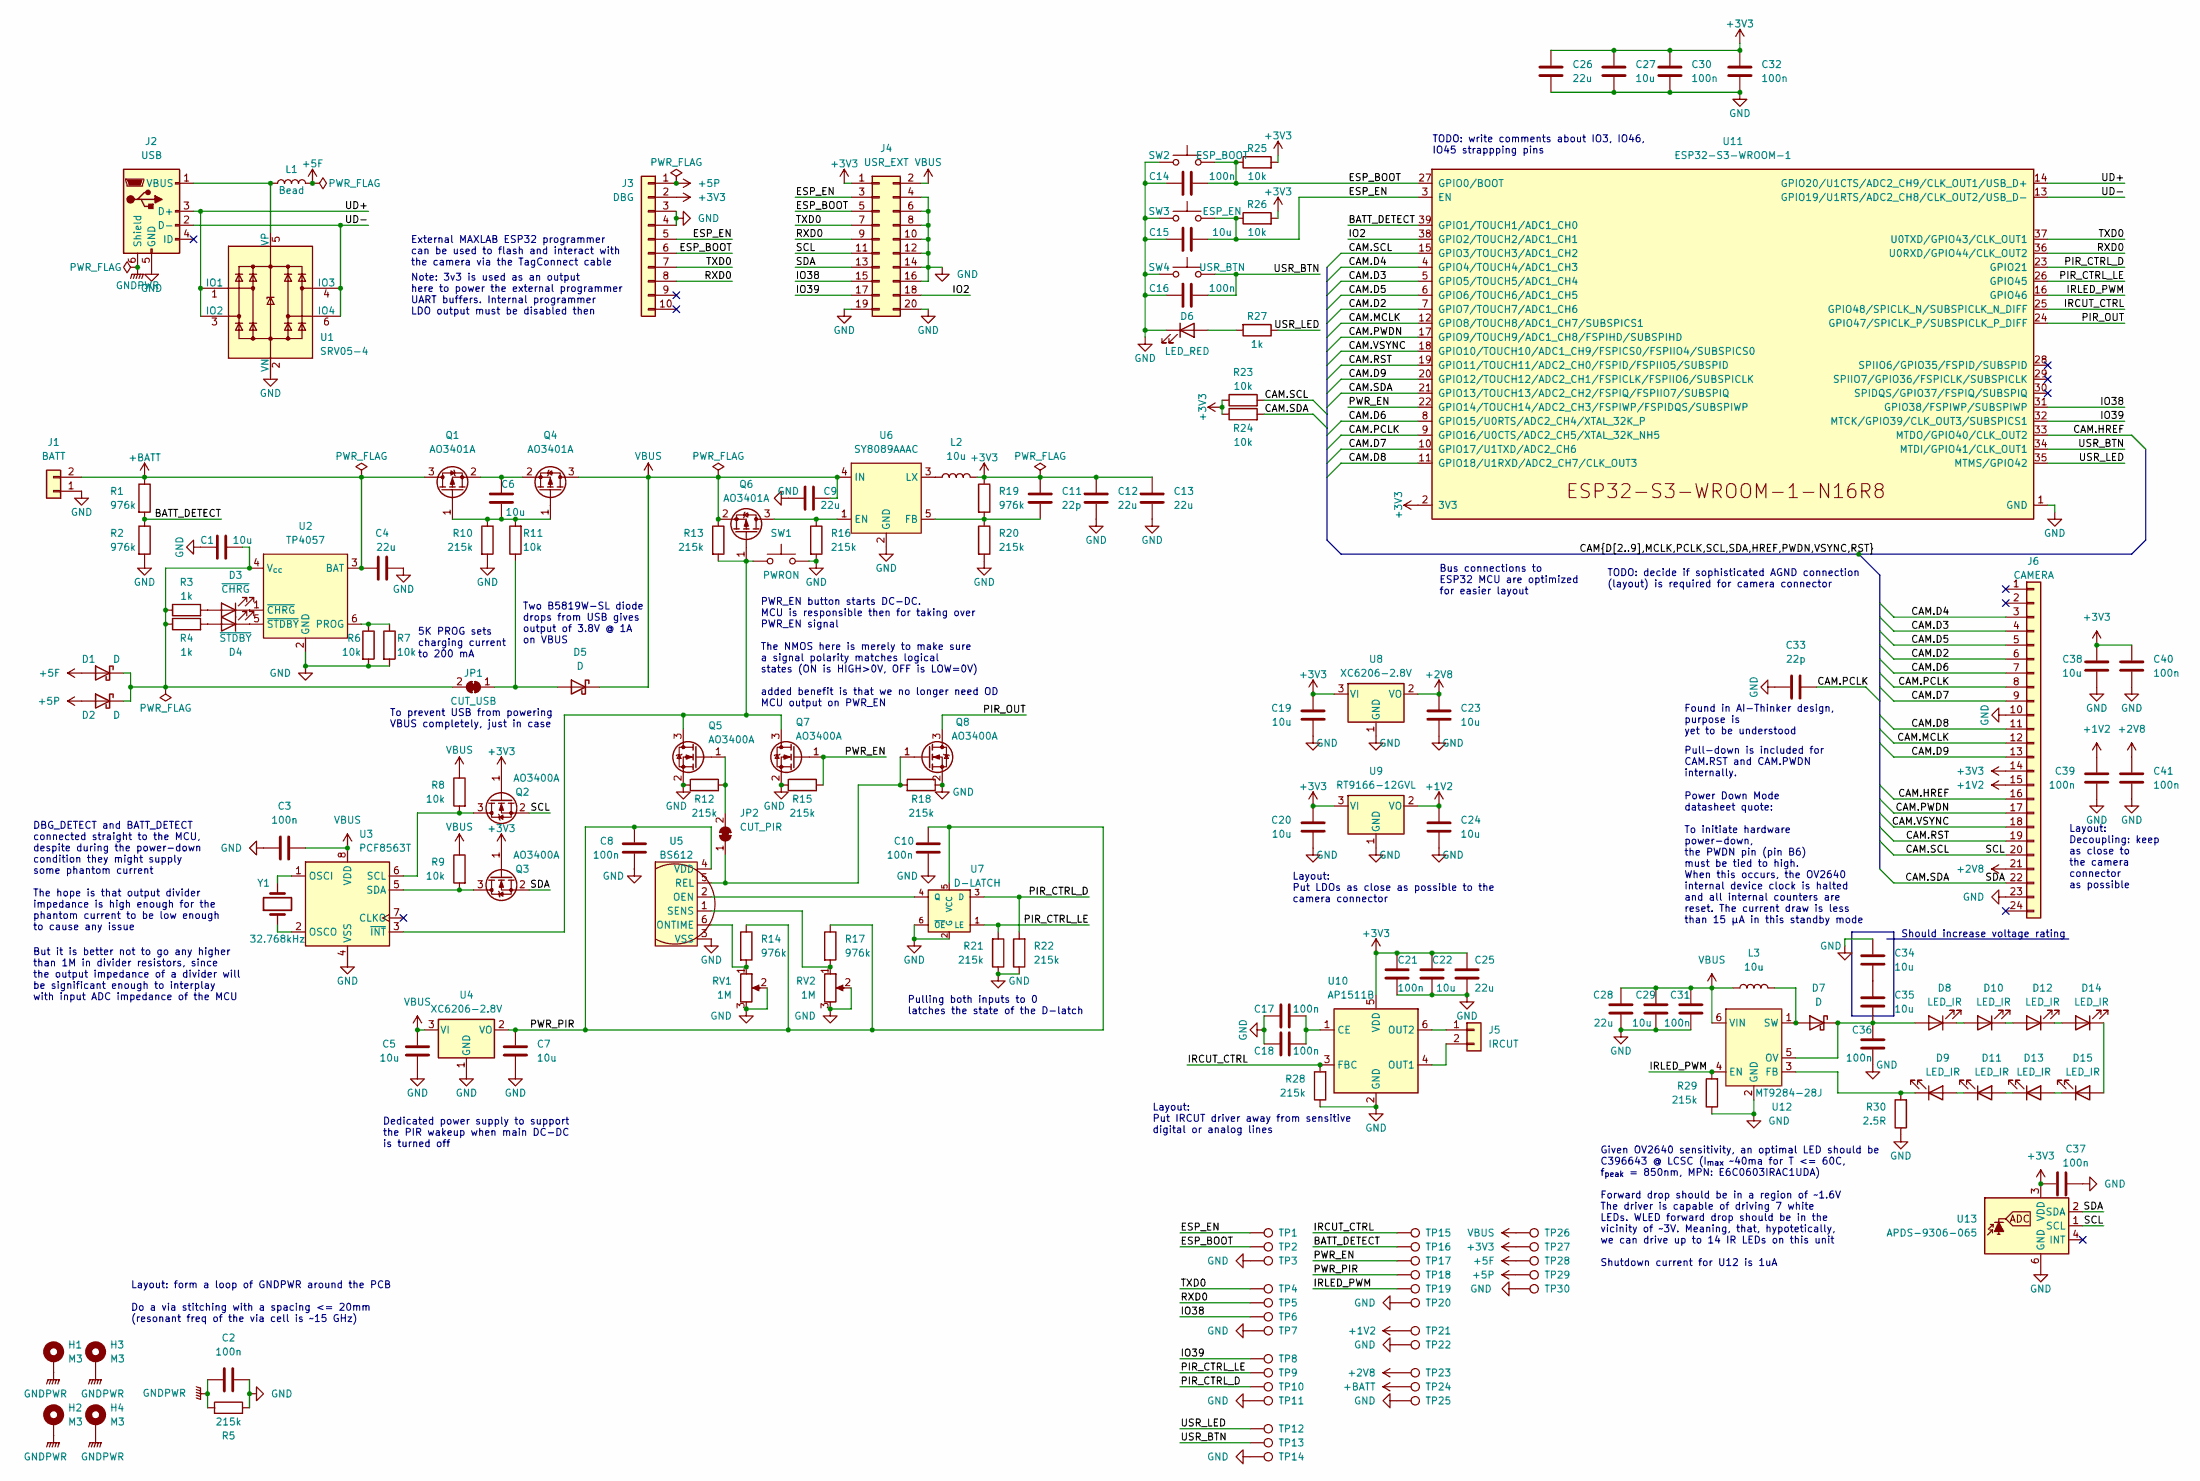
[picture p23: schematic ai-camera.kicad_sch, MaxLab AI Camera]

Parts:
C1, C5, C6, C7, C15, C19, C20, C22, C23, C24, C27, C29, C34, C35, C38: 10u_0603_CL10A106MA8NRNC; C_0603_1608Metric; Rating 25V; Tolerance 20%; MPN CL10A106MA8NRNC
C2, C3, C8, C10, C14, C16, C17, C18, C21, C30, C31, C32, C36, C37, C39, C40, C41: 100n_0402_CL05B104KB54PNC; C_0402_1005Metric; Tolerance 10%; Rating 50V; MPN CL05B104KB54PNC
C4, C9, C12, C13, C25, C26, C28: 22u_0805_CL21A226MAQNNNE; C_0805_2012Metric; Rating 10V; Tolerance 20%; MPN CL21A226MAQNNNE
C11, C33: 22p_0402_0402CG220J500NT; C_0402_1005Metric; Rating 50V; Tolerance 5%; MPN 0402CG220J500NT
D1, D2, D5, D7: B5819W-SL_SOD-123; D_SOD-123; MPN B5819W SL
D3, D6: 0603_RED_KT-0603R; LED_0603_1608Metric; MPN KT-0603R
D4: 0603_GREEN_19-217/GHC-YR1S2/3T; LED_0603_1608Metric; MPN 19-217/GHC-YR1S2/3T
D8, D9, D10, D11, D12, D13, D14, D15: 0603_IR_850nm_E6C0603IRAC1UDA; LED_0603_1608Metric; MPN E6C0603IRAC1UDA
H1, H2, H3, H4: M3; MountingHole_3.2mm_M3_DIN965_Pad_TopBottom
J1: Conn-01x02_P2mm_NONAME_JST-PH_C47647; JST_PH_S2B-PH-SM4-TB_1x02-1MP_P2.00mm_Horizontal; MPN C47647
J2: USB_B_Micro_10118194-0001LF; USB_Micro-B_Amphenol_10118194_Horizontal; MPN 10118194-0001LF
J3: DBG; Tag-Connect_TC2050-IDC-NL_2x05_P1.27mm_Vertical
J4: Conn-02x10_P2.54mm_B-2100S20P-B110; PinHeader_2x10_P2.54mm_Vertical; MPN B-2100S20P-B110
J5: Conn-01x02_P1.25mm_10114829-10102LF; 10114829-10102LF; MPN 10114829-10102LF
J6: Conn_01x24_FFC_0.5mm_hirose_FH12-24S-0.5SH; Hirose_FH12-24S-0.5SH_1x24-1MP_P0.50mm_Horizontal; MPN FH12-24S-0.5SH
JP1: CUT_USB; SolderJumper-2_P1.3mm_Bridged_RoundedPad1.0x1.5mm
JP2: CUT_PIR; SolderJumper-2_P1.3mm_Bridged_RoundedPad1.0x1.5mm
L1: 0805_FB_220R@100MHz_BLM21PG221SN1D; L_0805_2012Metric_Pad1.15x1.40mm_HandSolder; Rating 2A; MPN BLM21PG221SN1D
L2, L3: 10u_SWPA4030S100MT; L_Sunlord_SWPA40xxS; Rating 1.5A; MPN SWPA4030S100MT
Q1, Q4, Q6: AO3401A; SOT-23; MPN AO3401A
Q2, Q3, Q5, Q7, Q8: AO3400A; SOT-23; MPN AO3400A
R1, R2, R14, R17, R19: 976k_0402_0402WGD9763TCE; R_0402_1005Metric; Tolerance 0.5%; MPN 0402WGD9763TCE
R3, R4, R27: 1k_0402_0402WGF1001TCE; R_0402_1005Metric; Tolerance 1%; MPN 0402WGF1001TCE
R5, R10, R12, R13, R15, R16, R18, R20, R21, R22, R28, R29: 215k_0402_0402WGD2153TCE; R_0402_1005Metric; Tolerance 0.5%; MPN 0402WGD2153TCE
R6, R7, R8, R9, R11, R23, R24, R25, R26: 10k_0402_0402WGF1002TCE; R_0402_1005Metric; Tolerance 1%; MPN 0402WGF1002TCE
R30: 2.5R_0805_AR05FTCW2R50; R_0805_2012Metric; Tolerance 1%; MPN AR05FTCW2R50
RV1, RV2: 1M_3362P-1-105; Potentiometer_Vishay_T73YP_Vertical; Tolerance 10%; MPN 3362P-1-105
SW1, SW4: SW_PB_90deg_K2-1102AQ-H4CW-01; MPN K2-1102AQ-H4CW-01
SW2, SW3: SW_PB_TS-1187A-B-A-B; SW_SPST_TL3342; MPN TS-1187A-B-A-B
TP1, TP2, TP3, TP4, TP5, TP6, TP7, TP8, TP9, TP10, TP11, TP12, TP13, TP14, TP15, TP16, TP17, TP18, TP19, TP20, TP21, TP22, TP23, TP24, TP25, TP26, TP27, TP28, TP29, TP30: TP; TestPoint_Pad_D1.5mm
U1: SRV05-4; SOT-23-6; MPN SRV05-4
U2: TP4057-42-SOT26-R; SOT-23-6; MPN TP4057-42-SOT26-R
U3: PCF8563T/5,518; SOIC-8_3.9x4.9mm_P1.27mm; MPN PCF8563T/5,518
U4, U8: XC6206-2.8V; SOT-23; MPN XC6206-2.8V
U5: PIR_BS612; BS612; MPN BS612
U6: SY8089AAAC; SOT-23-5; MPN SY8089AAAC
U7: SOT-23-6_SN74LVC1G373DBVR_TI; SOT-23-6; MPN SN74LVC1G373DBVR
U9: RT9166-12GVL; SOT-23; MPN RT9166-12GVL
U10: AP1511B; SOT-23-6; MPN AP1511B
U11: ESP32-S3-WROOM-1-N16R8; ESP32-S3-WROOM-1; MPN ESP32-S3-WROOM-1-N16R8
U12: MT9284-28J; SOT-23-6; MPN MT9284-28J
U13: APDS-9306-065; Broadcom_DFN-6_2x2mm_P0.65mm; MPN APDS-9306-065
Y1: 32.768kHz_Q13FC1350000400; Crystal_SMD_3215-2Pin_3.2x1.5mm; MPN Q13FC1350000400

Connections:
+1V2: C24.1, C39.2, J6.15, TP21.1, U9.2 (VO)
+2V8: C23.1, C41.2, J6.21, TP23.1, U8.2 (VO)
+3V3: C11.1, C12.1, C13.1, C19.1, C20.1, C21.2, C22.2, C25.2, C26.1, C27.1, C30.1, C32.1, C37.1, C38.1, C40.2, J3.2, J4.1, J6.14, L2.2, Q2.1 (G), Q3.1 (G), R19.1, R23.1, R24.1, R25.2, R26.2, TP27.1, U8.3 (VI), U9.3 (VI), U10.5 (VDD), U11.2 (3V3), U13.3 (VDD)
+5F: D1.2 (A), L1.2, TP28.1
+5P: D2.2 (A), J3.1, TP29.1
+BATT: C4.1, J1.2, Q1.3 (D), R1.1, TP24.1, U2.3 (BAT)
/BATT_DETECT: R1.2, R2.1, TP16.1, U11.39 (GPIO1/TOUCH1/ADC1_CH0)
/CAM.D2: J6.6, U11.7 (GPIO7/TOUCH7/ADC1_CH6)
/CAM.D3: J6.4, U11.5 (GPIO5/TOUCH5/ADC1_CH4)
/CAM.D4: J6.3, U11.4 (GPIO4/TOUCH4/ADC1_CH3)
/CAM.D5: J6.5, U11.6 (GPIO6/TOUCH6/ADC1_CH5)
/CAM.D6: J6.7, U11.8 (GPIO15/U0RTS/ADC2_CH4/XTAL_32K_P)
/CAM.D7: J6.9, U11.10 (GPIO17/U1TXD/ADC2_CH6)
/CAM.D8: J6.11, U11.11 (GPIO18/U1RXD/ADC2_CH7/CLK_OUT3)
/CAM.D9: J6.13, U11.20 (GPIO12/TOUCH12/ADC2_CH1/FSPICLK/FSPIIO6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)
/CAM.HREF: J6.16, U11.33 (MTDO/GPIO40/CLK_OUT2)
/CAM.MCLK: J6.12, U11.12 (GPIO8/TOUCH8/ADC1_CH7/SUBSPICS1)
/CAM.PCLK: C33.1, J6.8, U11.9 (GPIO16/U0CTS/ADC2_CH5/XTAL_32K_NH5)
/CAM.PWDN: J6.17, U11.17 (GPIO9/TOUCH9/ADC1_CH8/FSPIHD/SUBSPIHD)
/CAM.RST: J6.19, U11.19 (GPIO11/TOUCH11/ADC2_CH0/FSPID/FSPIIO5/S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)
/CAM.SCL: J4.11, J6.20, Q2.2 (S), R23.2, U11.15 (GPIO3/TOUCH3/ADC1_CH2), U13.1 (SCL)
/CAM.SDA: J4.13, J6.22, Q3.2 (S), R24.2, U11.21 (GPIO13/TOUCH13/ADC2_CH2/FSPIQ/FSPIIO7/S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), U13.2 (SDA)
/CAM.VSYNC: J6.18, U11.18 (GPIO10/TOUCH10/ADC1_CH9/FSPICS0/FSPIIO4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)
/ESP_BOOT: C14.2, J3.6, J4.5, R25.1, SW2.2, TP2.1, U11.27 (GPIO0/BOOT)
/ESP_EN: C15.2, J3.5, J4.3, R26.1, SW3.2, TP1.1, U11.3 (EN)
/IO2: J4.18, U11.38 (GPIO2/TOUCH2/ADC1_CH1)
/IO38: J4.15, TP6.1, U11.31 (GPIO38/FSPIWP/SUBSPIWP)
/IO39: J4.17, TP8.1, U11.32 (MTCK/GPIO39/CLK_OUT3/SUBSPICS1)
/IRCUT_CTRL: R28.2, TP15.1, U10.3 (FBC), U11.25 (GPIO48/SPICLK_N/SUBSPICLK_N_DIFF)
/IRLED_PWM: R29.2, TP19.1, U11.16 (GPIO46), U12.4 (EN)
/PIR_CTRL_D: R22.2, TP10.1, U7.3 (D), U11.23 (GPIO21)
/PIR_CTRL_LE: R21.2, TP9.1, U7.1 (LE), U11.26 (GPIO45)
/PIR_OUT: Q8.3 (D), U11.24 (GPIO47/SPICLK_P/SUBSPICLK_P_DIFF)
/PWR_EN: Q7.1 (G), R15.2, TP17.1, U11.22 (GPIO14/TOUCH14/ADC2_CH3/FSPIWP/FSPIDQS/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)
/PWR_PIR: C7.1, C8.1, C10.1, R14.1, R17.1, TP18.1, U4.2 (VO), U5.4 (VDD), U7.5 (VCC)
/RXD0: J3.8, J4.9, TP5.1, U11.36 (U0RXD/GPIO44/CLK_OUT2)
/TXD0: J3.7, J4.7, TP4.1, U11.37 (U0TXD/GPIO43/CLK_OUT1)
/UD+: J2.3 (D+), U1.1 (IO1), U1.3 (IO2), U11.14 (GPIO20/U1CTS/ADC2_CH9/CLK_OUT1/USB_D+)
/UD-: J2.2 (D-), U1.4 (IO3), U1.6 (IO4), U11.13 (GPIO19/U1RTS/ADC2_CH8/CLK_OUT2/USB_D-)
/USR_BTN: C16.2, SW4.2, TP13.1, U11.34 (MTDI/GPIO41/CLK_OUT1)
/USR_LED: R27.1, TP12.1, U11.35 (MTMS/GPIO42)
GND: C1.1, C2.1, C3.2, C4.2, C5.1, C7.2, C8.2, C9.2, C10.2, C12.2, C13.2, C14.1, C15.1, C16.1, C17.2, C18.2, C19.2, C20.2, C21.1, C22.1, C23.2, C24.2, C25.1, C26.2, C27.2, C28.1, C29.1, C30.2, C31.1, C32.2, C33.2, C34.1, C36.1, C37.2, C38.2, C39.1, C40.1, C41.1, D6.1 (K), J1.1, J2.5 (GND), J3.3, J3.4, J4.4, J4.6, J4.8, J4.10, J4.12, J4.14, J4.16, J4.19, J4.20, J6.10, J6.23, Q5.2 (S), Q7.2 (S), Q8.2 (S), R2.2, R5.2, R6.2, R7.2, R10.2, R12.1, R15.1, R16.2, R18.1, R20.2, R21.1, R22.1, R28.1, R29.1, R30.1, RV1.2, RV1.3, RV2.2, RV2.3, SW1.2, SW2.1, SW3.1, SW4.1, TP3.1, TP7.1, TP11.1, TP14.1, TP20.1, TP22.1, TP25.1, TP30.1, U1.2 (VN), U2.2 (GND), U3.4 (VSS), U4.1 (GND), U5.3 (VSS), U6.2 (GND), U7.2 (G), U7.6 (~OE), U8.1 (GND), U9.1 (GND), U10.2 (GND), U11.1 (GND), U11.40 (GND), U11.41 (GND), U12.2 (GND), U13.6 (GND)
GNDPWR: C2.2, H1.1, H2.1, H3.1, H4.1, J2.6 (Shield), R5.1
unnamed: C1.2, D1.1 (K), D2.1 (K), JP1.2 (B), R3.1, R4.1, U2.4 (V_{cc})
unnamed: C6.1, Q1.1 (G), Q4.1 (G), R10.1, R11.2
unnamed: C6.2, Q1.2 (S), Q4.2 (S)
unnamed: C11.2, R19.2, R20.1, U6.5 (FB)
unnamed: C17.1, C18.1, U10.1 (CE)
unnamed: C34.2, C35.2
unnamed: C35.1, C36.2, D7.1 (K), D8.2 (A), U12.5 (OV)
unnamed: D3.1 (K), U2.1 (~CHRG)
unnamed: D3.2 (A), R3.2
unnamed: D4.1 (K), U2.5 (~STDBY)
unnamed: D4.2 (A), R4.2
unnamed: D5.2 (A), JP1.1 (A), R11.1
unnamed: D6.2 (A), R27.2
unnamed: D7.2 (A), L3.2, U12.1 (SW)
unnamed: D9.1 (K), R30.2, U12.3 (FB)
unnamed: D10.1 (K), D12.2 (A)
unnamed: D8.1 (K), D10.2 (A)
unnamed: D9.2 (A), D11.1 (K)
unnamed: D11.2 (A), D13.1 (K)
unnamed: D12.1 (K), D14.2 (A)
unnamed: D13.2 (A), D15.1 (K)
unnamed: D14.1 (K), D15.2 (A)
unnamed: J2.1 (VBUS), L1.1, U1.5 (VP)
unnamed: J5.1, U10.6 (OUT2)
unnamed: J5.2, U10.4 (OUT1)
unnamed: JP2.1 (A), Q8.1 (G), R18.2, U5.5 (REL)
unnamed: JP2.2 (B), Q5.1 (G), R12.2
unnamed: L2.1, U6.3 (LX)
unnamed: Q2.3 (D), R8.2, U3.6 (SCL)
unnamed: Q3.3 (D), R9.2, U3.5 (SDA)
unnamed: Q5.3 (D), Q6.1 (G), Q7.3 (D), R13.2, SW1.1, U3.3 (~INT)
unnamed: Q6.3 (D), R16.1, U6.1 (EN)
unnamed: R6.1, R7.1, U2.6 (PROG)
unnamed: R14.2, RV1.1, U5.6 (ONTIME)
unnamed: R17.2, RV2.1, U5.1 (SENS)
unnamed: U3.1 (OSCI), Y1.2
unnamed: U3.2 (OSCO), Y1.1
unnamed: U5.2 (OEN), U7.4 (Q)
VBUS: C3.1, C5.2, C9.1, C28.2, C29.2, C31.2, D5.1 (K), J4.2, L3.1, Q4.3 (D), Q6.2 (S), R8.1, R9.1, R13.1, TP26.1, U3.8 (VDD), U4.3 (VI), U6.4 (IN), U12.6 (VIN)

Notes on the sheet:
Found in AI-Thinker design, purpose is yet to be understood
External MAXLAB ESP32 programmer can be used to flash and interact with the camera via the TagConnect cable
But it is better not to go any higher than 1M in divider resistors, since the output impedance of a divider will be significant enough to interplay with input ADC impedance of the MCU
Pulling both inputs to 0 latches the state of the D-latch
Note: 3v3 is used as an output here to power the external programmer UART buffers. Internal programmer LDO output must be disabled then
Layout: Put IRCUT driver away from sensitive digital or analog lines
Layout: form a loop of GNDPWR around the PCB Do a via stitching with a spacing <= 20mm (resonant freq of the via cell is ~15 GHz)
Pull-down is included for CAM.RST and CAM.PWDN internally.
Two B5819W-SL diode drops from USB gives output of 3.8V @ 1A on VBUS
Should increase voltage rating
TODO: write comments about IO3, IO46, IO45 strappping pins
Bus connections to ESP32 MCU are optimized for easier layout
To prevent USB from powering VBUS completely, just in case
PWR_EN button starts DC-DC. MCU is responsible then for taking over PWR_EN signal The NMOS here is merely to make sure a signal polarity matches logical states (ON is HIGH>0V, OFF is LOW=0V) added benefit is that we no longer need OD MCU output on PWR_EN
Power Down Mode datasheet quote: To initiate hardware power-down, the PWDN pin (pin B6) must be tied to high. When this occurs, the OV2640 internal device clock is halted and all internal counters are reset. The current draw is less than 15 µA in this standby mode
Layout: Put LDOs as close as possible to the camera connector
TODO: decide if sophisticated AGND connection (layout) is required for camera connector
5K PROG sets charging current to 200 mA
Given OV2640 sensitivity, an optimal LED should be C396643 @ LCSC (I_{max} ~40ma for T <= 60C, f_{peak} = 850nm, MPN: E6C0603IRAC1UDA) Forward drop should be in a region of ~1.6V The driver is capable of driving 7 white LEDs. WLED forward drop should be in the vicinity of ~3V. Meaning, that, hypote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
DBG_DETECT and BATT_DETECT connected straight to the MCU, despite during the power-down condition they might supply some phantom current The hope is that output divider impedance is high enough for the phantom current to be low enough to cause any issue
Dedicated power supply to support the PIR wakeup when main DC-DC is turned off
Layout: Decoupling: keep as close to the camera connector as possible

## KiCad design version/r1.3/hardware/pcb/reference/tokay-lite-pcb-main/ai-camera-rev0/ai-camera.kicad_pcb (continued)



Board: 4 copper layers, 70.0 x 70.0 mm, 159 parts (86 on the bottom side), 82 nets.

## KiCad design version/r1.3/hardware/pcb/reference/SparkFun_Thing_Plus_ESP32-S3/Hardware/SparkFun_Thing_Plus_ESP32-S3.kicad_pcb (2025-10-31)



Board: 4 copper layers, 22.9 x 58.4 mm, 137 parts (53 on the bottom side), 53 nets.

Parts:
C1: 22uF; C_0603_1608Metric
C2, C5, C8, C11: 0.1uF; C_0402_1005Metric
C3, C4: 10uF; C_0402_1005Metric
C6, C13: 1.0uF; C_0402_1005Metric
C7, C12: 4.7uF; C_0402_1005Metric
C9: 4.7uF; C_0603_1608Metric
C10, C14: 2.2uF; C_0402_1005Metric
D1: Green; LED_0603_1608Metric_Green
D2, D3: BAT60A; SOD-323
D4: Yellow; LED_0603_1608Metric_Yellow
D5: Red; LED_0603_1608Metric_Red
D6: WS2812B; WS2812_2020
FID1, FID2, FID3, FID4: Fiducial_0.5mm; Fiducial_0.5mm_Mask1mm
G3: OSHW_Logo; Creative_Commons_License
J1: USB_C_Receptacle; USB-C_16
J2: microSD_Friction; microSD_Friction_Fit_Common
J3: JST_2mm_LiPo; JST_SMD_2.0mm-2
J4: Qwiic_RA; JST_SMD_1.0mm-4_RA
JP1, JP2, JP3: Jumper_2_NC_Trace
R1, R2, R3, R4, R5, R6, R8, R17: 10k; R_0402_1005Metric
R7: 330; R_0402_1005Metric
R9: 4.7k; R_0402_1005Metric
R10, R11: 5.1k; R_0402_1005Metric
R12, R15: 2.2k; R_0402_1005Metric
R13, R19: 100k; R_0402_1005Metric
R14: 1k; R_0402_1005Metric
R16: 2.0k; R_0402_1005Metric
Ref**: Val**; OSHW_Logo_2.5mm
ST1, ST3: Standoff
SW1, SW2: SMD_4.6x2.8mm_h2.5mm; Push_SMD_4.6x2.8mm_h2.5mm
TP1, TP2: 1.0mm; TestPoint-1.0mm
U1, U6: RT9080-3.3; SOT23-5
U2: DT1042-04SO; SOT23-6
U3: ESP32-S3-MINI; ESP32-MINI
U4: MAX17048; DFN-8
U5: MCP73831; SOT23-5
U9: Ordering_Instructions
U10: ThingPlus
kibuzzard-65A99A9C: G***; kibuzzard-65A99A9C
kibuzzard-65A99AA3: G***; kibuzzard-65A99AA3
kibuzzard-65A99E72: G***; kibuzzard-65A99E72
kibuzzard-65A403E0: G***; kibuzzard-65A403E0
kibuzzard-65A992E3: G***; kibuzzard-65A992E3
kibuzzard-65A9923A: G***; kibuzzard-65A9923A
kibuzzard-65A9926C: G***; kibuzzard-65A9926C
kibuzzard-65A9926F: G***; kibuzzard-65A9926F
kibuzzard-65A9927C: G***; kibuzzard-65A9927C
kibuzzard-65A9927F: G***; kibuzzard-65A9927F
kibuzzard-65A9928A: G***; kibuzzard-65A9928A
kibuzzard-65A9928E: G***; kibuzzard-65A9928E
kibuzzard-65A9933C: G***; kibuzzard-65A9933C
kibuzzard-65A9934B: G***; kibuzzard-65A9934B
kibuzzard-65A9935C: G***; kibuzzard-65A9935C
kibuzzard-65A9936B: G***; kibuzzard-65A9936B
kibuzzard-65A9990D: G***; kibuzzard-65A9990D
kibuzzard-65A99252: G***; kibuzzard-65A99252
kibuzzard-65A99268: G***; kibuzzard-65A99268
kibuzzard-65A99274: G***; kibuzzard-65A99274
kibuzzard-65A99278: G***; kibuzzard-65A99278
kibuzzard-65A99283: G***; kibuzzard-65A99283
kibuzzard-65A99287: G***; kibuzzard-65A99287
kibuzzard-65A99292: G***; kibuzzard-65A99292
kibuzzard-65A99297: G***; kibuzzard-65A99297
kibuzzard-65A99335: G***; kibuzzard-65A99335
kibuzzard-65A99346: G***; kibuzzard-65A99346
kibuzzard-65A99350: G***; kibuzzard-65A99350
kibuzzard-65A99354: G***; kibuzzard-65A99354
kibuzzard-65A99359: G***; kibuzzard-65A99359
kibuzzard-65A99360: G***; kibuzzard-65A99360
kibuzzard-65A99364: G***; kibuzzard-65A99364
kibuzzard-65A99367: G***; kibuzzard-65A99367
kibuzzard-65A99912: G***; kibuzzard-65A99912
kibuzzard-65A99933: G***; kibuzzard-65A99933
kibuzzard-65AA9C9F: G***; kibuzzard-65AA9C9F
kibuzzard-656A3D93: G***; kibuzzard-656A3D93
kibuzzard-656A31AF: G***; kibuzzard-656A31AF
kibuzzard-656A32A0: G***; kibuzzard-656A32A0
kibuzzard-656A32FE: G***; kibuzzard-656A32FE
kibuzzard-656A35A5: G***; kibuzzard-656A35A5
kibuzzard-656A35AD: G***; kibuzzard-656A35AD
kibuzzard-656A35B5: G***; kibuzzard-656A35B5
kibuzzard-656A35BC: G***; kibuzzard-656A35BC
kibuzzard-656A35C4: G***; kibuzzard-656A35C4
kibuzzard-656A36A2: G***; kibuzzard-656A36A2
kibuzzard-656A36A7: G***; kibuzzard-656A36A7
kibuzzard-656A36C2: G***; kibuzzard-656A36C2
kibuzzard-656A47C5: G***; kibuzzard-656A47C5
kibuzzard-656A359E: G***; kibuzzard-656A359E
kibuzzard-656A361F: G***; kibuzzard-656A361F
kibuzzard-656A367B: G***; kibuzzard-656A367B
kibuzzard-656A368C: G***; kibuzzard-656A368C
kibuzzard-656A482A: G***; kibuzzard-656A482A
kibuzzard-656A3526: G***; kibuzzard-656A3526
kibuzzard-656A3552: G***; kibuzzard-656A3552
kibuzzard-656A3559: G***; kibuzzard-656A3559
kibuzzard-656A3560: G***; kibuzzard-656A3560
kibuzzard-656A3567: G***; kibuzzard-656A3567
kibuzzard-656A3591: G***; kibuzzard-656A3591
kibuzzard-656A3598: G***; kibuzzard-656A3598
kibuzzard-656A3668: G***; kibuzzard-656A3668
kibuzzard-656A3687: G***; kibuzzard-656A3687
kibuzzard-656A3691: G***; kibuzzard-656A3691
kibuzzard-656A3878: G***; kibuzzard-656A3878
kibuzzard-656A4896: G***; kibuzzard-656A4896
kibuzzard-6569BE4A: G***; kibuzzard-6569BE4A
kibuzzard-6569BE28: G***; kibuzzard-6569BE28
kibuzzard-6569BE57: G***; kibuzzard-6569BE57
kibuzzard-6569BF02: G***; kibuzzard-6569BF02
kibuzzard-6569F7FC: G***; kibuzzard-6569F7FC
kibuzzard-6569F8A4: G***; kibuzzard-6569F8A4

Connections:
3.3V: C1.2, C7.1, C11.1, C13.1, JP1.2 (B), JP2.2 (B), R8.1, U3.3 (3V3), U6.5 (VOUT), U10.27 (3.3V)
3.3V_P: C3.1, C4.1, C5.1, C8.1, D6.4 (VDD), J2.4 (VDD), J4.2, R1.1, R2.1, R3.1, R4.1, R5.1, R6.1, R12.1, R15.1, U1.5 (VOUT)
EN: R13.2, U6.3 (EN), U10.11 (EN)
ESP0/STAT: R7.1, SW1.1, TP2.1, U3.4 (IO0)
ESP1: U3.5 (IOA1), U10.3 (GPIO6)
ESP2: U3.6 (IOA2), U10.4 (GPIO5)
ESP4: U3.8 (IOA4), U10.5 (GPIO4)
ESP5: U3.9 (IOA5), U10.6 (GPIO3)
ESP6: U3.10 (IOA6), U10.7 (GPIO2)
ESP7: U3.11 (IOA7), U10.8 (GPIO1)
ESP8/SDA: J4.3, R15.2, U3.12 (IOA8), U4.8 (SDA), U10.1 (SDA)
ESP9/SCL: J4.4, R12.2, U3.13 (IOA9), U4.7 (SCL), U10.2 (SCL)
ESP10/A0: U3.14 (IOA10), U10.24 (A0)
ESP11/PICO: U3.15 (IOA11), U10.17 (PICO)
ESP12/SCK: U3.16 (IOA12), U10.18 (SCK)
ESP13/POCI: U3.17 (IOA13), U10.16 (POCI)
ESP14/A1: U3.18 (IOA14), U10.23 (A1)
ESP15/A2: U3.19 (IOA15), U10.22 (A2)
ESP16/A3: U3.20 (IOA16), U10.21 (A3)
ESP17/A4: U3.21 (IOA17), U10.20 (A4)
ESP18/A5: U3.22 (IOA18), U10.19 (A5)
ESP19/D-: J1.A7 (D-), J1.B7 (D-), U2.4 (I/O3), U3.23 (IOA19)
ESP20/D+: J1.A6 (D+), J1.B6 (D+), U2.6 (I/O4), U3.24 (IOA20)
ESP21: U3.25 (IO21), U10.9 (GPIO0)
ESP33/SDIO3: J2.2 (DAT3/~CS), R6.2, U3.28 (IO33)
ESP34/SDIO_CMD: J2.3 (CMD/SDI), R1.2, U3.29 (IO34)
ESP35/~ALRT: U3.31 (IO35), U4.5 (~ALRT)
ESP38/SDIO_CLK: J2.5 (CLK/SCK), R2.2, U3.34 (IO38)
ESP39/SDIO0: J2.7 (DAT0/SDO), R3.2, U3.35 (IO39)
ESP40/SDIO1: J2.8 (DAT1), R4.2, U3.36 (IO40)
ESP42/FREE: U3.38 (IO42), U10.13 (FREEBIE)
ESP43/TXO: U3.39 (TXD0/IO43), U10.14 (TX)
ESP44/RXI: U3.40 (RXD0/IO44), U10.15 (RX)
ESP45/Q_EN: R17.2, R19.1, U1.3 (EN), U3.41 (IO45)
ESP46/LED: D6.3 (DIN), U3.44 (IO46)
ESP47/SDIO2: J2.1 (DAT2), R5.2, U3.27 (IO47)
ESP48/SDIO_~DET: J2.9 (DET), U3.30 (IO48)
ESP~RST: C6.1, R8.2, SW2.1, U3.45 (EN), U10.28 (~RESET)
GND: C1.1, C2.2, C3.2, C4.2, C5.2, C6.2, C7.2, C8.2, C9.2, C10.2, C11.2, C12.2, C13.2, C14.2, D1.1 (K), D5.1 (K), D6.2 (VSS), J1.GND, J1.S (SHIELD), J2.6 (VSS), J2.10 (SHIELD), J3.1 (-), J4.1, R10.1, R11.2, R16.2, R19.2, SW1.2, SW2.2, U1.2 (GND), U2.2 (GND), U3.1 (GND), U3.2 (GND), U3.42 (GND), U3.43 (GND), U3.46 (GND), U3.47 (GND), U3.48 (GND), U3.49 (GND), U3.50 (GND), U3.51 (GND), U3.52 (GND), U3.53 (GND), U3.54 (GND), U3.55 (GND), U3.56 (GND), U3.57 (GND), U3.58 (GND), U3.59 (GND), U3.60 (GND), U3.61 (GND), U3.62 (GND), U3.63 (GND), U3.64 (GND), U3.65 (GND), U4.1 (CTG), U4.4 (GND), U4.6 (QSTRT), U4.9 (GND), U5.2 (GND), U6.2 (GND), U10.25 (GND)
unnamed: D1.2 (A), R7.2
unnamed: D4.2 (A), R14.1
unnamed: D4.1 (K), U5.1 (STAT)
unnamed: D5.2 (A), R9.2
unnamed: D6.1 (DOUT), TP1.1
unnamed: J1.A5 (CC1), R11.1
unnamed: J1.B5 (CC2), R10.2
unnamed: JP1.1 (A), R9.1
unnamed: JP2.1 (A), R17.1
unnamed: JP3.1 (A), R14.2
unnamed: R16.1, U5.5 (PROG)
VBATT: C2.1, C12.1, D3.A, J3.2 (+), U4.2 (CELL), U4.3 (VDD), U5.3 (V_{BAT}), U10.12 (V_BATT)
VIN: C10.1, C14.1, D2.C, D3.C, R13.1, U1.1 (VIN), U6.1 (VIN)
VUSB: C9.1, D2.A, J1.VBUS, JP3.2 (B), U2.5 (VCC), U5.4 (VIN), U10.10 (V_USB)

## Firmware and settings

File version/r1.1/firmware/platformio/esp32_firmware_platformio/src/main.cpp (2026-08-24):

/**
 * MiniSpeedCam - ESP32 Firmware (Hardware revision 1.1)
 * -----------------------------------------------------
 * Top-level entry point for the MiniSpeedCam ESP32-S3.
 *
 * High-level responsibilities:
 *   - Polls the STM32 (which performs FFT on the CDM324 radar signal)
 *     over UART for the current vehicle speed.
 *   - When speed crosses the user-configured threshold, captures a JPEG
 *     from the OV2640 camera and POSTs it (base64-encoded) along with
 *     the maximum measured speed to minispeedcam.com.
 *   - Hosts a self-hosted web config portal (esp_http_server on :80, over
 *     WiFi STA or a captive AP if no credentials are stored) for configuring
 *     WiFi, units (MPH/KPH), minimum tracking speed, and photo trigger speed.
 *   - Implements a two-task split across the dual-core ESP32:
 *       Core 1 (Task1) - radar polling, sleep management, DNS.
 *       Core 0 (Task0) - HTTPS uploads and (re)connecting to WiFi.
 *
 * PlatformIO port of esp32_firmware/esp32_firmware.ino. The module
 * headers below contain their definitions and are compiled as a single
 * translation unit (exactly as the Arduino IDE concatenated the .ino
 * tabs), so behaviour is identical to the original sketch.
 *
 * Required libraries (see platformio.ini lib_deps):
 *   - ArduinoJson (config-portal /api/state + OTA manifest parsing)
 * The web config portal and aiming-stream server both use the IDF-native
 * esp_http_server (no ESPAsyncWebServer / AsyncTCP).
 */

#include <Arduino.h>
#include <WiFi.h>
#include <WiFiClientSecure.h>
#include <HTTPClient.h>
#include <esp_camera.h>
#include <DNSServer.h>
#include <ESPmDNS.h>
#include <Preferences.h>

#include "soc/soc.h"           // Disable brownout problems
#include "soc/rtc_cntl_reg.h"  // Disable brownout problems
#include "driver/rtc_io.h"
#include "SPIFFS.h"
#include "esp_core_dump.h"     // read the previous crash's saved backtrace on boot
#include "esp_system.h"        // esp_reset_reason()

// --- GPIO assignments (board revision 1.1) ---
#define STM32_RESET_PIN GPIO_NUM_47  // Drives STM32 NRST low to reset the radar MCU
#define STM32_BOOT0_PIN GPIO_NUM_14  // Drives STM32 BOOT0 (HIGH = ROM bootloader) for ESP-driven flashing
#define RX_GPIO 42                   // UART1 RX from STM32 (speed reports)
#define TX_GPIO 41                   // UART1 TX to STM32 (speed query commands)
#define ESP_WAKEUP_PIN GPIO_NUM_1    // STM32 pulls HIGH when motion >= ~5mph is detected
#define STM_WAKEUP_PIN GPIO_NUM_2    // (was the reserved STM_WAKEUP line; now the radar-blank line below)
#define RADAR_BLANK_PIN STM_WAKEUP_PIN  // ESP -> STM32 PA4: HIGH during WiFi bursts so the STM32 discards rail-corrupted FFT frames
#define WIFI_RESET_PIN GPIO_NUM_21   // Active-low button: hold 3s to clear stored WiFi creds

#define CAMERA_PWDN_PIN GPIO_NUM_45  // OV2640 power-down (active high)
#define CAMERA_RST_PIN GPIO_NUM_3    // OV2640 reset (active low)

Preferences preferences;  // NVS-backed key/value store for WiFi creds and user settings

// Post-boot window during which WiFi/portal stays up so the user can reach the
// config page after a reboot; Power-Saver then drops WiFi when idle. (Was
// mistakenly shipped as a 10s debug value -- the trailing "//120000" gave it
// away -- which left almost no window to reach the portal and killed the first
// OTA check before it could run.)
static const unsigned long POST_BOOT_WIFI_GRACE_MS = 120000;

#include "variables.h"
#include "events.h"          // recent-detection ring served by GET /api/events (LAN companions)
#include "diagnostics.h"
#include "camera.h"
#include "camera_stream.h"
#include "radar.h"
#include "api.h"
#include "stm32boot.h"
#include "ota.h"
#include "config_portal.h"

DNSServer dnsServer;  // Captive-DNS used in AP mode so any URL hits the config portal

TaskHandle_t Task0;  // Handle for the Core 0 task (HTTPS uploads / WiFi reconnect)
TaskHandle_t Task1;  // Handle for the Core 1 task (radar polling / sleep / DNS)

// Forward declarations for the dual-core task functions (defined below).
void taskCore0(void* parameter);
void taskCore1(void* parameter);

// The aiming MJPEG stream server lives in its own translation unit
// (camera_stream.cpp). Its desired state is the shared stream_active/
// stream_deadline flags (set by POST /api/stream), and the config page reports
// the live stream URL/state by polling GET /api/state -- so the stream module
// needs no start/stop callbacks wired here anymore.

// --- Crash diagnostics ------------------------------------------------------
// The panic handler saves a core dump to the flash 'coredump' partition on every
// crash, but the native USB-CDC console drops off during the crash so the live
// panic is never seen. Print the saved dump once on the next boot (USB-CDC is
// back by then), then erase it. Decode the printed addresses with:
//   xtensa-esp32s3-elf-addr2line -pfiaC -e .pio/build/esp32-s3/firmware.elf <addr ...>
static void reportLastCrash() {
  if (esp_core_dump_image_check() != ESP_OK) {
    return;  // no valid core dump in flash -> last boot was clean
  }
  Serial.println("!!! ===== PREVIOUS CRASH: core dump found in flash ===== !!!");
#if CONFIG_ESP_COREDUMP_ENABLE_TO_FLASH && CONFIG_ESP_COREDUMP_DATA_FORMAT_ELF
  char reason[200];
  if (esp_core_dump_get_panic_reason(reason, sizeof(reason)) == ESP_OK) {
    Serial.printf("  reason   : %s\n", reason);
  }
  esp_core_dump_summary_t* s = (esp_core_dump_summary_t*) malloc(sizeof(*s));
  if (s != nullptr && esp_core_dump_get_summary(s) == ESP_OK) {
    Serial.printf("  task     : %s\n", s->exc_task);
    Serial.printf("  PC       : 0x%08x  (exccause %u, fault addr 0x%08x)\n",
                  (unsigned)s->exc_pc, (unsigned)s->ex_info.exc_cause,
                  (unsigned)s->ex_info.exc_vaddr);
    Serial.print("  backtrace:");
    for (uint32_t i = 0; i < s->exc_bt_info.depth; i++) {
      Serial.printf(" 0x%08x", (unsigned)s->exc_bt_info.bt[i]);
    }
    Serial.println(s->exc_bt_info.corrupted ? "  (stack corrupted)" : "");
  }
  free(s);
#endif
  Serial.println("  decode   : xtensa-esp32s3-elf-addr2line -pfiaC -e .pio/build/esp32-s3/firmware.elf <PC + backtrace>");
  esp_core_dump_image_erase();  // clear so it prints once per crash, not every boot
  Serial.println("!!! ==================================================== !!!");
}

/**
 * Arduino setup() - runs once on boot/reset.
 *
 * Initializes peripherals, restores user settings from NVS, brings the
 * STM32 radar out of reset, joins WiFi (or starts the configuration AP),
 * launches the web config portal, and finally pins the two work loops to
 * separate cores so radar polling never blocks on HTTPS uploads.
 */
void setup() {
  Serial.begin(115200);
  // On native-USB CDC the port enumerates ~1-2s after reset, so early prints
  // are lost if we don't wait for the host to attach. Bound the wait so the
  // device never hangs when running headless (no monitor) in the field.
  unsigned long serialWaitStart = millis();
  while (!Serial && millis() - serialWaitStart < 2000) { delay(10); }

  Serial.println();
  Serial.println("=== MiniSpeedCam r1.1 (PlatformIO) ===");
  Serial.printf("[BOOT] heap=%u psram=%u\n", (unsigned)ESP.getFreeHeap(), (unsigned)ESP.getFreePsram());

  // GPIO setup
  pinMode(ESP_WAKEUP_PIN, INPUT);
  pinMode(WIFI_RESET_PIN, INPUT_PULLUP);  // Active-low button; enable internal pull-up so the pin idles HIGH (no spurious resets)
  pinMode(STM32_RESET_PIN, OUTPUT);
  pinMode(STM32_BOOT0_PIN, OUTPUT);
  digitalWrite(STM32_BOOT0_PIN, LOW);  // BOOT0 low = STM32 boots from flash (normal run)
  pinMode(RADAR_BLANK_PIN, OUTPUT);
  digitalWrite(RADAR_BLANK_PIN, LOW);  // default: not blanking the radar
  pinMode(CAMERA_PWDN_PIN, OUTPUT);  // Set the camera powerdown pin
  pinMode(CAMERA_RST_PIN, OUTPUT);   // Set the camera reset pin // Causes crash

  // Light Sleep setup
  //esp_sleep_enable_ext0_wakeup(ESP_WAKEUP_PIN, 1);  // Wake up ESP32 when GPIO1 is HIGH //STM will always pull GIO1 high when speeds above 5 mph are detected. Will pull low when speeds

  // Setup Camera. esp_camera_init() can fail transiently on a marginal power
  // rail, so power-cycle and retry a few times rather than booting blind with
  // a dead sensor (which would silently upload empty photos).
  cameraPowerOn();
  bool camera_ok = false;
  for (int attempt = 1; attempt <= 3; attempt++) {
    if (cameraSetup() != 0) { camera_ok = true; break; }
    // The old loop tested cameraSetup() in the while-condition, so on all-fail it
    // ran a 4th init while reporting "3 attempts", and -- worse -- a camera that
    // finally came up on the last try was logged as FAILED. Count each of exactly
    // three attempts here and report success/failure from the actual result.
    Serial.printf("[CAM] init attempt %d/3 failed\n", attempt);
    esp_camera_deinit();  // release any partial init before re-attempting
    delay(250);
    cameraPowerOn();
  }
  if (camera_ok) {
    Serial.println("[CAM] ready");
  } else {
    Serial.println("[CAM] FAILED after 3 attempts; photo capture disabled");
  }

  SPIFFS.begin(true);
  delay(100);

  // load saved variables
  preferences.begin("local", false);
  diagnosticsLogBoot();  // record reset reason + bump persisted boot counter for the Status tab
  otaHealthBootCheck();  // if a just-applied ESP image is crash-looping, revert to the previous slot now
  ssid = preferences.getString("ssid", "NOT_SET");
  password = preferences.getString("pass", "NOT_SET");
  api_base_url = preferences.getString("api_base", API_BASE_URL);  // data destination; user-editable on the Wifi tab (default from config.h)
  rebuildServerEndpoints();  // build the register/capture/camera URLs from api_base_url
  Serial.printf("[API] base URL: %s\n", api_base_url.c_str());
  loadOrCreateIdentity();  // device_token + claim_code: minted once on first boot, reused forever
  min_speed = preferences.getInt("min_speed", 3);             // The minimum speed (MPH) that the tracker should track any vehicle and upload data
  if (min_speed < 1) min_speed = 1;  // 0 would make the run loop `while (speed >= min_speed)` never end (get_speed never returns <0)
  photo_speed = preferences.getInt("photo_speed", 10);        // Cars speed (MPH) when photo should be taken
  min_signal = preferences.getInt("min_signal", 0);           // Min radar echo strength to arm a run (0 = off; proximity gate, see variables.h)
  photo_signal = preferences.getInt("photo_signal", 0);       // Shared fire threshold (direction-aware proximity timing; 0 = off, capture at photo_speed)
  photo_signal_front = preferences.getInt("ps_front", 0);     // FRONT (oncoming) fire threshold; 0 = inherit photo_signal (raise to catch oncoming closer)
  photo_signal_rear = preferences.getInt("ps_rear", 0);       // REAR (receding) fire threshold; 0 = inherit photo_signal (lower to catch receding farther)
  is_kph = preferences.getBool("is_kph", 0);                  // Cars speed (MPH) when photo should be taken
  power_saver = preferences.getBool("power_saver", true);     // true = drop WiFi during idle (default); false = never sleep
  // Installation cosine correction (see variables.h). The !(a && b) form also
  // rejects NaN from a corrupted NVS float, since NaN comparisons are false.
  speed_correction = preferences.getFloat("speed_corr", 1.0f);
  if (!(speed_correction >= 1.0f && speed_correction <= 1.3f)) speed_correction = 1.0f;

  // Connect CDM324 sensor
  Serial.println("Connecting CDM324");
  Serial1.begin(1000000, SERIAL_8N1, RX_GPIO, TX_GPIO);
  Serial.setDebugOutput(false);

  // Reset CDM324
  digitalWrite(STM32_RESET_PIN, LOW);
  issue_cdm324_reset();

  // Read the STM32 firmware version now (before taskCore1 starts polling, so it
  // can't race get_speed() on the shared UART). Retry a few times in case the
  // STM32 is mid-FFT when the first query lands; stays "unknown" on old firmware.
  strlcpy(stm_fw_version, get_stm32_version().c_str(), sizeof stm_fw_version);
  for (int i = 0; i < 3 && strcmp(stm_fw_version, "unknown") == 0; i++) {
    delay(50);
    strlcpy(stm_fw_version, get_stm32_version().c_str(), sizeof stm_fw_version);
  }
  Serial.printf("[FW] esp=%s stm=%s\n", FW_VERSION, stm_fw_version);
  // Connect to WiFi or create Access Point
  connectWifiAP();
  if (WiFi.getMode() == WIFI_STA) {
    Serial.printf("[WIFI] STA ip=%s\n", WiFi.localIP().toString().c_str());
  } else {
    Serial.printf("[WIFI] AP ip=%s\n", WiFi.softAPIP().toString().c_str());
  }

  // Start the self-hosted config portal (esp_http_server on :80). Replaces ESPUI.
  load_config_portal();

  // Send local IP address to API if connected to internet
  sendLocalIP();

  // Keep WiFi/portal up for the post-boot grace window so the user can reach the
  // config page after a reboot; Power-Saver then drops WiFi once idle.
  sleep_time = millis() + POST_BOOT_WIFI_GRACE_MS;
  wake_flag = true;

  // ignore device measurements for 5 seconds after startup
  ignore_time = millis() + 5000;
  ignore_flag = true;

  // Queue used to hand finished tracking runs from Core 1 to Core 0. Depth 2
  // lets a second event arrive while one is still uploading; deeper backlogs
  // are dropped (with a log) in taskCore1.
  uploadQueue = xQueueCreate(2, sizeof(UploadRequest));

  // Crash diagnostics are printed HERE, near the end of setup, on purpose: on
  // native USB-CDC the host monitor only reattaches a few seconds into boot, so
  // anything printed at the very top is missed. By now it's reliably connected.
  // This reveals why the previous boot ended -- BROWNOUT (5V rail dip, leaves no
  // core dump) vs PANIC/TASK_WDT (code fault, with a backtrace) vs a clean reset.
  esp_reset_reason_t last_reset = esp_reset_reason();
  Serial.printf("[DIAG] last reset: %s (code %d)\n", resetReasonStr(last_reset), (int)last_reset);
  reportLastCrash();

  Serial.printf("[BOOT] setup complete (heap=%u); starting tasks\n", (unsigned)ESP.getFreeHeap());

  xTaskCreatePinnedToCore(
    taskCore1,  // Task function
    "Task1",    // Name of the task
    10000,      // Stack size in words
    NULL,       // Task input parameter
    1,          // Priority of the task
    &Task1,     // Task handle
    1           // Core where the task should run
  );

  /* Place the network/upload task on core 0 */
  xTaskCreatePinnedToCore(
    taskCore0,  // Task function
    "Task0",    // Name of the task
    20000,      // Stack size in words
    NULL,       // Task input parameter
    1,          // Priority of the task (0 is lowest)
    &Task0,     // Task handle
    0           // Core where the task should run (0 or 1)
  );
}

/**
 * Arduino loop() - intentionally empty.
 *
 * All recurring work is performed in taskCore0 and taskCore1, which are
 * pinned to separate cores via xTaskCreatePinnedToCore() in setup().
 */
void loop() {
  // All recurring work runs in taskCore0/taskCore1 (pinned in setup()); this
  // Arduino loopTask has nothing to do. Park it rather than spin: an empty loop()
  // leaves loopTask permanently READY at priority 1 on core 1 -- the SAME core and
  // priority as taskCore1 -- so the two round-robin and the radar task gets only
  // ~half the core for no benefit. Blocking yields the core to taskCore1 and lets
  // the idle task run (lower power). Kept alive (not vTaskDelete) so any Arduino
  // serialEvent plumbing still ticks.
  vTaskDelay(pdMS_TO_TICKS(1000));
}

unsigned long previousMillis = 0;  // Timestamp of last idle-sleep tick
const long interval = 5000;        // Idle window (ms) of zero-speed before sleeping

// A run only starts after this many consecutive readings >= min_speed. A lone
// noise spike that slips under the plausibility ceiling (see get_speed) lasts
// a single sample, so requiring 2 in a row rejects glitches while a real
// vehicle (many samples) still triggers immediately.
const int SPEED_CONFIRM_COUNT = 2;

// Direction-aware photo timing fallback: if a car never cleanly crosses
// photo_signal during its run, still fire once magnitude has fallen to this
// percent of the run's peak -- a best-effort "near closest approach" shot.
const int PHOTO_PEAK_DROP_PCT = 70;

// Failsafe cap on a single tracking run. A real vehicle clears the beam in a few
// seconds; a run that lasts this long is sustained noise (a vibrating reflector
// reads as a steady ~20mph) or misconfiguration. Finalize what was measured and
// re-arm rather than let the inner loop wedge taskCore1 -- a wedged loop stops
// servicing the WiFi-reset button, the aiming stream, captive-DNS, and OTA.
const unsigned long MAX_RUN_MS = 60000;
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

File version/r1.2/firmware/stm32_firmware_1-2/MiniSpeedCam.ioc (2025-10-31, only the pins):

Mcu.UserName=STM32F301K8Ux
PA10.Signal=USART1_RX
PA2.Signal=USART2_TX
PA3.Signal=USART2_RX
PA5.Signal=GPIO_Output
PA9.Signal=USART1_TX
PB0.GPIO_Label=DOPPLER
PB0.Signal=ADC1_IN11

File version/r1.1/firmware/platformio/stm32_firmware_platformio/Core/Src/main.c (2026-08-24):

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
/* Includes ------------------------------------------------------------------*/
#include "main.h"
#include "fatfs.h"

/* USER CODE BEGIN Includes */
#include <string.h>
#include <stdio.h>
#include <stdarg.h>
#include <math.h>
#include "user/defines.h"
#include "user/ascii_lib.h"
#include "arm_math.h"

/* USER CODE END Includes */

/* USER CODE BEGIN PD */

// Firmware version reported to the ESP32 over UART on the 'v' command. The
// ESP-driven OTA flow reads this to decide whether this MCU needs reflashing.
// Bump on every STM32 firmware release. Build-flag overridable so release CI can
// stamp it from the git tag (-DSTM_FW_VERSION=\"1.0.4\") and keep the published
// manifest's stm_version consistent with the binary it ships.
#ifndef STM_FW_VERSION
#define STM_FW_VERSION "1.0.4"
#endif

#define DOPPLER_Pin GPIO_PIN_0
#define DOPPLER_GPIO_Port GPIOB

/* --- Noise-robustness tuning (shared 5V rail / ESP32 WiFi interference) --- */
/* ADC sample rate, Hz (64MHz/128/(1.5+12.5)); used to convert a bin to Hz. */
#define ANALOG_SAMPLE_RATE_HZ   35714.0f
/* Minimum peak-to-noise-floor ratio for a frame to count as a detection.
 * Measured floor: idle/noise peaks ride at a ratio of ~6-13 (snrx10 60-130),
 * while a real Doppler tone (2048Hz fork) towers at ~70-195 (snrx10 700-1950).
 * 15 sits in the wide gap: idle reads 0, real targets pass easily. Tunable. */
#define ANALOG_MIN_SNR          15.0f
/* Transient rejection (impulsive WiFi-burst noise): count the samples that
 * deviate more than ANALOG_TRANSIENT_SIGMA from the frame mean, and only
 * discard the frame once at least ANALOG_TRANSIENT_MIN_BAD of them are out. A
 * clean -- or even a clipping -- tone stays within ~1.4 sigma so it is never
 * counted. Deliberately lenient (a single stray sample no longer nukes a
 * frame): the per-frame SNR test above is the main noise gate. */
#define ANALOG_TRANSIENT_SIGMA  6.0f
#define ANALOG_TRANSIENT_MIN_BAD 32
/* Lowest FFT bin considered a real target. Bins 1-2 sit right against DC and
 * catch huge impact/drift artifacts (seen at mag >400k), so the search starts
 * above them. remove_low_freqs raises this further to ~10 (a min-speed gate). */
#define ANALOG_MIN_BIN          3

/* Detection debounce: the minimum number of *valid* (non-zero) detections that
 * must be present in the 32-frame rolling window before a non-zero speed is
 * emitted. The median deliberately ignores no-target zeros (so a brief real
 * pass isn't swallowed -- see analog_buffer_median), but that alone lets a
 * SINGLE false detection latch the output for the whole ~0.9s window: e.g. one
 * transient harmonic off a vibrating / rattling reflector that momentarily
 * clears the SNR gate. Requiring several detections first rejects such
 * isolated / transient spikes while still catching a real target, which dwells
 * in the beam for many ~29ms frames and fills the window easily. Raise toward
 * the window size (32) for more aggressive vibration rejection; lower it to
 * catch very brief passes. */
#define ANALOG_MIN_VALID_DETECTIONS 5

/* --- Doppler-to-speed conversion (24.125 GHz CDM324) --------------------- *
 * A target moving at v produces a Doppler shift f_d = 2*v*f0/c. The FFT peak
 * bin is first turned into that frequency in Hz (bin * ANALOG_SAMPLE_RATE_HZ /
 * N, see analog_compute_fft_on_cplted_sequence), then into speed with the
 * factors below. BOTH unit factors are derived from ONE physical constant so
 * the 'm' and 'k' replies can never drift apart -- they must stay in the exact
 * 1.60934 mph<->km/h ratio. The previous hand-tuned literals (0.1449275 mph,
 * 0.2262295 kph) did NOT: they implied two different radar frequencies (23.14
 * vs 23.86 GHz) and over-reported by +4.3% / +1.1%, always high (the accusatory
 * direction). NOTE: this changes every reported speed by 1-4%; re-verify on the
 * tuning-fork bench (a 2048 Hz tone must read 28.5 mph / 45.8 km/h, and the two
 * units must agree through the 1.609 conversion) before releasing. */
#define CDM324_F0_HZ            24.125e9f
#define SPEED_OF_LIGHT_MPS      299792458.0f
#define DOPPLER_HZ_PER_MPS      (2.0f * CDM324_F0_HZ / SPEED_OF_LIGHT_MPS)   /* 160.945 */
#define MPS_PER_MPH             0.44704f
#define MPS_PER_KPH             (1.0f / 3.6f)
/* Reply carries speed*10, so factor = 10 / (Doppler Hz per unit). */
#define FFT_HZ_TO_MPH_X10       (10.0f / (DOPPLER_HZ_PER_MPS * MPS_PER_MPH))  /* 0.138988 */
#define FFT_HZ_TO_KPH_X10       (10.0f / (DOPPLER_HZ_PER_MPS * MPS_PER_KPH))  /* 0.223680 */

/* USER CODE END PD */

ADC_HandleTypeDef hadc1;
DMA_HandleTypeDef hdma_adc1;

UART_HandleTypeDef huart1;
UART_HandleTypeDef huart2;

/* USER CODE BEGIN PV */

// Define to enable current transient test
//#define CUR_TRANSIENT_TEST

volatile uint16_t analog_result_buffer1[1024];
volatile uint16_t analog_result_buffer2[1024];
/* Pointer objects themselves are volatile (not just the pointed-to data): they
 * are reassigned in the DMA ISR (analog_trigger_conversion) and read in the main
 * loop, so the compiler must re-load them each access, not cache across the loop. */
volatile uint16_t * volatile analog_cur_adc_dest_buf_pt;
volatile uint16_t * volatile analog_cplt_adc_dest_buf_pt;
volatile BOOL analog_fdma_transfer_started;
volatile BOOL analog_adc_train_done_flag;
arm_rfft_fast_instance_f32 analog_fft;
float32_t analog_temp_float_array[1024];
float32_t analog_rfft_output[1024];
uint16_t analog_last_peak_indexes[32];
uint16_t analog_cur_peak_fill_idx = 0;

/* Per-frame diagnostics, dumped over USART2 (CH340 debug header) when enabled
 * (lets us see why a frame was rejected without an external probe). */
volatile uint16_t analog_dbg_peak_bin = 0;
volatile uint32_t analog_dbg_peak_mag = 0;
volatile uint32_t analog_dbg_floor_mean = 0;
volatile uint16_t analog_dbg_bad_count = 0;
volatile uint8_t analog_dbg_dropped = 0;
volatile uint8_t analog_dbg_blanked = 0; /* frame discarded due to WiFi-busy line */

/* ADC/DMA overrun detector. HAL_ADC_ConvCpltCallback sets this if the main loop
 * had not yet consumed the previous frame (analog_adc_train_done_flag still TRUE)
 * when the next DMA train completed and the buffers were swapped: the frame the
 * main loop is about to read is being overwritten by the ADC DMA -- a torn splice
 * of two frames -- so the FFT path discards it (holds the median) instead of
 * emitting a false peak from it. analog_overrun_count trends the rate. */
volatile uint8_t  analog_overrun_flag = 0;
volatile uint32_t analog_overrun_count = 0;
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

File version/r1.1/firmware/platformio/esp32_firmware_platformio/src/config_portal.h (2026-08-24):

/**
 * config_portal.h - Self-hosted web configuration portal (replaces ESPUI).
 *
 * Serves the device's configuration page from the IDF-native esp_http_server
 * on port 80 -- the same stack the aiming-stream module already uses
 * (camera_stream.cpp on port 81). Dropping ESPUI lets us drop the whole
 * ESPAsyncWebServer / AsyncTCP stack, whose cross-core WebSocket broadcasts
 * were the source of the rev-1.1 freeze under WiFi load; here the browser
 * *pulls* a JSON snapshot instead of the firmware pushing from Core 1.
 *
 * Because ESPUI/ESPAsyncWebServer are gone, esp_http_server.h no longer clashes
 * with anything in the main translation unit (the old HTTP_* enum collision was
 * async-vs-IDF), so this can be a plain header compiled into main.cpp with
 * direct access to the globals / preferences / diagnostics helpers -- exactly
 * as espui_settings.h was.
 *
 * Endpoints (all on port 80):
 *   GET  /              -> the single-page config UI (CONFIG_HTML, from flash)
 *   GET  /api/state     -> JSON snapshot of live values + current settings
 *   GET  /api/events    -> recent-detection ring (speed + age) for LAN companions
 *   POST /api/settings  -> device settings (units, speeds, signals); applied live
 *   POST /api/wifi      -> SSID / password / API base URL; persisted then reboot
 *   POST /api/clear     -> wipe WiFi credentials then reboot (into the setup AP)
 *   POST /api/stream    -> start/stop the aiming MJPEG stream
 *
 * The page polls /api/state ~1 Hz to refresh the live readouts (speed, signal,
 * heap, uptime, ...), so there is no server-side push and no per-control state.
 */
#pragma once

#include <Arduino.h>
#include <WiFi.h>
#include <ArduinoJson.h>
#include <esp_random.h>   // esp_random(): mints the per-boot portal CSRF token
#include <string.h>       // strchr/strlen for the request-auth checks
#include "esp_http_server.h"

// Compose the installed-firmware version string (ESP is compile-time; STM is
// read over UART at boot and can change after an STM auto-flash). Reported in
// /api/state and shown on the Status section.
static String firmwareVersionText() {
  return String("ESP ") + FW_VERSION + "  /  STM " + stm_fw_version;
}

// ---------------------------------------------------------------------------
// The config page. One self-contained document (inline CSS/JS, no CDN) so it
// renders fully in AP mode during first-time setup, when there is no internet.
// Live values are read-only spans refreshed by polling /api/state; the form
// inputs are populated once on first load so a refresh never clobbers typing.
// esp_http_server does no template substitution, so literal '%' (e.g. CSS
// width:100%) needs no escaping.
// ---------------------------------------------------------------------------
static const char CONFIG_HTML[] PROGMEM = R"HTML(<!doctype html>
<html lang=en>
<head>
<meta charset=utf-8>
<meta name=viewport content="width=device-width,initial-scale=1">
<meta name=csrf content="__CSRF__">
<title>MiniSpeedCam</title>
<style>
:root{--bg:#0f1115;--card:#1a1d24;--fg:#e6e8eb;--mut:#9aa0a6;--acc:#3b82f6;--ok:#22c55e;--bd:#2a2e37}
*{box-sizing:border-box}
body{margin:0 auto;max-width:560px;padding:16px;background:var(--bg);color:var(--fg);font:15px/1.45 system-ui,-apple-system,Segoe UI,Roboto,sans-serif}
h1{font-size:20px;margin:8px 0 2px}
.sub{color:var(--mut);font-size:13px;margin-bottom:16px}
.card{background:var(--card);border:1px solid var(--bd);border-radius:12px;padding:16px;margin-bottom:16px}
.card h2{font-size:13px;margin:0 0 12px;text-transform:uppercase;letter-spacing:.05em;color:var(--mut)}
label{display:block;margin:10px 0}
label>span{display:block;font-size:13px;color:var(--mut);margin-bottom:4px}
input[type=text],input[type=password],input[type=number]{width:100%;padding:9px 10px;background:#0c0e12;border:1px solid var(--bd);border-radius:8px;color:var(--fg);font-size:15px}
.switch{display:flex;align-items:center;justify-content:space-between;gap:12px}
.switch>span{margin:0}
.row{display:flex;justify-content:space-between;align-items:center;padding:7px 0;border-bottom:1px solid var(--bd)}
.row:last-child{border-bottom:0}
.row .k{color:var(--mut);font-size:13px}
.row .v{font-variant-numeric:tabular-nums;font-weight:600}
button{width:100%;padding:11px;border:0;border-radius:8px;background:var(--acc);color:#fff;font-size:15px;font-weight:600;cursor:pointer;margin-top:12px}
button.warn{background:#3a2326;color:#f87171;border:1px solid #5b2a2e}
.big{font-size:34px;font-weight:700;text-align:center;margin:2px 0}
.claim{text-align:center;color:var(--ok);font-weight:600;min-height:1.2em}
.muted{color:var(--mut);font-size:12px;margin-top:6px;word-break:break-all}
.stream{display:none;width:100%;max-width:320px;margin-top:10px;border-radius:8px;background:#000;aspect-ratio:4/3}
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

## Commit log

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2026-01-09 Refactor photo function and update sleep logic
    Renamed takeSendPhoto() to sendPhoto() for clarity and updated all references. Commented out light sleep and related code in esp32_firmware.ino for version 1.1, replacing sleep with Wi-Fi disconnect and power-saving logic. Updated PCB project filename and STEP file path in KiCad project. Removed obsolete lock file. Replaced README.md with a project-specific title.
    [api.h, esp32_firmware.ino]
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2026-05-08 Fix bugs in ESP32 v1.2 firmware
    - api.h: reserve() was called on the wrong String (httpsRequestData
    instead of httpsRequestSend), forcing many reallocations during the
    ~100KB photo upload payload build.
    - api.h: release photo_base64 after upload so the buffer doesn't sit
    on the heap until the next capture.
    - api.h: round maxSpeed -> speed_actual to keep the wire format integer
    now that maxSpeed is float.
    - api.h: wifiResetButton() now stores "NOT_SET" sentinels (matches
    buttonClearNetworkCall) rather than literal "ssid"/"pass".
    - radar.h: fix get_speed() race - the original checked available()
    before the STM32 could reply, so each cycle returned the previous
    query's data (or "N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
    [api.h, esp32_firmware_1-2.ino, radar.h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]
2026-05-08 Remove unused globals from ESP32 v1.2 firmware
    Dropped twelve unused globals from variables.h (API_photo,
    photo_finished, sleep_idle_time, send_alert, lastTime, labelWifi,
    display_wifi, button1, switchOne, status, apIP, DNS_PORT) and the
    write-only send_API (along with its sole assignment in the main
    sketch). The DNS_PORT/apIP pair was apparently intended for a
    captive-portal dnsServer.start() that is never called; the
    processNextRequest() loop is therefore a no-op, but that is left
    for a separate fix.
    https://claude.ai/code/session_01AfFtNmP3SFYS9HwhkkhR54
    [esp32_firmware_1-2.ino, variables.h]
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2026-05-08 Robustness pass on ESP32 v1.2 firmware
    Five high-impact items from the firmware review:
    - AP-aware idle teardown. The grace-window and 5s-idle paths in
    taskCore1 unconditionally called WiFi.disconnect/WIFI_OFF, which
    killed the soft-AP while a user might still be configuring WiFi
    via the captive portal. Both paths now skip the teardown when
    WiFi.getMode() == WIFI_AP.
    - Task watchdog. Both pinned tasks (Core 0 / Core 1) are now
    subscribed to the task WDT with a 30s timeout (covers the 5s
    HTTPS connect/read budgets and the 3s wifiResetButton blocking
    poll). The inner while(speed >= min_speed) tracking loop also
    heartbeats so a long pass can't trip the watchdog.
    - WiFi password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
    [api.h, camera.h, esp32_firmware_1-2.ino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]
2026-05-08 Upload every pass above min_speed, not just photo runs
    send_data was only being raised inside the photo-capture branch, so
    passes that crossed min_speed but never reached photo_speed - and
    passes where takePhoto() failed - never triggered Core 0's upload.
    The non_speeding endpoint was effectively dead.
    Drop the inline send_data assignment and raise send_data once at the
    end of the tracking run. send_photo (already gated on photo_captured)
    still selects between the speeding and non_speeding endpoints, so
    photo passes upload to /speeding_capture and the rest upload to
    /non_speeding_capture with just the speed.
    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
    [esp32_firmware_1-2.ino]
2026-05-08 Bound CDM324 banner read; add ArduinoOTA support
    issue_cdm324_reset() previously spun forever waiting for a newline
    from the STM32. Because it runs from setup() before either pinned
    task subscribes to the watchdog, a dead or unprogrammed STM32 wedged
    the boot with no recovery. Add a 1000ms millis-based bound and log
    the timeout instead of hanging.
    Also wire up ArduinoOTA so the firmware can be updated without USB.
    setupOTA() runs after sendLocalIP() and only enables OTA in STA
    mode - the AP fallback is for first-time setup, not for OTA. The
    auth password is the same MAC-derived per-device password used for
    the soft-AP and ESPUI basic auth, so a LAN attacker can't push
    arbitrary firmware. ta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
    [api.h, esp32_firmware_1-2.ino, radar.h]
2026-05-08 Move API bearer token to NVS
    The minispeedcam.com Bubble.io workflow token was hardcoded in api.h
    (twice), so rotating it required reflashing every fielded device.
    Token is now loaded from NVS in setup() with the original baked-in
    value as the default fallback, so existing deployments keep working
    without manual configuration. A new "API Token" text input on the
    WiFi Settings tab lets the operator rotate it from the portal; on
    Save we persist to NVS and reboot, picking up the new value via
    sendLocalIP() and sendPhoto().
    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
    [api.h, esp32_firmware_1-2.ino, variables.h]
2026-05-08 Add live Status tab to ESPUI portal
    The portal previously had no read-only surface, so debugging a
    device in the field meant USB serial. The new Status tab (added as
    the first tab so it's the landing page) shows live telemetry that
    covers the most common questions:
    - Current Speed - radar reading per polling cycle, in the configured
    unit (mph/kph).
    - Last Run Max - peak speed of the most recent tracking pass.
    - Last Upload - "OK (200)", "Failed (-1)", "Uploading...", or "No
    uploads yet". Reads httpsResponseCode and sending_data.
    - WiFi - SSID and RSSI when STA-connected, "AP mode" during initial
    setup, "Radio off" when the idle path has powered the radio down.
    - Uptime - h/m/s since b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
    [esp32_firmware_1-2.ino, variables.h]
2026-05-08 Use struct-based esp_task_wdt_init on Arduino-ESP32 3.x / IDF 5
    esp_task_wdt_init's signature changed between Arduino-ESP32 2.x
    (IDF 4: timeout_seconds + bool panic) and 3.x (IDF 5: const
    esp_task_wdt_config_t*). The previous commit used the 2.x form,
    which fails to compile on IDF 5.x toolchains:
    error: too many arguments to function
    'esp_err_t esp_task_wdt_init(const esp_task_wdt_config_t*)'
    Switch to a #if ESP_IDF_VERSION_MAJOR >= 5 guard so both core
    versions build. The 5.x branch fills out the config struct with
    timeout_ms = 30000, idle_core_mask = 0 (we manually subscribe our
    two pinned tasks), trigger_panic = true.
    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
    [esp32_firmware_1-2.ino]
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2026-05-21 Add offline queue, diagnostics & upload resiliency
    Introduce offline delivery, runtime diagnostics, and several robustness/usability improvements.
    Key changes:
    - Add LittleFS-backed offline queue (queue.{cpp,h}) and .gitignore for PlatformIO artifacts.
    - Add diagnostics module (diagnostics.{h,cpp}) to record reset reason, boot count, last upload code and formatted uptime.
    - Refactor api: extract apiUploadEventFromMemory(), add optional CA pinning, start NTP sync, rate-limiting, and queue-on-failure logic. Drain queue on WiFi reconnect and periodically from taskCore0.
    - Camera: persist JPEG quality/frame size in NVS, add cameraPowerOff()/On flow and warmup frames, expose getters/setters for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
    [api.cpp, api.h, camera.cpp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]
2026-06-02 Add PlatformIO ESP32 firmware (r1.1)
    Introduce a complete PlatformIO project for the MiniSpeedCam ESP32 firmware r1.1. Adds project metadata (.gitignore, .vscode/extensions.json, platformio.ini) and a README with build/board/dependency notes. Adds source files under src/: main.cpp, api.h, camera.h, config.h, espui_settings.h, radar.h, variables.h implementing the dual-core design (Core 1: radar/polling/ESPUI, Core 0: WiFi/HTTPS uploads), OV2640 camera init/capture, ESPUI web UI with NVS persistence, WiFi/AP/captive portal logic, and streaming base64 upload (StreamingUploadBody) to avoid buffering large JPEGs in heap. platformio.ini pins libs (ESPUI, esp32async/AsyncTCP) and documents board/p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
    [api.h, camera.h, main.cpp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]
2026-06-02 Add diagnostics, ESPUI Status tab & power-saver
    Introduce runtime diagnostics and power-management UI: add diagnostics.h (reset reason, boot count, last upload code, uptime formatting) and persist/track boot/upload state. Add Power-Saver Mode (persisted, volatile flag) and wiring in variables.h, espui_settings.h and main.cpp so the radar task can drop/reconnect WiFi on idle; expose a new Status tab in the ESPUI with live heap/PSRAM/uptime/RSSI/IP/last upload/reset reason/boot count and update helpers (updateSpeedDisplay/updateStatusDisplay). Improve logging across camera, upload, run, wifi and boot paths for easier debugging and telemetry (api.h, camera.h, main.cpp). Document the Web UI, pow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
    [api.h, camera.h, main.cpp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]
2026-06-02 Enhance WiFi AP/station handling and power
    Enable native USB CDC in platformio.ini and add robustness and safety around WiFi and power behaviors across api.h and main.cpp. Changes include:
    - platformio.ini: enable ARDUINO_USB_MODE and ARDUINO_USB_CDC_ON_BOOT so Serial uses on-chip CDC.
    - api.h: cleanly teardown STA before starting soft-AP (WiFi.disconnect + WIFI_OFF), check softAPConfig(), retry softAP() up to 3 times and log failures to avoid silent AP startup failures.
    - api.h: prevent connectWifi() from switching to STA when no credentials are stored (ssid == "NOT_SET"), preserving the soft-AP for user configuration.
    - api.h: rework wifiResetButton() to be non-blocking using millis() and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
    [api.h, main.cpp]
2026-06-02 Lower WiFi TX, debounce radar, rate-limit uploads
    Reduce WiFi transmit power to mitigate RF interference with the CDM324 radar front-end (WIFI_TX_POWER set to WIFI_POWER_11dBm and WiFi.setTxPower called in STA/AP paths). Add client-side upload rate limiting (3s minimum interval) to drop back-to-back capture events and avoid tripping server limits or blocking Core 0; timestamp is committed only when an upload is actually sent. Improve radar robustness: require two consecutive over-threshold speed samples to start a run (debounce), flush serial RX before requests, wait up to 50ms for the STM32 reply, scale the received value, and reject implausible readings (negative or >250) as noise. Small l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
    [api.h, main.cpp, radar.h]
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2026-06-03 Add radar detection debounce to reject vibration false readings
    A vibrating/rattling reflector (e.g. a speaker+foil playing a low tone)
    produces micro-Doppler harmonics that can momentarily land in a high FFT
    bin and clear the SNR gate. Because analog_buffer_median() excludes
    no-target zeros, that single false detection became the only non-zero
    sample and latched a wrong speed (~20 mph at bin 40) for the full ~0.9s
    median window.
    Add ANALOG_MIN_VALID_DETECTIONS: require a minimum number of valid
    detections in the 32-frame rolling window before emitting a non-zero
    speed. An isolated/transient spike is now ignored, while a real target
    (which dwells in the beam for many ~29ms frames) fills the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
    [main.c]
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2026-06-11 esp32: add aiming MJPEG video stream for setup/mounting
    A temporary, time-limited (5 min auto-off) MJPEG feed from the OV2640,
    toggled by an ESPUI switcher, so the installer can frame the device on a
    phone (http://<ip>:81/). taskCore1's streamService() reconciles the
    desired-state flags (stream_active/stream_deadline) against the real
    server; the radar/photo path pauses while it runs.
    The server uses esp_http_server, whose HTTP_GET/POST/... enum collides
    with ESPUI's ESPAsyncWebServer when both land in one translation unit, so
    the implementation lives in its own camera_stream.cpp that does not
    include ESPUI; it reports start/stop to main.cpp via callbacks that drive
    the ESPUI label/switcher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
    [camera_stream.cpp, main.cpp, variables.h]
2026-06-11 esp32: append MAC suffix to device name so two units coexist
    mDNS, the STA hostname and the soft-AP SSID all came from a single fixed
    HOSTNAME ("MiniSpeedCam"), so two MiniSpeedCams on one network collided:
    both claimed MiniSpeedCam.local and mDNS would auto-rename one. Derive a
    per-device name "MiniSpeedCam-XXXXXX" from the low 3 bytes of the factory
    MAC (the NIC-specific half; the high 3 are Espressif's shared OUI) via a
    new cached deviceHostname() helper, and route all three identity uses
    through it. The efuse MAC is read once and needs no WiFi to be up.
    [api.h]
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2026-06-11 esp32: fix aiming-stream freeze + camera flip, add crash diagnostics
    Follow-up fixes to the aiming MJPEG stream:
    - Freeze fix: the stream hung the whole device after ~30s. taskCore1 pushed
    ESPUI label updates every loop (updateSpeedDisplay / updateStatusDisplay =
    ~8 WebSocket broadcasts/sec over AsyncTCP); under the stream's WiFi/LWIP load
    those sends blocked, hanging the task -- radar, serial, stream AND ESPUI all
    stalled until TCP timed out. Suppress those updates while streaming, and pause
    radar polling too (the reads are meaningless and WiFi-TX-corrupted during
    aiming) so taskCore1 stays light. Diagnosed from reset reason ESP_RST_USB plus
    a steady heap/current, which ruled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
    [camera.h, camera_stream.cpp, main.cpp]
2026-06-11 Harden ESP32<->STM32 UART link and add STM32 watchdog
    Protect the speed link against the board's known RF/supply noise and make
    the STM32 fail safe rather than run broken.
    - Checksummed speed reply: STM32 now answers 'm'/'k' with "<int>*<CK>\r\n"
    (CK = XOR of the value's ASCII digits). ESP get_speed() reads the full
    line and rejects any checksum mismatch. Catches corruption that stays
    in-range and would slip past the plausibility ceiling (e.g. 29 -> 79 mph).
    - STM32 command RX is now interrupt-driven into a ring buffer, with a
    HAL_UART_ErrorCallback that clears overrun/framing errors and re-arms RX,
    so a noise byte during the ~2.4ms FFT can't overrun the FIFO-less USART
    and perm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
    [main.c, radar.h]
2026-06-11 Add WiFi-TX radar blanking handshake (ESP GPIO2 -> STM32 PA4)
    Attack the shared-rail noise at its source. The ESP repurposes its spare
    GPIO2<->PA4 link to tell the STM32 when it's mid WiFi burst, so the STM32
    drops the corrupted frames instead of inferring them from statistics.
    - ESP drives RADAR_BLANK_PIN (GPIO2) HIGH for the duration of each WiFi
    burst it controls -- sendUpload, sendLocalIP, connectWifi, connectWifiAP
    -- via a depth-counted RadarBlankGuard so nested calls stay asserted
    until the outermost scope exits.
    - STM32 reads PA4 (input, pull-down) at the top of each FFT frame and, when
    high, discards the frame (holds the previous median, skips the FFT). A
    direct "contamin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
    [api.h, main.c, main.cpp]
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2026-06-11 esp32: fix WiFi-reset leaving the device in a reconnect loop
    Holding the WiFi-reset button cleared the stored credentials to the literal
    strings "ssid"/"pass" -- but the firmware treats anything other than the
    "NOT_SET" sentinel as real credentials, so after a reset taskCore1 kept
    requesting reconnects and connectWifi() tore the config soft-AP back down to
    retry the bogus network, looping forever. The AP never stayed up long enough
    to reconfigure.
    - Reset now clears creds to "NOT_SET" so the reconnect / AP-stay guards bail
    and the device stays cleanly in AP mode.
    - connectWifiAP() skips the STA attempt entirely when unconfigured ("NOT_SET"
    or empty), so a fresh / just-reset device boots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
    [api.h]
2026-06-15 Add radar proximity gate to reject distant cross-traffic (r1.1)
    The CDM324 picks up distant cross-traffic that passes the speed/SNR
    checks and falsely triggers the camera. The STM32 already computes the
    FFT peak magnitude (received power ~1/r^4, a proximity proxy) but only
    forwarded the speed. Now it forwards the magnitude too, and the ESP32
    gates run-arming on a user-tunable minimum.
    STM32: uart_reply_speed() emits "<speed>,<mag>*<CK>\r\n" (checksum over
    the full payload); 'k'/'m' handlers pass the clamped peak magnitude
    (mag=0 when the SNR gate fails).
    ESP32: get_speed() parses the magnitude into g_last_peak_mag (cleared on
    every reject path; backward-compatible with replies lacking the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
    [main.c, main.cpp, radar.h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]
2026-06-17 Direction-aware photo timing: capture both traffic directions by plate
    Currently the photo fires at the first frame past photo_speed, which (cosine
    error) is when the car reads fastest = farthest, so plates come out too far.
    Time the shot on PROXIMITY instead, using the echo magnitude the proximity
    gate already streams (g_last_peak_mag, ~1/r^4).
    With the unit aimed down the road, magnitude RISES for an oncoming car and
    FALLS for one going away. So fire at the first crossing of a new `photo_signal`
    threshold: an UP crossing => oncoming, grab the FRONT plate on approach; a DOWN
    crossing => receding, grab the REAR plate as it pulls away. Same proximity,
    opposite flank of the pass -- the "two t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
    [main.cpp, variables.h]
2026-06-17 esp32: don't fire a bogus REAR-plate photo on a dropped/corrupt radar reply
    The direction-aware photo timing reads g_last_peak_mag to detect proximity
    crossings. But get_speed() forces that magnitude to 0 whenever the STM32 has
    no fresh sample or the reply fails its checksum -- both documented-common on
    this noisy shared-rail board. The crossing detector read a 0 as "echo fell to
    zero" => a DOWN-crossing => it fired a spurious "REAR (receding)" capture and
    latched photo_taken, ending the run on a single line-noise glitch with a
    mis-framed frame.
    A 0 means "no valid target this sample," not a real flank. So for proximity
    timing, ignore zero-magnitude samples and hold prev_above across the dr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
    [main.cpp, radar.h]
2026-06-18 esp32/stm32: radar telemetry + heartbeat + per-direction photo thresholds
    UART protocol: STM32 appends FFT peak SNR (x10) as a third reply field
    ("speed,mag,snr"); the ESP parses it into g_last_peak_snr. The field is
    optional both ways, so old/new firmware interoperate.
    Per-event telemetry: each capture upload now carries direction
    (approaching/receding), peak magnitude, peak SNR, mean speed, frame
    count, and run duration, so readings can be tuned and analysed in Bubble.
    Device heartbeat: sendLocalIP() now also reports RSSI, free/min-free
    heap, uptime, reset reason, boot count, and rejection counters, and runs
    every 60s from Core 0 (not just once at boot) so the runtime fields are
    actually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
    [api.h, main.c, main.cpp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]
2026-06-20 esp32/stm32: over-the-air firmware updates (ESP self-OTA + ESP-driven STM32 flash)
    Manual-approve OTA, triggered from the device web UI, for both MCUs.
    Foundation:
    - Repartition to a dual-app 8 MB table (partitions_8mb_ota.csv) so the ESP can
    write a new image to the inactive slot and flip on reboot. NVS offset is
    unchanged, so stored WiFi creds/settings survive the one-time wired migration.
    - FW_VERSION build flag (ESP) and a 'v' UART command (STM32) report versions;
    the ESP reads the STM32 version at boot and both go out in the heartbeat.
    ESP32 self-OTA (ota.h):
    - Web-UI buttons set an atomic request flag; taskCore0 does the work so the
    AsyncTCP/ESPUI loop never blocks. Check pos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
    [partitions_8mb_ota.csv]
2026-06-22 esp32: per-device identity replacing shared key + camera_id
    Replace the shared Bearer token + user-pasted camera_id with a runtime
    per-device identity, so one firmware image flashes to every unit (no
    per-unit build).
    - Identity: device_token (32-hex from esp_random) and claim_code (6-char
    A-Z/2-9) minted once on first boot and persisted in NVS; never regenerated.
    - Boot registration: register_device (trust-on-first-use, idempotent) with
    exponential backoff, driven from taskCore0 after WiFi STA connects.
    - Uploads / heartbeat / firmware_check now send device_token instead of
    camera. A capture {"status":"ok"} marks the device claimed (hides the
    claim code); an empty {} (unclaimed / ov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
    [api.h, main.cpp, variables.h]
2026-06-22 esp32: keep config AP up when boot STA fails
    When boot STA association failed, the device fell back to the soft-AP
    config portal -- but radar motion then set connect_wifi and connectWifi()
    switched the radio to STA to retry, tearing the portal down and stranding
    the device with neither STA nor AP (hit in the field with a disconnected
    antenna / unreachable network: the AP appeared, then vanished).
    Add ap_fallback_mode, set in connectWifiAP() when the boot STA attempt
    fails and cleared on STA success. While set, both the taskCore1 reconnect
    trigger and connectWifi() leave the portal up instead of chasing an
    unreachable STA; a reboot re-attempts STA. The happy path (boot STA
    success) and the p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
    [api.h, main.cpp, variables.h]
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2026-06-22 firmware: throttle heartbeat to 10 min and harden OTA version check
    - Heartbeat interval 60s -> 10 min to cut WiFi-TX bursts (battery drain and
    radar interference during transmit).
    - otaCheck() now separates "a different version is offered but no download URL
    was given" (server-side misconfig -> "no URL") from "up to date" (-> "ok"),
    and logs the raw firmware_check response body for fast diagnosis.
    - FW_VERSION set to 1.0.1.
    [main.cpp]
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2026-06-22 hardware(r1.3): clean up r1.3 design files
    Remove the stale gerber export set (Gerber/ and Gerber.zip, which were
    plotted with the wrong 'lightspeed_r1' project name) and update the
    board, schematic, and project-local settings.
    [MiniSpeedCam-r1.3.kicad_pcb, MiniSpeedCam-r1.3.kicad_sch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]
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2026-06-22 feat(firmware): infer pass direction from echo-energy centroid
    Replace the first-vs-last magnitude compare with a magnitude-weighted echo-index centroid over the whole run, and add a mag_trend (0-100) telemetry field forwarded by sendUpload. Using every echo makes the direction fallback robust to single noisy readings, where the prior two-sample compare could flip. Run-end log now reports trend.
    [api.h, main.cpp, variables.h]
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2026-06-23 firmware: bump ESP + STM version to 1.0.3
    Release the echo-energy centroid direction inference (1bcb6f1), which
    was committed after the 1.0.2 bump without its own version bump and so
    never shipped. Deployed 1.0.2 units still run the flip-prone first-vs-last
    direction compare (approaching cars mislabeled receding); 1.0.3 ships the
    centroid that is robust to single noisy readings and starts reporting the
    mag_trend telemetry field.
    ESP: FW_VERSION 1.0.2 -> 1.0.3 (platformio.ini)
    STM: STM_FW_VERSION 1.0.2 -> 1.0.3 (parity; no functional change)
    [main.c]
2026-06-24 feat(firmware): self-update from GitHub Releases + release CI
    Devices poll the public repo's /releases/latest, read a manifest.json asset
    (per-MCU versions + .bin URLs + MD5s) and auto-apply any strictly-newer image
    while idle, with a health-check/rollback watchdog. Replaces the old manual
    Bubble OTA buttons.
    - ota.h: GitHub manifest fetch + version compare + ESP/STM install paths.
    - config.h: GitHub owner/repo, OTA cadence/health knobs, and pinned CA roots
    for the api.github.com + *.githubusercontent.com chains (MD5-verified too).
    - stm32 main.c: STM_FW_VERSION made build-flag overridable so CI can stamp it
    from the git tag, keeping the manifest consistent with the shipped binary.
    - .g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
    [api.h, main.c, main.cpp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]
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

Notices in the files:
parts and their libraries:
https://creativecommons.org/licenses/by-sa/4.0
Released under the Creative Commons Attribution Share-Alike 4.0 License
